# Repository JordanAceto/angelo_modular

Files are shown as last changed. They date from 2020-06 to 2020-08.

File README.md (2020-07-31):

## Custom 5u format modular synth with 12 modules

pics

### Contains:
- VCO with 5-pulser waveshaper
- VCO with two sub-oscillators
- VCO with LFO range switch
- Voltage controlled wavefolder plus ring-modulator
- Voltage controlled filter with swapable filter-core plug-in boards
- Dual late MS20 style voltage controlled filter
- MIDI to CV plus audio input processor
- Dual 3-input DC coupled mixer
- Modulation source with voltage controlled LFO, sample-and-hold, and white noise source
- Dual Serge style slope generator
- Dual ADSR
- Dual VCA
- +/- 12 volt power supply

### User manuals can be found in the `/user_manuals/` directory. This directory also contains a document outlining any pcb kludges or changes to the current system.

### Documentation for the pcbs is in the `/pcb_docs/` directory

#### Documentation for each pcb consists of the following:
- A very brief README outlining the basics of the pcb

- `/construction_docs/` subdirectory which contains:
  - Gerbers for the circuit board
  - An interactive BOM which can be opened in a web browser
  - A pdf schematic

- `/kicad_docs/` subdirectory which contains the files needed to edit the schematic and pcb layout with kicad

- `/pics/` subdirectory which contains a few rendered pictures of the pcb for reference

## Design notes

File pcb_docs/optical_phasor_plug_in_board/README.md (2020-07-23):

# Optical Phasor Plug-In Board

Small 6 stage optical phase shifter PCB, designed to plug into a larger motherboard.

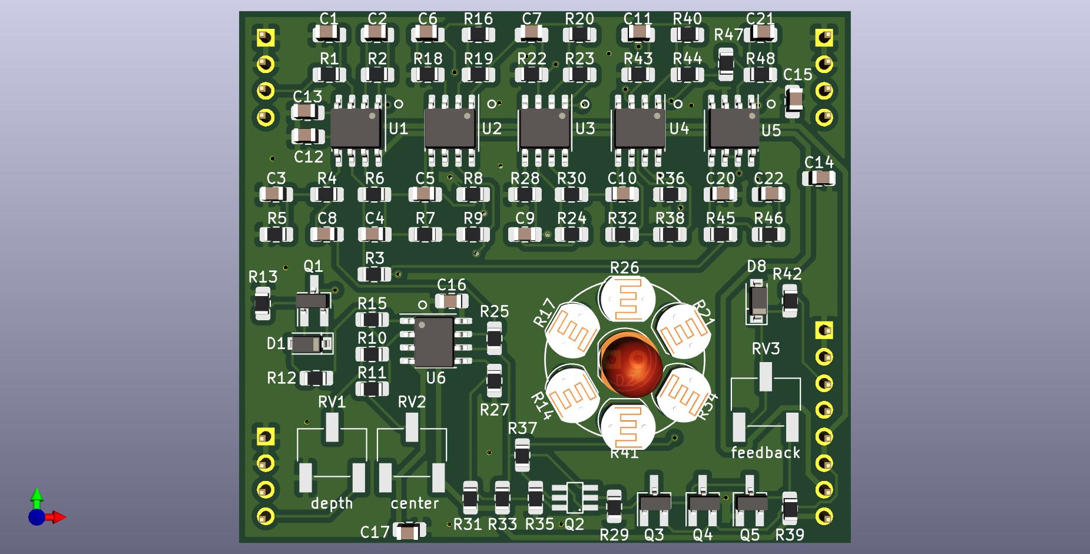
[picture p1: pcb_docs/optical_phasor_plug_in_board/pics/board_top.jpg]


## Details

The main circuit is based on the famous Mutron phasor circuit with the addition of voltage controlled feedback. This PCB includes the audio path and CV inputs for frequency and feedback, but does not include any modulation sources.

The intended use for this board is to plug in to a larger motherboard which contains slots for two of these phasor boards, as well as modulation sources, panel controls, and input/output routing. This motherboard could accept different filter boards sharing this footprint and header layout, for realizing stereo effects of various flavors.

## Inputs

-Audio in: dry audio input to be phase shifted.

-Frequency CV in: 0 volts to +2.048 volts, higher voltage = higher sweep.

-Feedback CV in: 0 volts to +2.048 volts, higher voltage = more feedback.

## Outputs

-Audio out: phase shifted audio output.

## Power Supply Requirements

A bipolar 12 volt power supply capable of supplying 50mA is needed. This will typically come from the motherboard.

## Note About The Light Dependent Resistors

Low on resistance and high off resistance are desirable if a wide sweep range is wanted. Slow/fast response is up to personal taste.

The choice of LED has a large impact on sweep depth. Diffused green LEDs were found to produce good results, but feel free to experiment.

The LED and surrounding LDRs should be protected from ambient light under an opaque cover.

## Calibration

-RV1 (depth trim): trims the depth of incoming frequency CV signals. Turn CW for greater depth and CCW for less depth. Adjust to taste.

-RV2 (center trim): trims the center frequency of the phase shifter. Turn CW for higher center frequency and CCW for lower center frequency. Adjust to taste.

-RV3 (feedback trim): trims the maximum amount of feedback. Turn CW for more maximum feedback and CCW for less maximum feedback. Exercise caution when adjusting this, as extreme settings can result in loud oscillations which could damage your ears or speakers if you are monitoring the sound with a loud amplifier. If you set this trimmer to be right on the edge of oscillation when about +2 volts is applied to the feedback CV input then make sure to sweep the frequency through its entire range, as a setting that doesn't squeal at certain frequency settings may squeal at other settings.

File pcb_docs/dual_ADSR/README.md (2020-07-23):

# Dual ADSR module.

## ADSRs are generated digitally using an stm32 microcontroller. This module is split into three main components:

- The stm32 breakout board contains the pcb with the stm32 microcontroller.

- The ADSR carrier board holds the potentiometers and has a port for the stm32 breakout board.

- The firmware directory has an STM32CubeIDE project structure with the current code. Good starting points to check out the code are in `/firmware/Core/ADSR_lib` and `firmware/Core/Src/main.c`

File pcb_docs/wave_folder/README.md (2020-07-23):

# Wavefolder

The wavefolder is a unique waveshaping circuit that creates "folded" versions of sloping input waveforms.

CV inputs for folds, shape, and offset are included.

A bonus ring-modulator circuit is included, to maintain compatability with the old module.

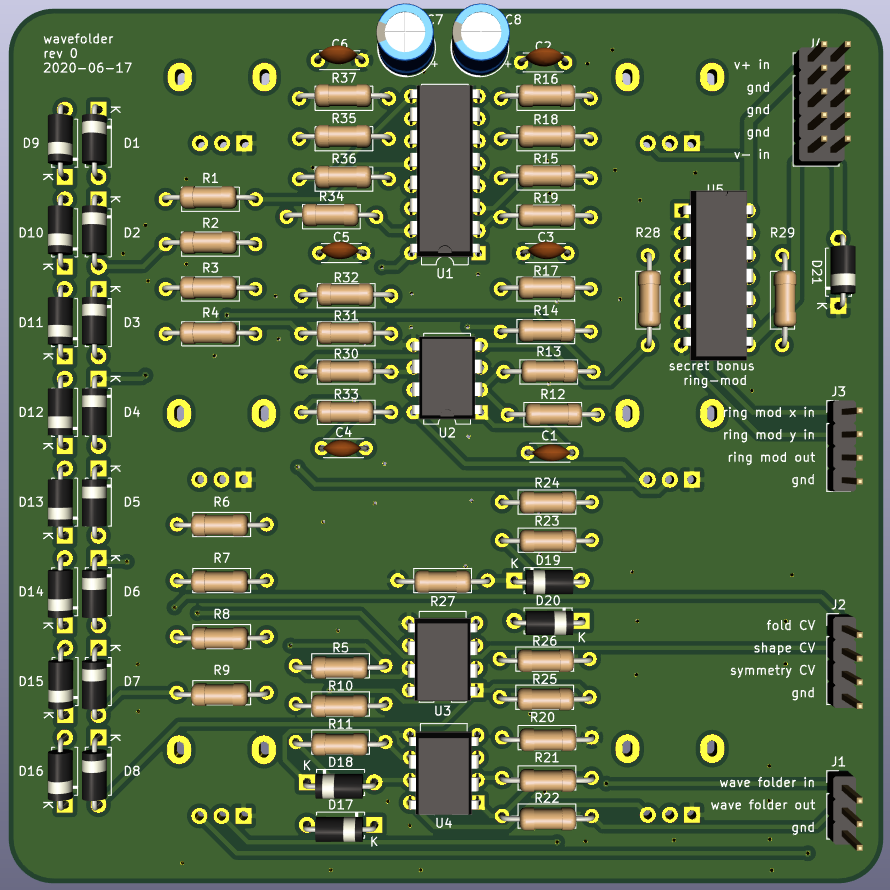
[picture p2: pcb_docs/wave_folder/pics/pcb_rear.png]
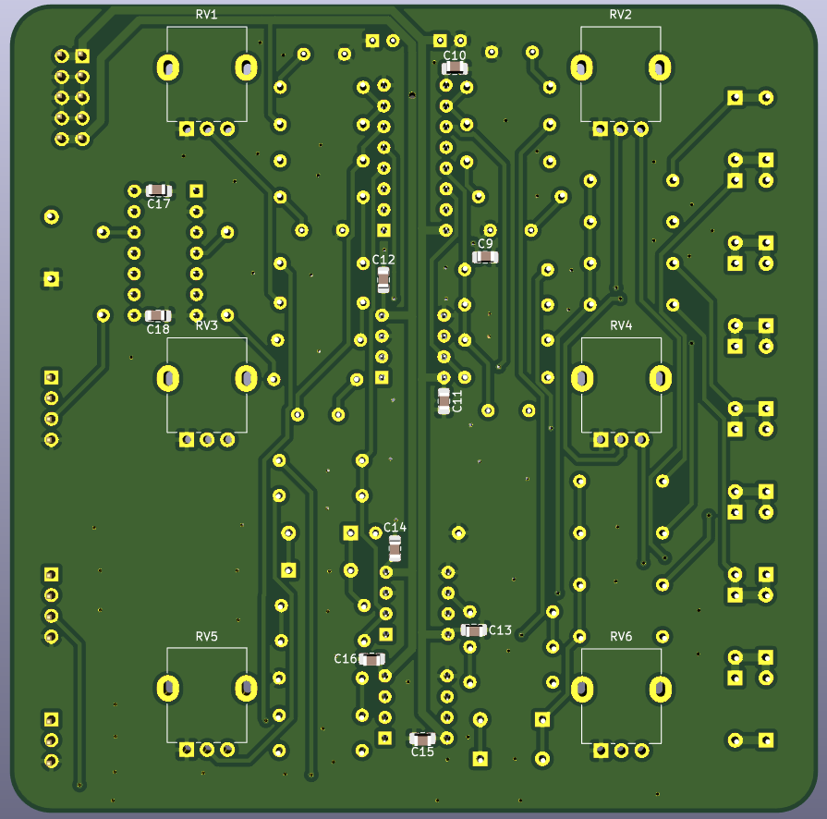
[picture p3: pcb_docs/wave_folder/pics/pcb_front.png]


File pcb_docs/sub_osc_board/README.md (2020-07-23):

# Sub-Oscillator auxilliary waveshaper

Small aux waveshaper pcb intended to be used with the oscillator carrier boards.

Contains two sub-oscillator circuits cascaded in series, for -1 octave and -2 octaves. Triangle, sawtooth, and variable width pulse waves are available for all octaves.

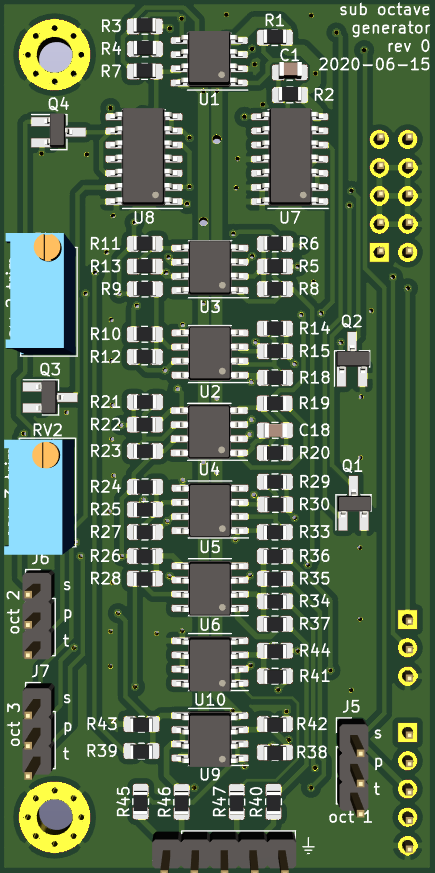
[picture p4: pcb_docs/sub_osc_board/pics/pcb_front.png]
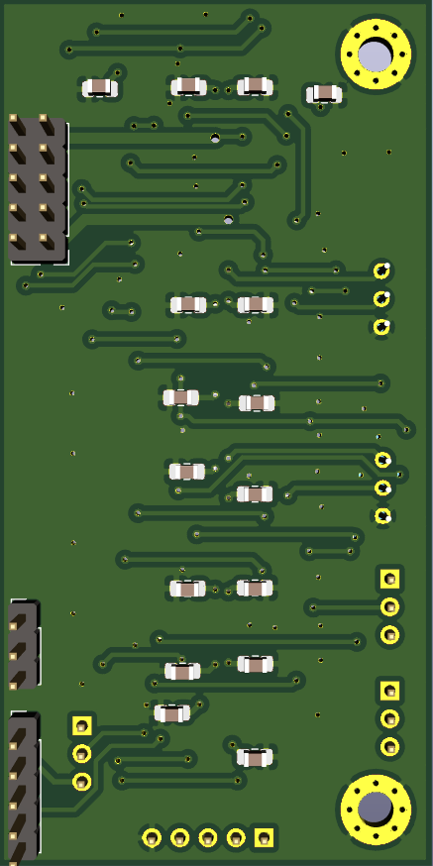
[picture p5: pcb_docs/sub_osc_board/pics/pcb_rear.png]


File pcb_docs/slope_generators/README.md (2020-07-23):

# Slope Generators

PCB with two Serge-stlye slope generators

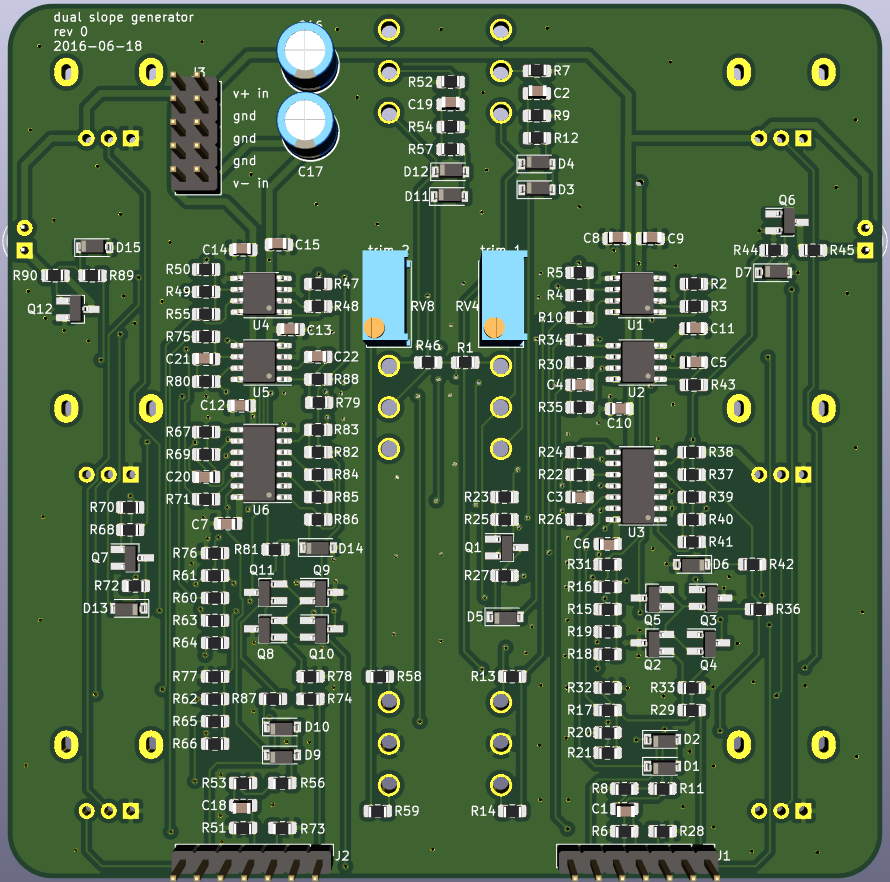
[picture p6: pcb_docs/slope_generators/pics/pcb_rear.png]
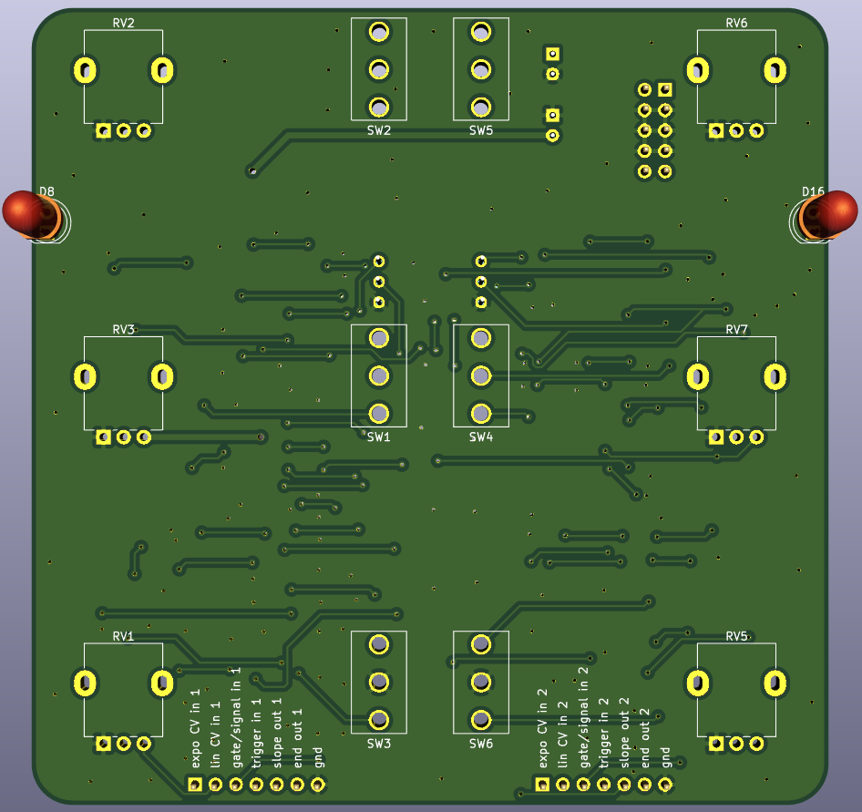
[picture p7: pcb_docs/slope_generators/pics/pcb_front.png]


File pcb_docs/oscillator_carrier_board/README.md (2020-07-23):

# VCO carrier board

Motherboard pcb for oscillators. Contains a port for a VCO core and a port for auxilliary waveshapers, and an octave switch.

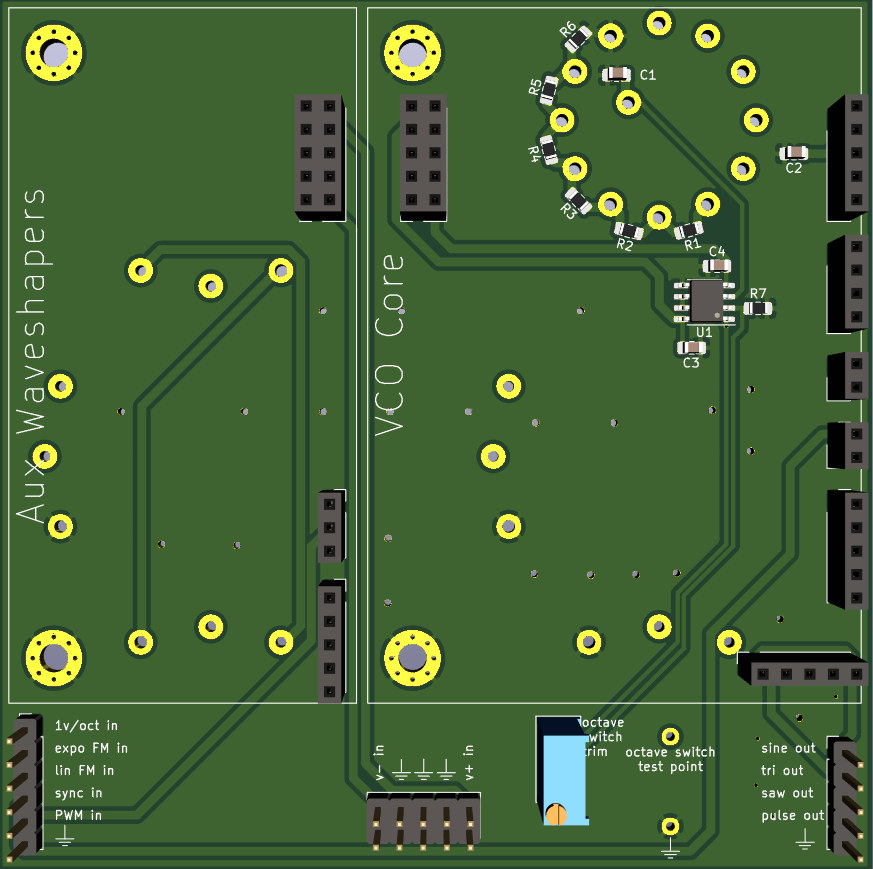
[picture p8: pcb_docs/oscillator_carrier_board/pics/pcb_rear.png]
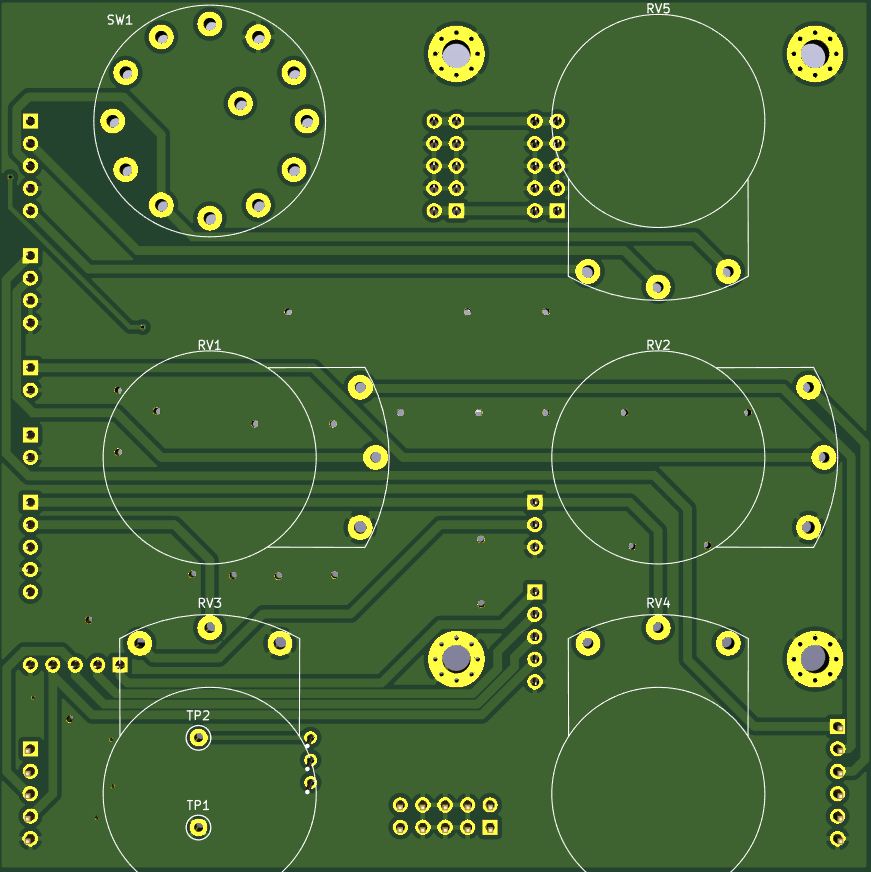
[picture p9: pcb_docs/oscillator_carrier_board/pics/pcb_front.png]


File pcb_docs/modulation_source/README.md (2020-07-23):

# Modulation Source

PCB with a voltage controlled LFO, sample-and-hold, and white noise source.

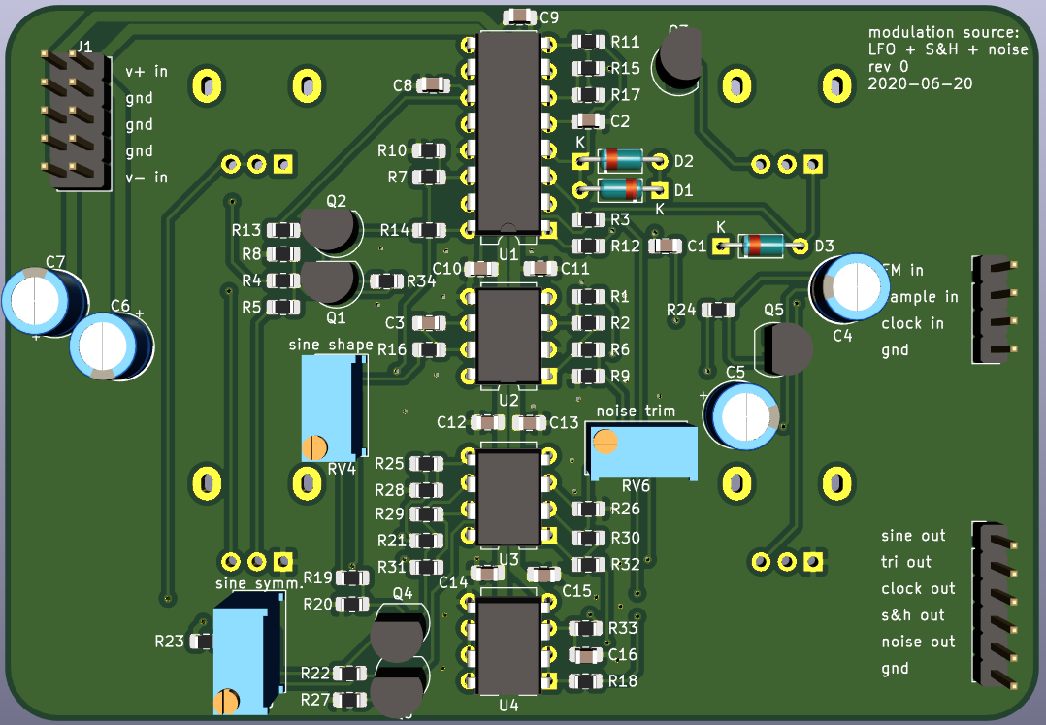
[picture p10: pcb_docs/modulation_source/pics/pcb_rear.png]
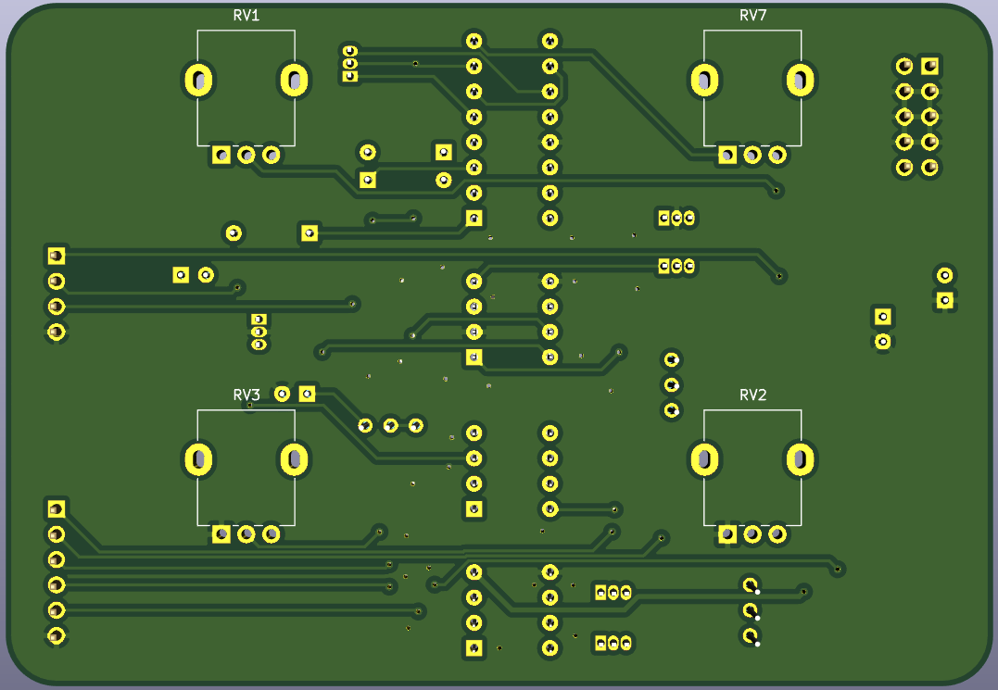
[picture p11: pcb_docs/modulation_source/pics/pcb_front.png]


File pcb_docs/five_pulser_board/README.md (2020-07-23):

# 5-Pulser auxilliary waveshaper board

Small aux waveshaper pcb intended to be used with the oscillator carrier boards.

The 5-pulser is a unique pulse shaper that takes in sloping wave inputs and outputs a stream of between 1 and 5 pulses. The typical input is sawtooth waves.

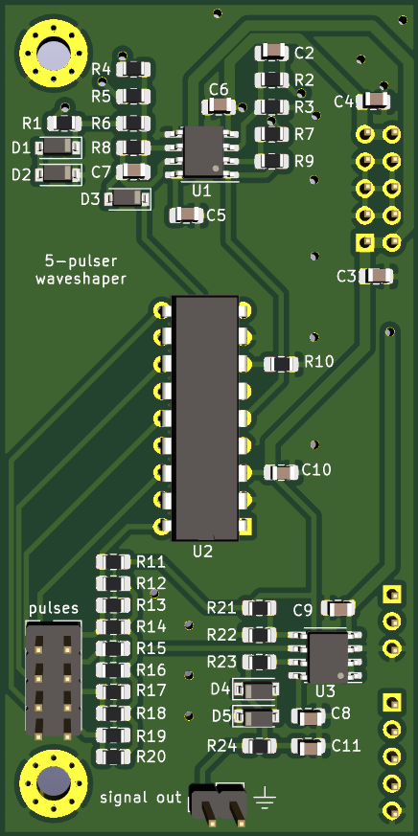
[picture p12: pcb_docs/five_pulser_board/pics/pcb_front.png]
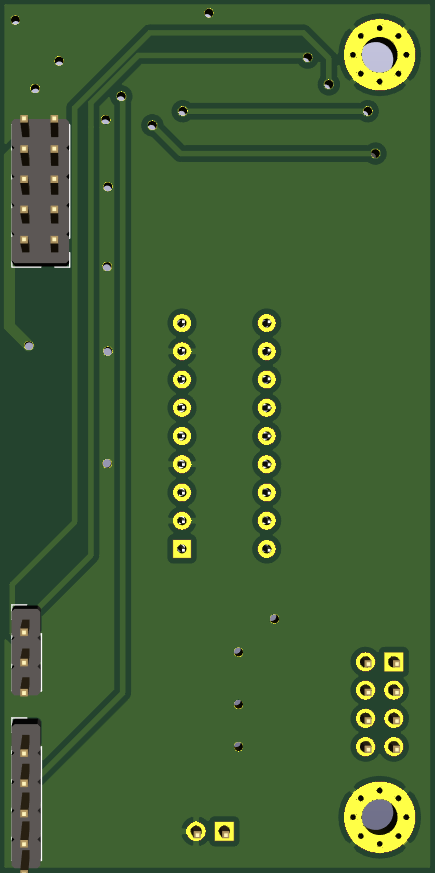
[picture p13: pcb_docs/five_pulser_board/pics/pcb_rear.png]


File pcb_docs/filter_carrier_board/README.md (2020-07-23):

# Voltage Controlled Filter carrier board

PCB which houses various VCF "plug-in" boards. This pcb contains a 3-input signal mixer and 3-input CV mixer, as well as inputs and outputs for the plug-in board port. 

The plug-in boards must conform to the electrical and mechanical interface defined by this pcb. 

Plug-in boards must accept a CV range of 0v to +2.048v, and a feedback CV range of 0v to +2.048v.

See the CEM3320 VCF and optical phasor documents for examples of plug-in boards.

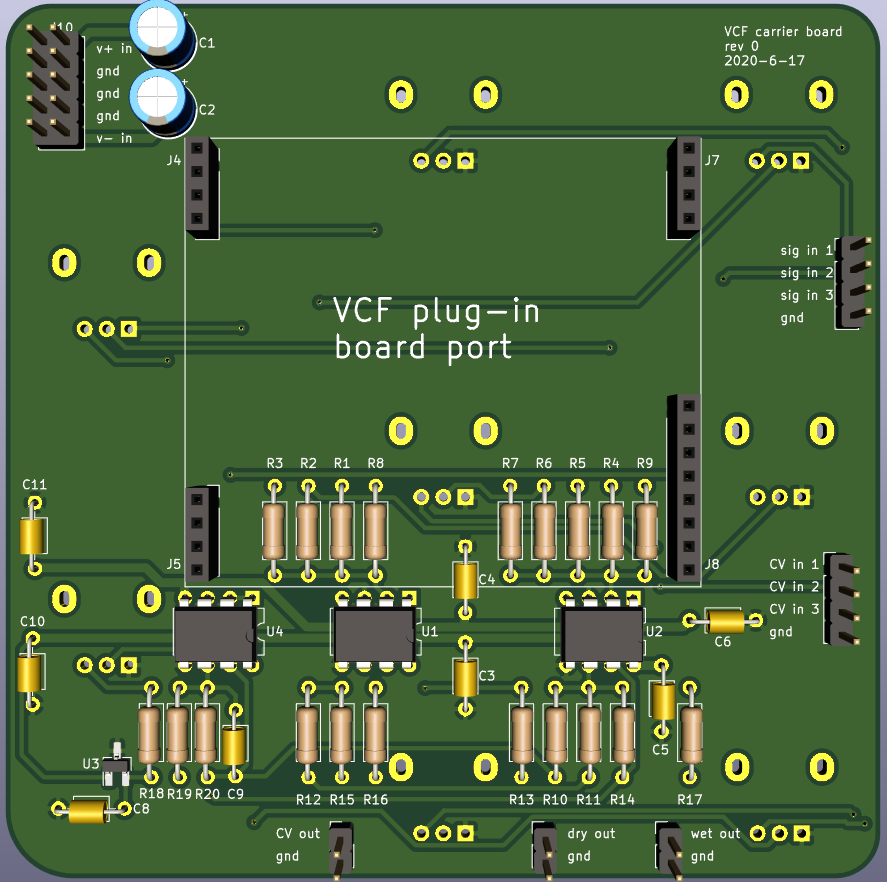
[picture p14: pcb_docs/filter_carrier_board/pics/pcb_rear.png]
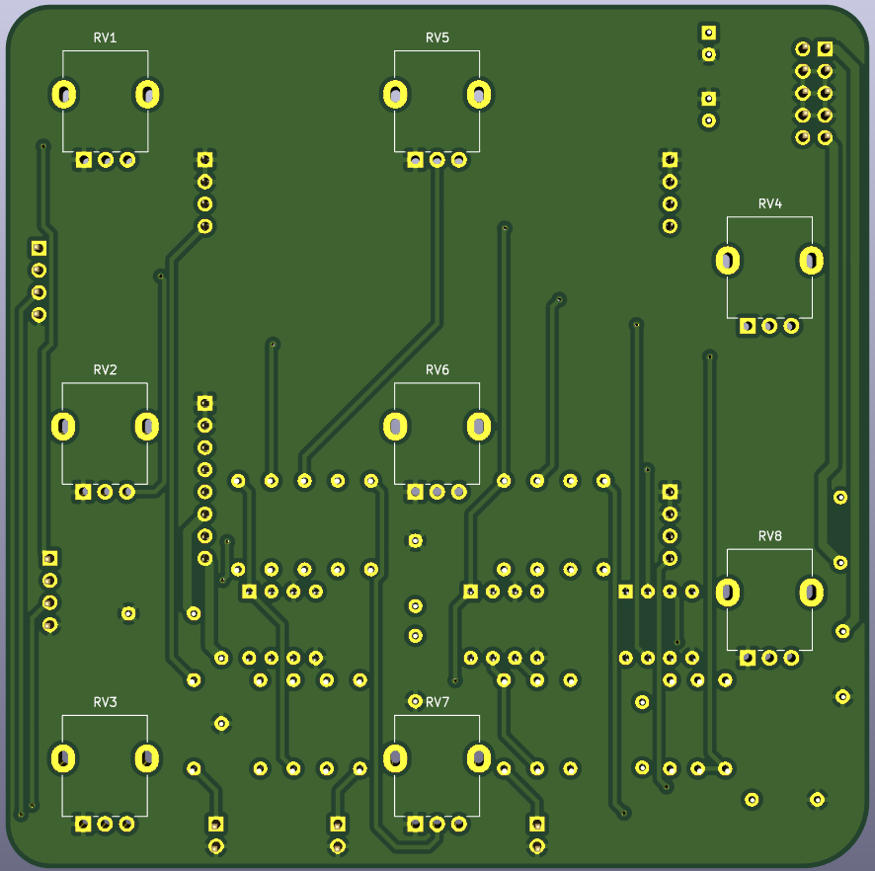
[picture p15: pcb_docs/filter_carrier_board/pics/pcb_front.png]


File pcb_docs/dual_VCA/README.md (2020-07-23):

# Dual linear VCA

PCB with two independendent SSM2164 linear Voltage Controlled Amplifiers.

CV range: 0 volts to +5 volts. Maximum attenuation at 0 volts and unity gain at +5 volts.

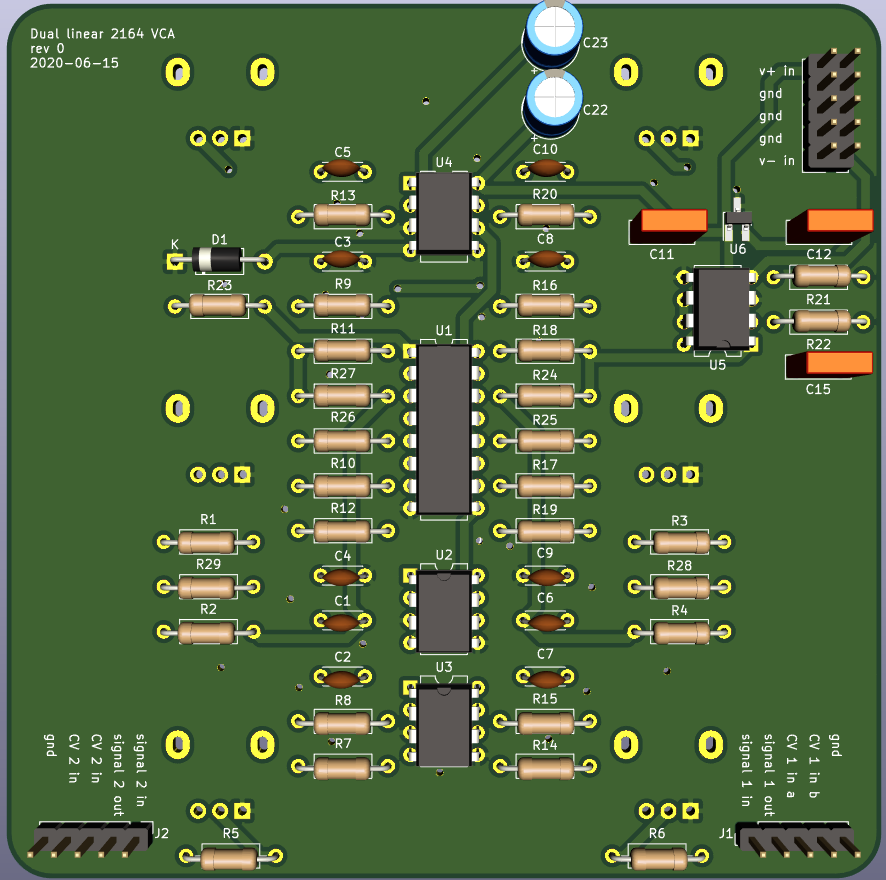
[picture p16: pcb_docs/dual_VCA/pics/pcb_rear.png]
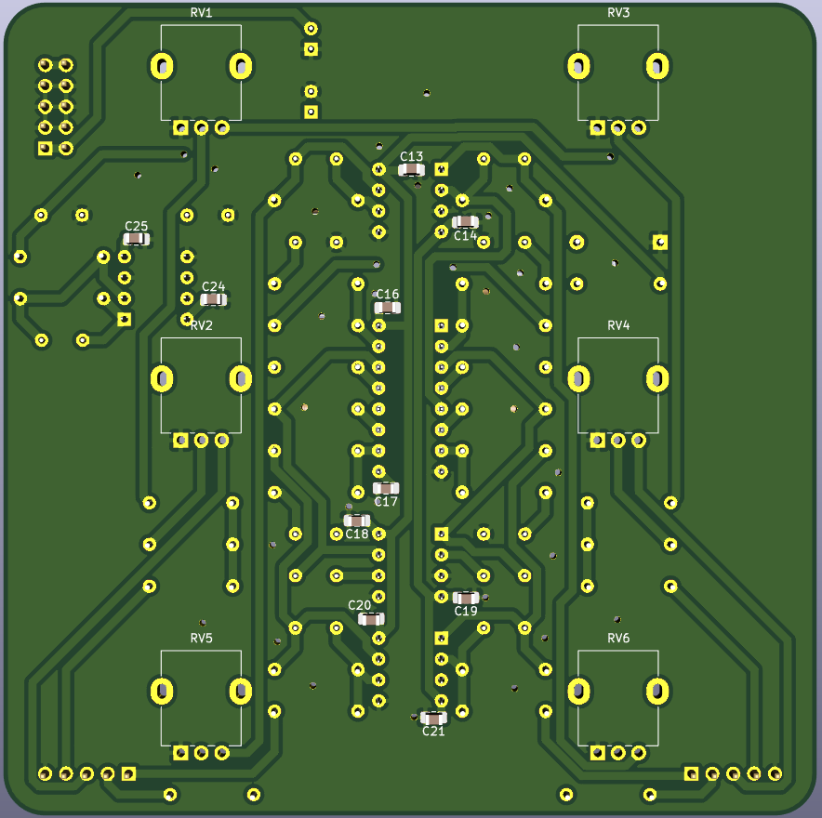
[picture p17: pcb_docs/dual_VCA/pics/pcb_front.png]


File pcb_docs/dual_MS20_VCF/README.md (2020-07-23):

# Dual MS20 style Voltage Controlled Filter

PCB with two independendent late MS20 style VCFs, one configured as a high-pass filter and one configured as a low-pass filter.

An extra summing amplifier is provided to create a parallel HPF/LPF response. Series HPF into LPF response is easily achived with switching jack normalization.

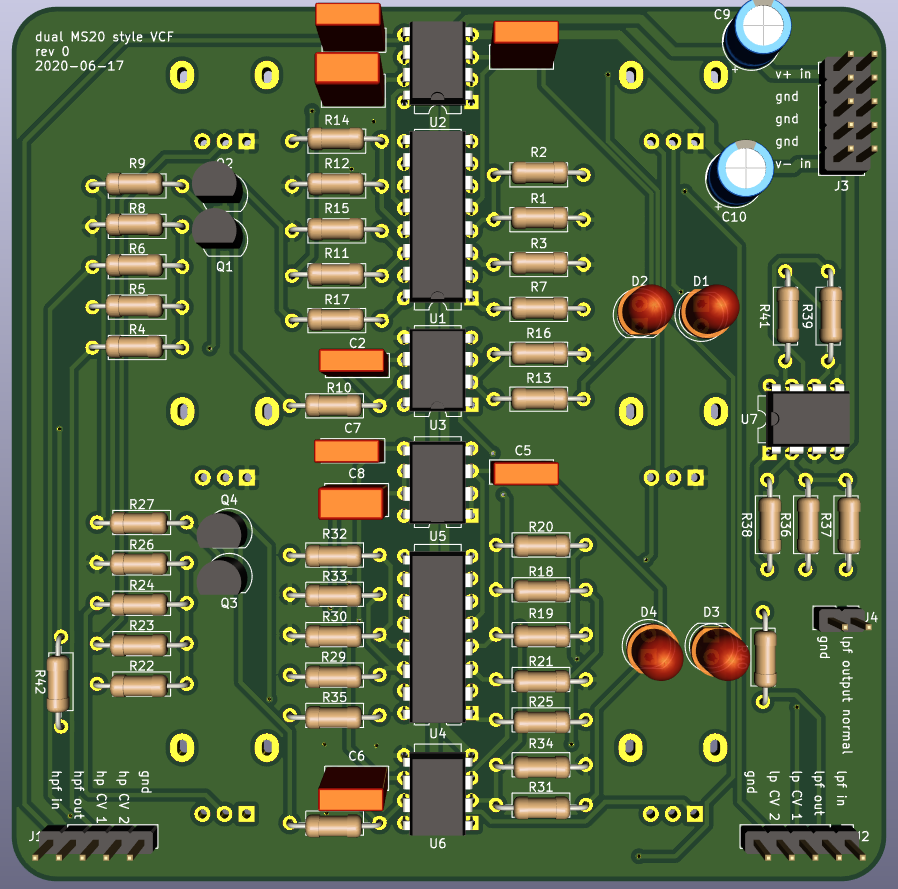
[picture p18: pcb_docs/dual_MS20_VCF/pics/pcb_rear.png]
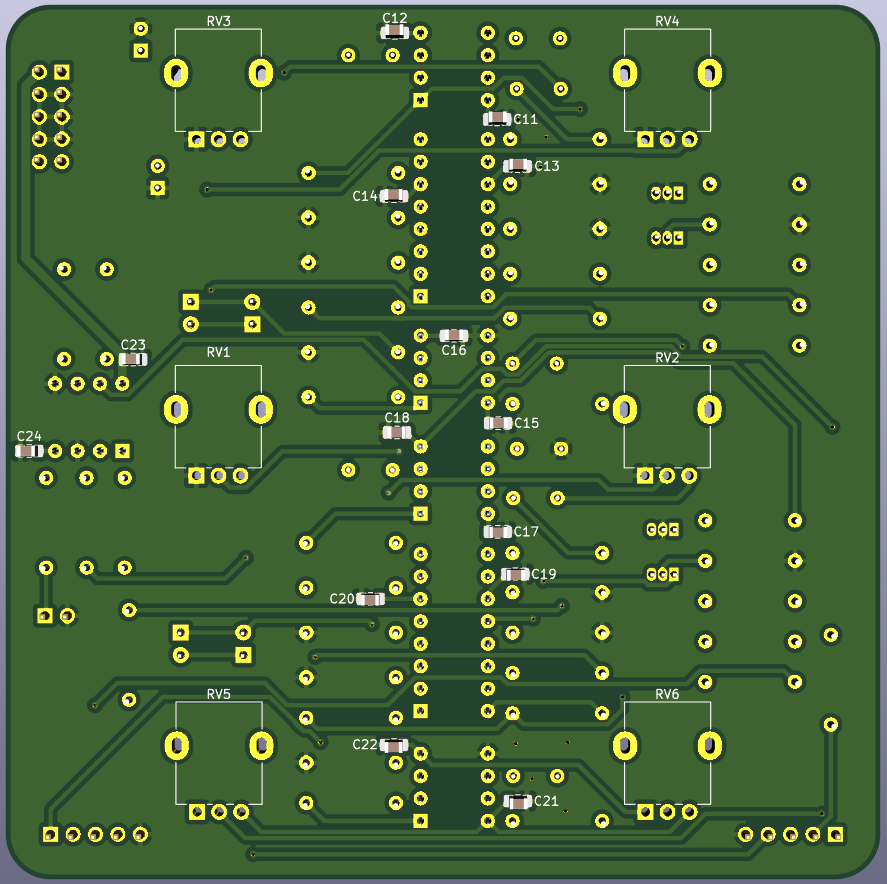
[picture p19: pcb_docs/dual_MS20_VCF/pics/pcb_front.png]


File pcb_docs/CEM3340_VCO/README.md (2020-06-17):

# CEM3340 based VCO PCB

## Features:
- Sine, Triangle, Sawtooth, and variable Pulse waves simultaneously available.
- All waveforms +/- 5vpp.
- Three 1 volt/octave inputs, linear FM, sync (choose hard or soft), and PWM modulation inputs.
- Onboard voltage regulators and reference voltage generators for stable tuning.
- Input voltage can be either +/- 12 volts DC, or +/- 15 volts DC.
- Designed to either plug into a separate carrier pcb with pots and jacks, or mount to a bracket and wire by hand. 

## A note about the pulse waveform:
 This design does not use the built in CEM3340 pulse generator. Instead, an typical opamp circuit is used for the Pulse wave output. This is to avoid the influence of PWM on the frequency of the oscillator, which has been reported to be a problem, especially with the AS3340 versions of the chip. The built in pulse generator is disabled by tying the output to ground through a resistor, and hardwiring a negative voltage into pin 5 which permanently sets the pulse width to zero percent.

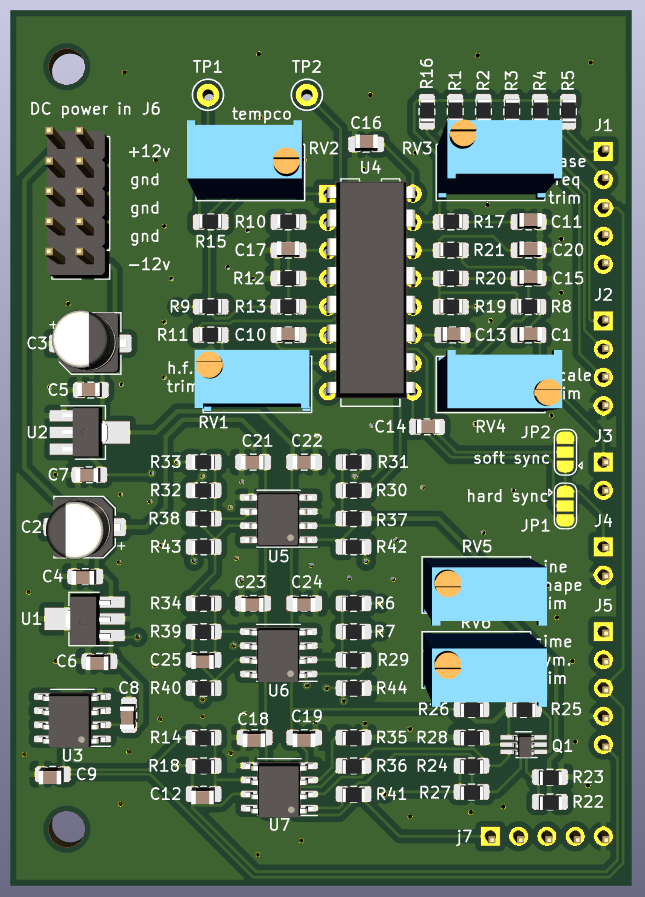
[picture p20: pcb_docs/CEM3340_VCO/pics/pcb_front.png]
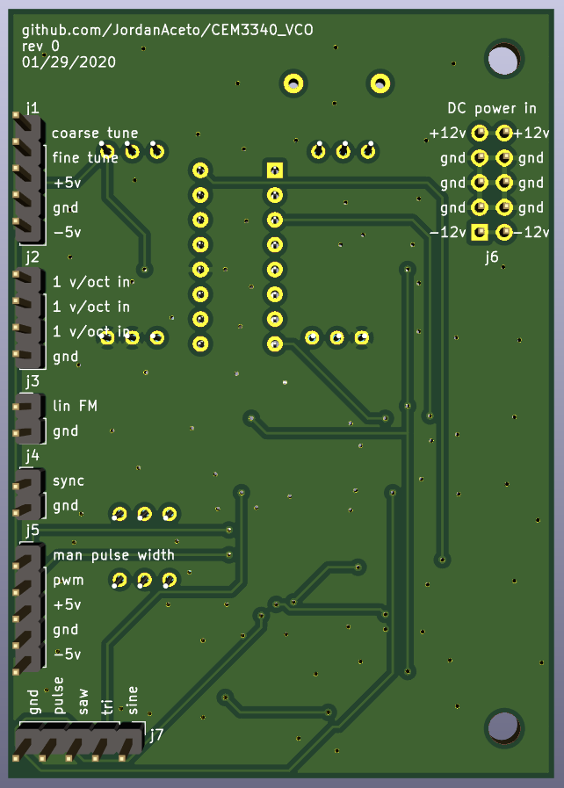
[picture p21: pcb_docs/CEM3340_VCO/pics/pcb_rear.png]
   

## License

### CC by 4.0

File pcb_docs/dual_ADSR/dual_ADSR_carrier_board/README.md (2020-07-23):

# Dual ADSR carrier board

ADSR motherboard with port for stm32 breakout board and two opamp low-pass filters.

The ADSRs are generated digitally on the stm32 breakout board, and filtered and amplified on this board.
 
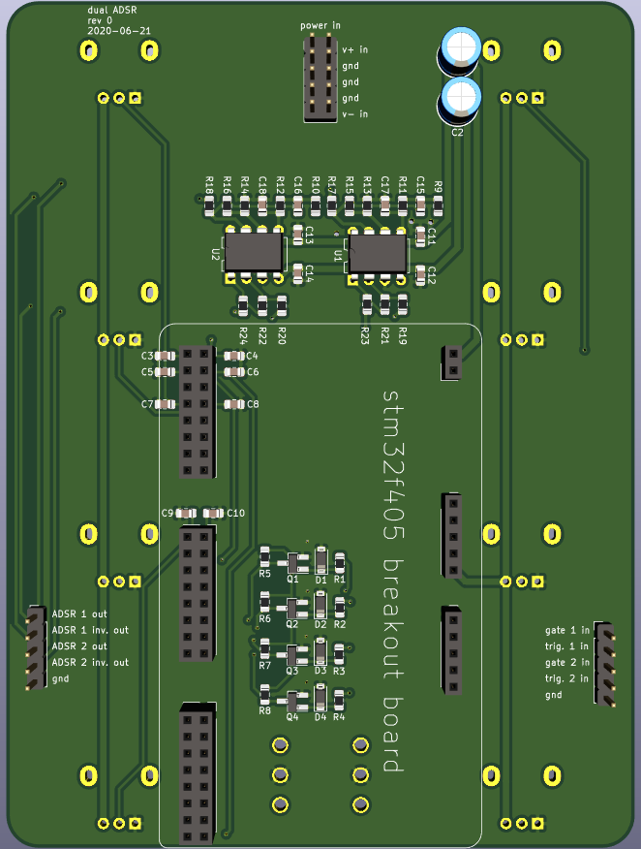
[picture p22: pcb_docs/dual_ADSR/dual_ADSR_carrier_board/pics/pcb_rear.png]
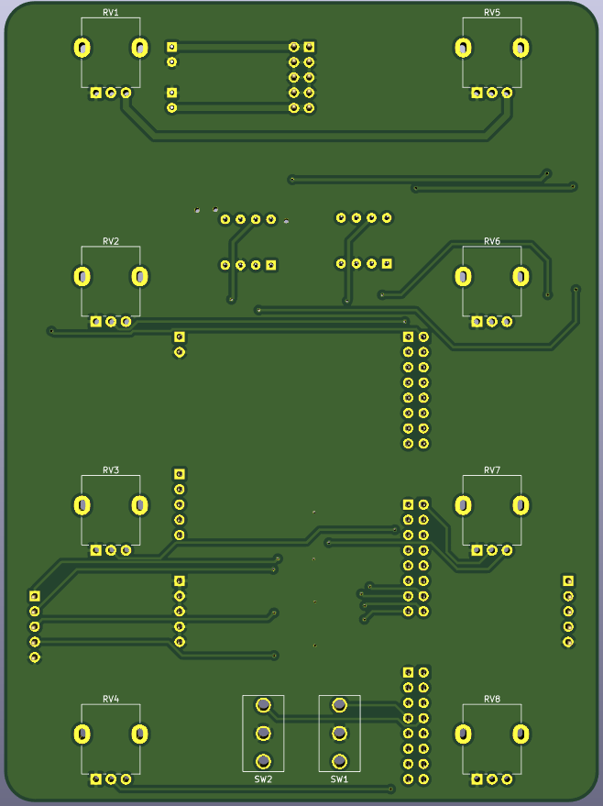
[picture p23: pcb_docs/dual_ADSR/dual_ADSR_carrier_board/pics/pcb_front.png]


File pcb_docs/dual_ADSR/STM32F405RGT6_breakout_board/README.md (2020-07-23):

# Breakout board for STM32F405

## Plugs into the ADSR motherboard, contains the stm32 microcontroller and 3.3 volt regulator.

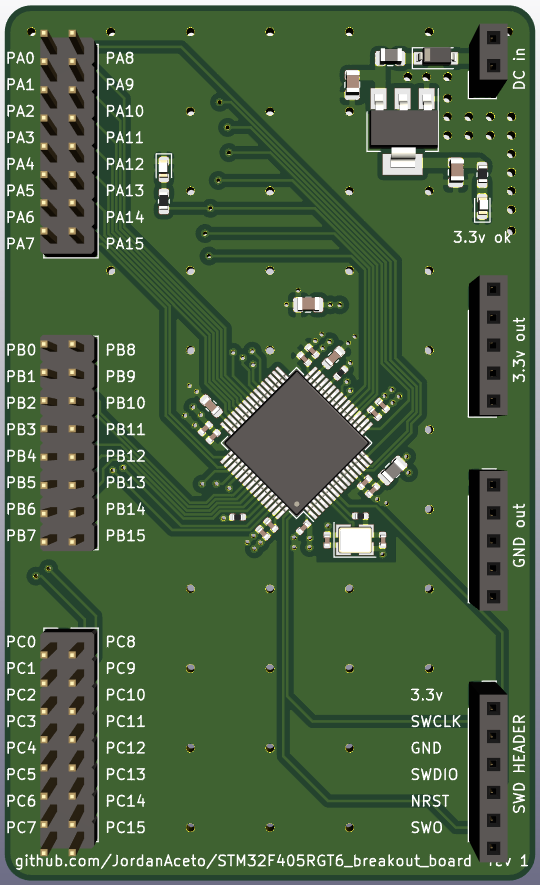
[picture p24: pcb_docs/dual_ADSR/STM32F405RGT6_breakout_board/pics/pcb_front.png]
pcb front
  pcb rear

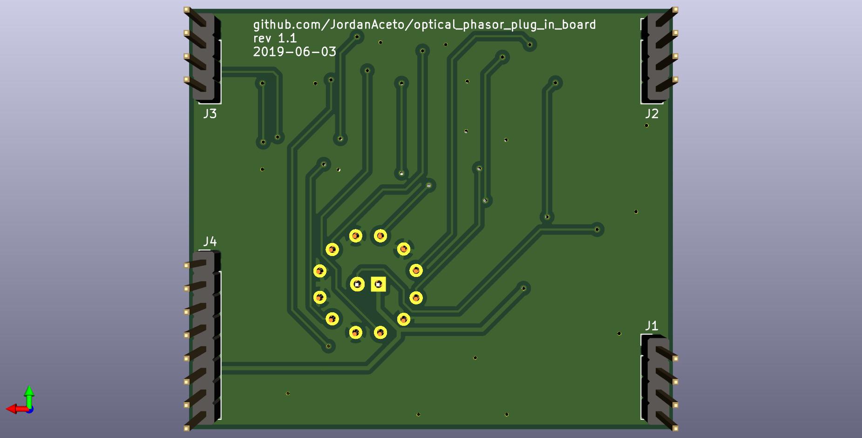
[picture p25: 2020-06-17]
pcb_docs/optical_phasor_plug_in_board/pics/board_bottom.jpg

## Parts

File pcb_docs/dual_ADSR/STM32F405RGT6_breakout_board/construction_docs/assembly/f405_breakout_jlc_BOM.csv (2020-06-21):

Designator | Quantity | Value | Footprint | LCSC Part #
C1, C4, C8, | 3 | 10uF | 0805 | C15850
C2, C3, C6, C7, C9, C10, C11, C12, C13, C14, | 10 | 100nF | 0402 | C1525
C5, | 1 | 10nF | 0402 | C15195
C15, C16, | 2 | 2.2uF | 0603 | C23630
C17, C18, | 2 | 12pF | 0402 | C1547
D1, | 1 | B5819W | SOD-123 | C8598
D2, | 1 | power_LED | 0603 | C2286
D3, | 1 | user_LED | 0603 | C72043
FB1, FB2, | 2 | 100R @ 100MHz | 0805 | C1015
HSE1, | 1 | 16MHz | SMD-3225_4P | C13738
R1, R3, | 2 | 2k2 | 0603 | C4190
R2, R4, | 2 | 10k | 0402 | C25744
R5, | 1 | 100 | 0402 | C25076
U1, | 1 | AMS1117-3.3 | SOT-223 | C6186
U2, | 1 | STM32F405RGT6 | LQFP-64_10.0x10.0x0.5P | C15742

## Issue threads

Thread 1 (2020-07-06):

MS20 VCF frequency and CV attenuator pots positions are swapped

JordanAceto, 2020-07-06:
The positions of the CV attentuators and manual frequency controls are swapped on the pcb layout, relative to the existing panel layout.

Temporary solution to avoid respinning the boards right away: bend the potentiometer legs up instead of soldering them to the board, and run jumper wires.

Better solution: adjust the pcb layout with the correct placement of the pots.

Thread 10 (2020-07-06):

sub-oscillator 2-octave-down signal doesn't always cleanly divide

JordanAceto, 2020-07-06:
Occasionally the second sub-oscillator does not cleanly divide. I am not sure exactly what is happening yet, the triangle wave goes to 1/2 amplitude and the sawtooth wave gets a large discontinuity in the middle of the ramp.

Touching the pcb with a finger usually causes the bad behavior to occur, although not 100% consistently.

Please investigate this and come up with a cause and solution.

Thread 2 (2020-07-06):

VCO carrier board potentiometer holes are too small

JordanAceto, 2020-07-06:
I think I took the radius as the diameter or something, all the holes for the alpha RV24AF-40-15R1-B100K-3LA pots are too small for the pins.

Temporary solution before a board respin: file/cut/trim the pot pins so they fit in the holes.

Better solution: edit the RV24AF-40-15R1-B100K-3LA footprints so that the holes are the correct size.

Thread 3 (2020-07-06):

5-pulser manual PWM signal is shorted to ground through a via

JordanAceto, 2020-07-06:
D'oh.

Temporary solution: cut/jumper the pcb.

Better solution: move the stupid via and respin the boards.

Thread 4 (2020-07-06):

5-pulser and sub-octave power pins are reversed

JordanAceto, 2020-07-06:
Both the 5-pulser and sub-octave-generator power headers are reversed. These are supposed to plug into the VCO carrier board and get their power from it.

Temporary solution: cut/jumper the pcbs.

Better solution: edit the boards to have the correct power supply header orientation.

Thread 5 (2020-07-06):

modulation-source timing cap has an inappropriate footprint

JordanAceto, 2020-07-06:
The 220nF timing cap for the modulation-source LFO is 0805. There is not a great selection of 220nF 0805 caps in C0G/NP0/nice film.

Temporary solution: tack a big film cap across the opamp legs and do not fit the 0805 spot.

Better solution: edit the pcb to have a box/film cap footprint so that easy to find and cheap timing caps can be used.

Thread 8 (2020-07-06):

sub-oscillator outputs are a bit glitchy

JordanAceto, 2020-07-06:
There are large spikes in the sub-oscillator waveforms. These originate from the CEM3340 VCO sawtooth wave, which exhibits a narrow spike going above +5 volts on the rising edge.

Experiment with filtering or clipping to see if this can be improved.

JordanAceto, 2020-08-12:
Small capacitors were added in parallel to the feedback resistors for the offending waveforms on the physical pcb. This helped a bit and has been noted in the pcb_kludges document with the manuals. The waveforms are not perfect, but they sound good.

Closed 2020-08-12.

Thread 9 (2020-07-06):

sub-oscillator trim pots depend on the raw power supply voltage

JordanAceto, 2020-07-06:
These would be more stable if they relied in a derived sub-regulated supply.

This is not mandatory to fix, but if a pcb respin is done you might as well add a stable +5 volt sub regulator to the board for the trimpots to reference.

JordanAceto, 2020-08-07:
The circuit is fine the way it is, I was getting a little reference-happy for a while there. The power supply is solid and this isn't something that needs to be re-calibrated. Issue closed.

Closed 2020-08-07.

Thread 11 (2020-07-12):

dual ADSR DAC outputs never make it to opamp filters

JordanAceto, 2020-07-12:
Somehow in my stupidity the DAC outputs from the stm32 breakout board were never routed to the resistor inputs of the opamp low pass filters.

For now I'll just jumper a wire from the resistors to the pins, but in the future this should be corrected.

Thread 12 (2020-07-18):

oscillator carrier board should have another 1v/oct input

JordanAceto, 2020-07-18:
There should be at least two 1v/octave inputs, in case the user wants to add another input jack or provide normalization behind the panel.

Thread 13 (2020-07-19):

MS20 VCF ports could be swapped

JordanAceto, 2020-07-19:
The ports for wiring the HPF and LPF sides from the pcb to the jacks would be more ideal if their positions were swapped: with the current panel layout, all the HPF wires need to cross over from the left of the pcb to the right of the panel, and vice versa for the LPF wires.

This is not a huge issue, but if a new pcb rev happens, it would be nice to swap the positions of the ports to make the panel wiring tidier.

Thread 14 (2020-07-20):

VCA CV in silkscreen is unclear

JordanAceto, 2020-07-20:
The silkscreen for the CV inputs to the VCA are unclear: one of the CV inputs goes to an attenuator, and the other does not. The silkscreen does not differentiate the two, and the builder must figure it out with a multimeter or by visual inspection while doing the wiring.

To fix: change the silkscreen to show which of the CV inputs are attenuated and which are not.

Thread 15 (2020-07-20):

ADSR has some ADC inputs routed to wrong pins

JordanAceto, 2020-07-20:
I messed up the orientation of the stm32 breakout board ports, and routed some of the ADC inputs from the pots are wrong.

DECAY 1 is routed to a pin that is not connected to an ADC, same for RELEASE 1, DECAY 2, and RELEASE 2.

The other pins are ok.

A solution could be to re-route the pcb so that the pins go to the right places, but this module was designed to use up some stm32 breakout boards I had from before. I am out of those breakout boards now, so the real solution is to redesign the pcb so that it has the microcontroller on the main pcb, avoiding the breakout board altogether.

For now, I'll just cut some traces and re-route with jumper wires.

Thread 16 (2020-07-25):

VCO octave switch calibration is a bit fiddly

JordanAceto, 2020-07-25:
The trimmer for the VCO octave switch calibration covers too wide of a range. It would be easier to calibrate the octave switch if the trimpot range was restricted.

Choose new values around the U1A/RV6/R7 circuit so that it is easier to hone in on the octave switch calibration.

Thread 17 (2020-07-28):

ADSR ADCs are a little noisy

JordanAceto, 2020-07-28:
The ADCs on the stm32 breakout board for the ADSR are kind of noisy. When the times are very short they are noticeably modulated by noise.

This doesn't really cause a major problem in practice: When the attack time is set for around a millisecond, it doesn't sound bad if once in a while it jumps to two or three milliseconds. Maybe this even adds "character", who knows. when the times are set to long intervals, a few milliseconds here and there is completely irrelevant.

Still, it would be good to improve this. Experiment with averaging/filtering the ADC readings to improve the noise performance.

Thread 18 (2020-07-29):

Ring modulator circuit is not complete

JordanAceto, 2020-07-29:
In my infinite genius I never finished the circuit for the bonus ring-mod on the wavefolder pcb.

This ring-mod is made using an AD534 multiplier. The z1 pin must be connected to the output pin, and the z2 pin must be connected to ground for the circuit to behave as intended.

This has been fixed with a pcb kludge on the physical board.

If there is ever a new board revision for the wavefolder/ring-mod, for the love of god don't use an AD534 again. I had a few of these floating around in a random parts bin, and I used it here not knowing how expensive they are. Use a cheaper multiplier chip, or transformers, or anything besides this way-too-fancy part.

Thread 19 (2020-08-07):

Modulation source wastefully uses a hard-to-find FET

JordanAceto, 2020-08-07:
In the sample and hold section of the modulation source, the sample capacitor is buffered by a FET. However, there is 1/2 of a dual opamp that is sitting unused on the board. This opamp could be used to buffer the cap, and the FET could be eliminated. The through hole FET used is becoming scarce and expensive, so there is an incentive to eliminate it.

Consider incorporating this change in to a new board revision if one is ever done.

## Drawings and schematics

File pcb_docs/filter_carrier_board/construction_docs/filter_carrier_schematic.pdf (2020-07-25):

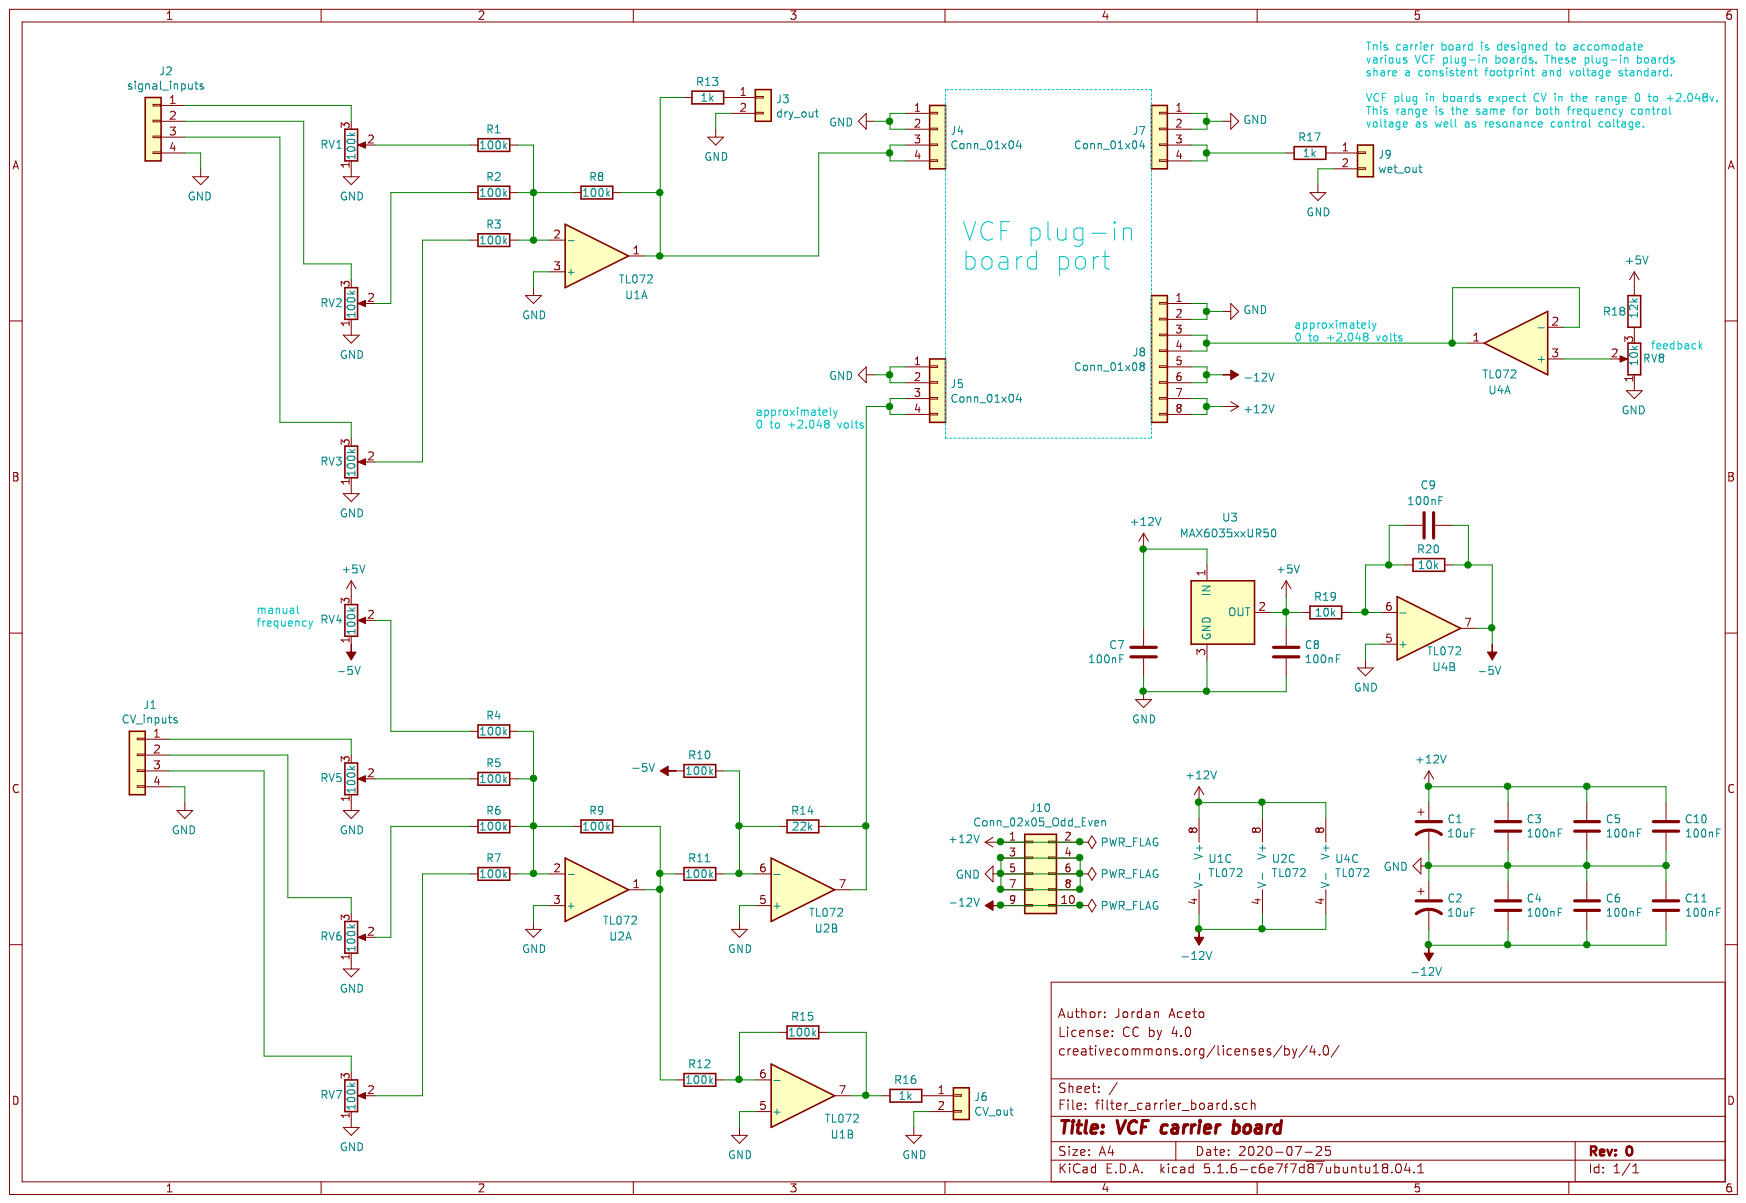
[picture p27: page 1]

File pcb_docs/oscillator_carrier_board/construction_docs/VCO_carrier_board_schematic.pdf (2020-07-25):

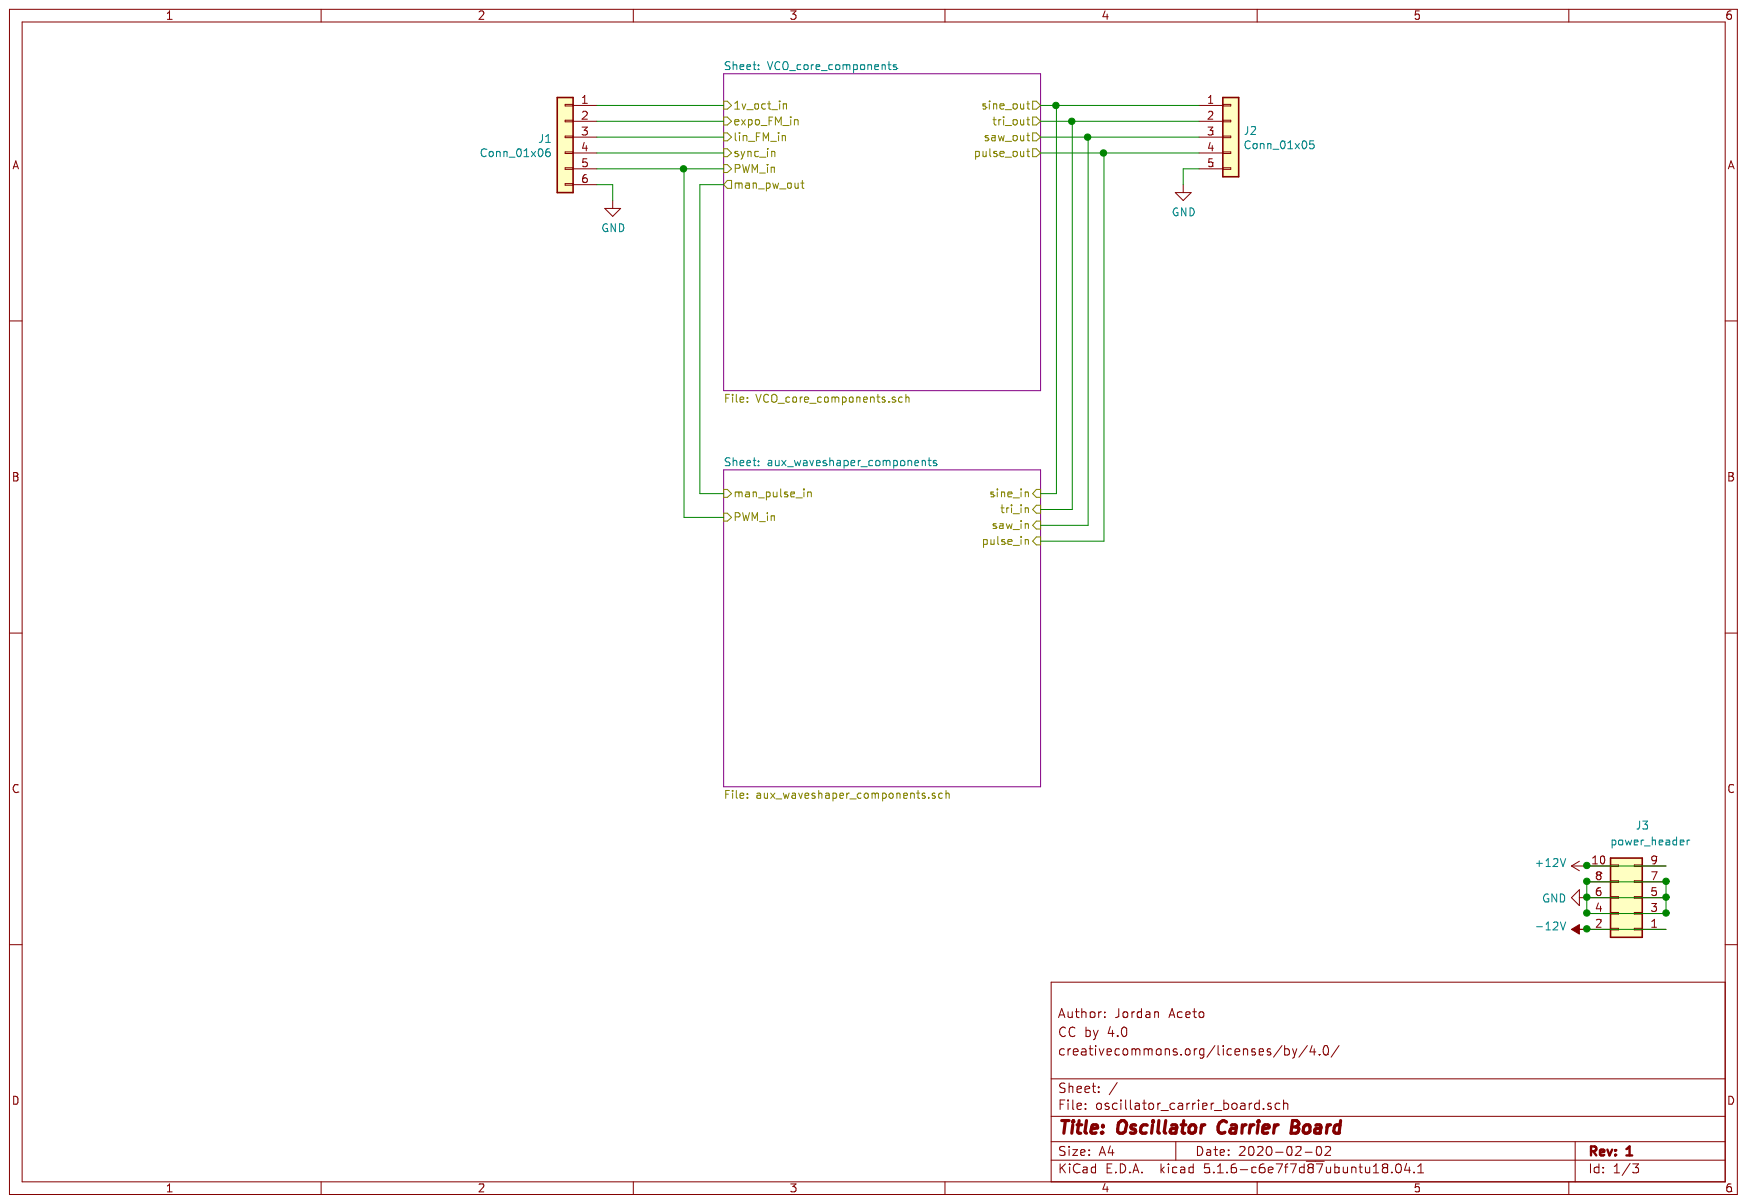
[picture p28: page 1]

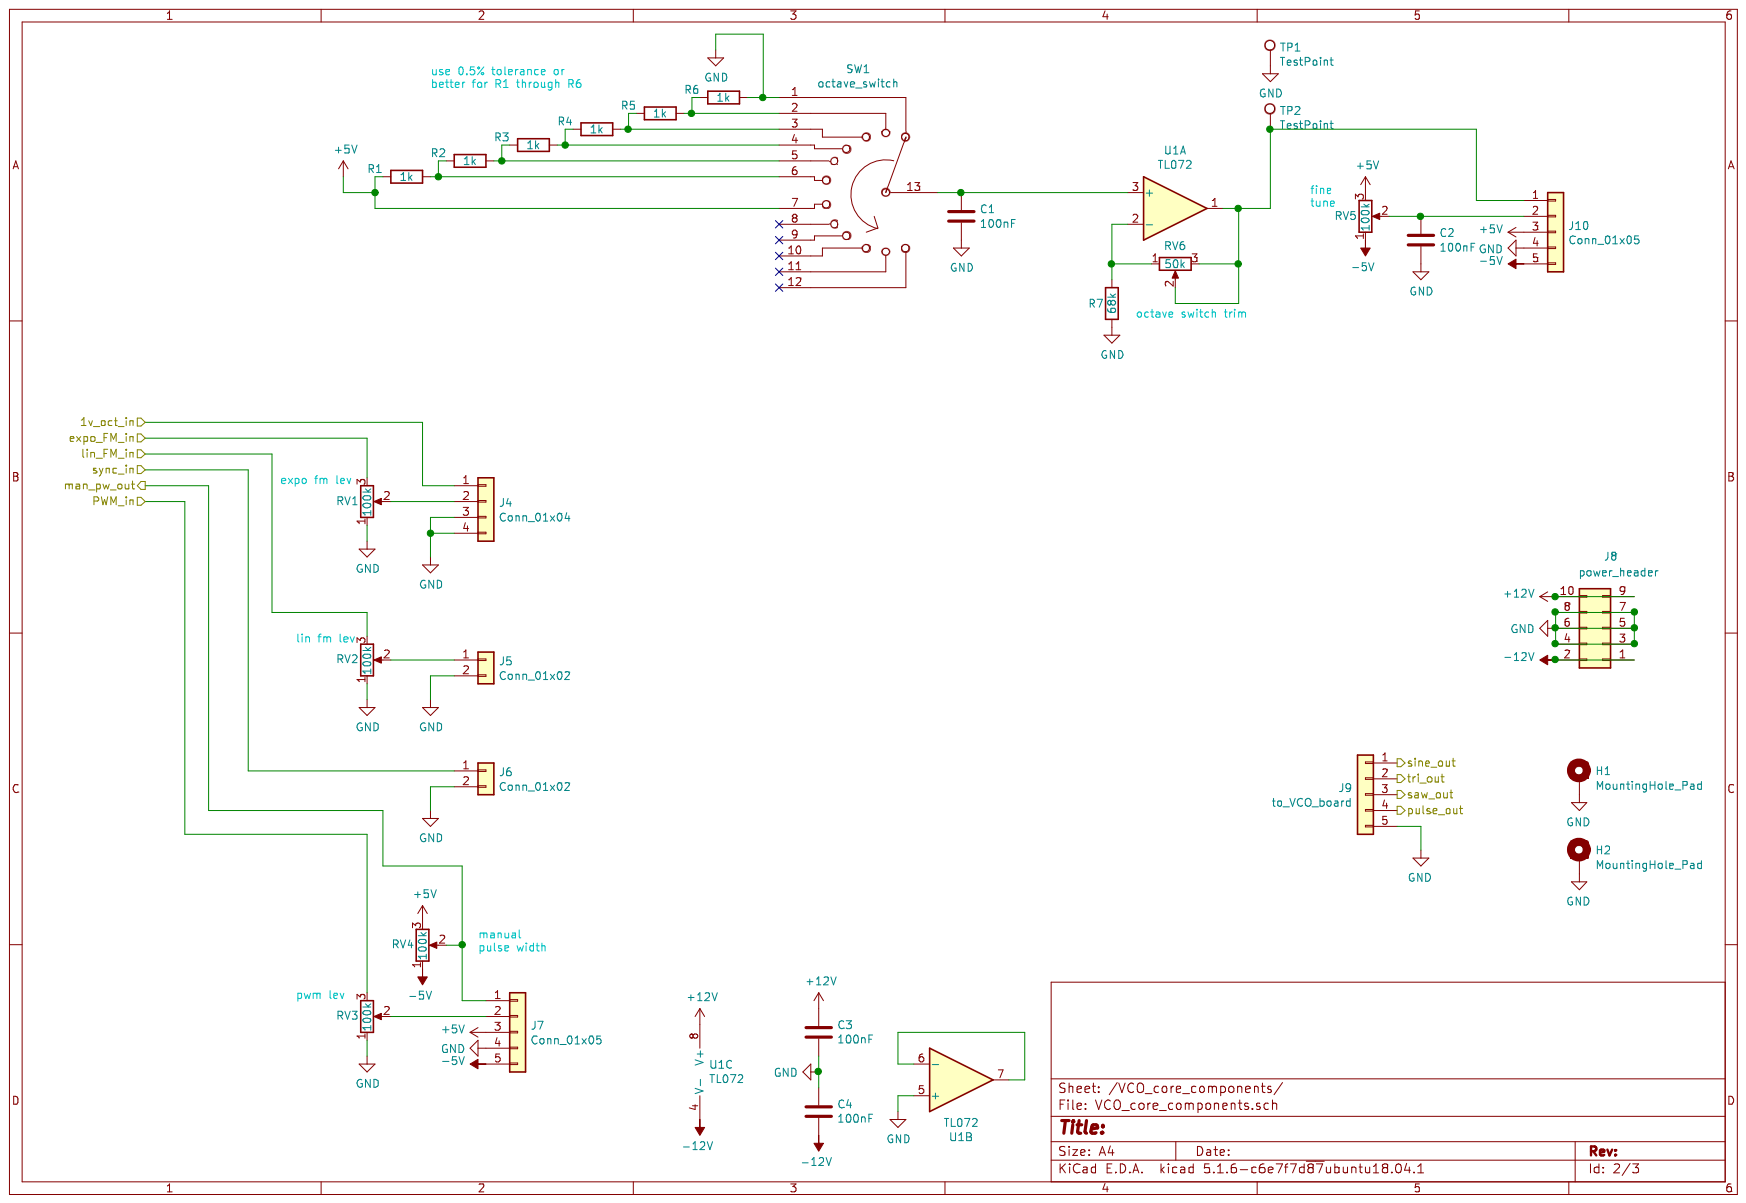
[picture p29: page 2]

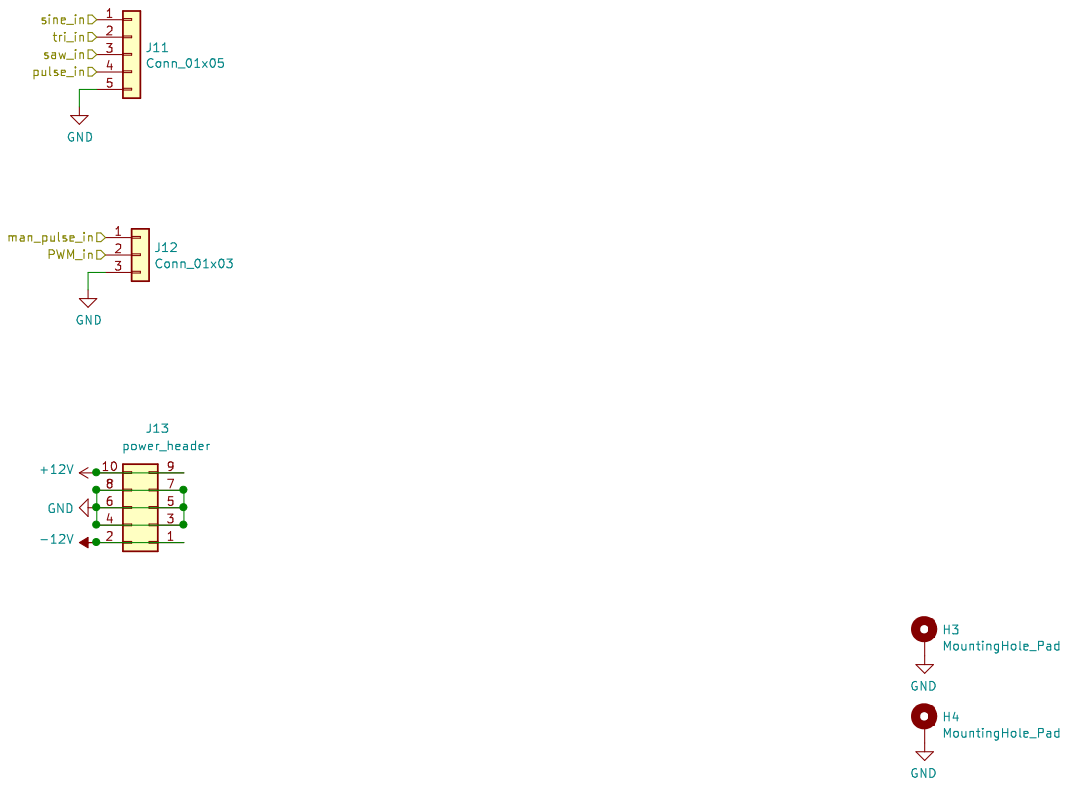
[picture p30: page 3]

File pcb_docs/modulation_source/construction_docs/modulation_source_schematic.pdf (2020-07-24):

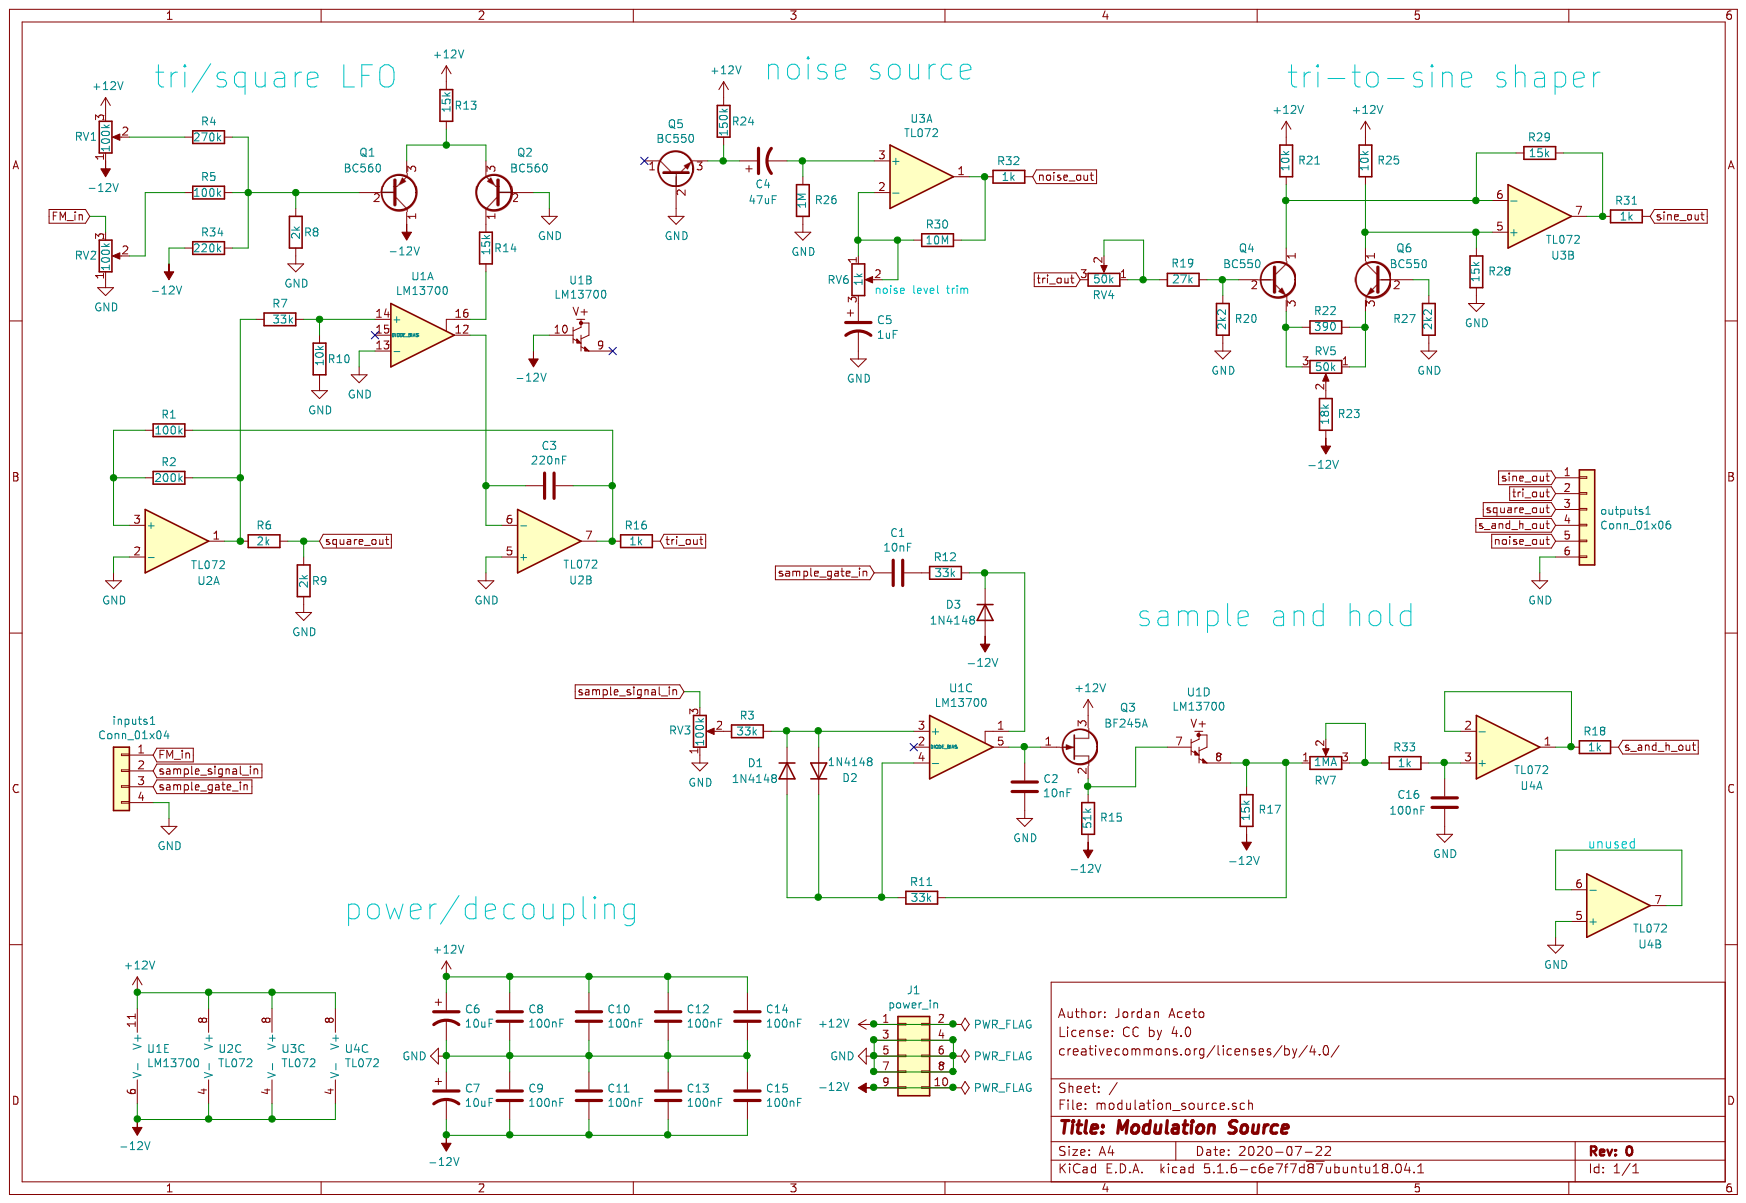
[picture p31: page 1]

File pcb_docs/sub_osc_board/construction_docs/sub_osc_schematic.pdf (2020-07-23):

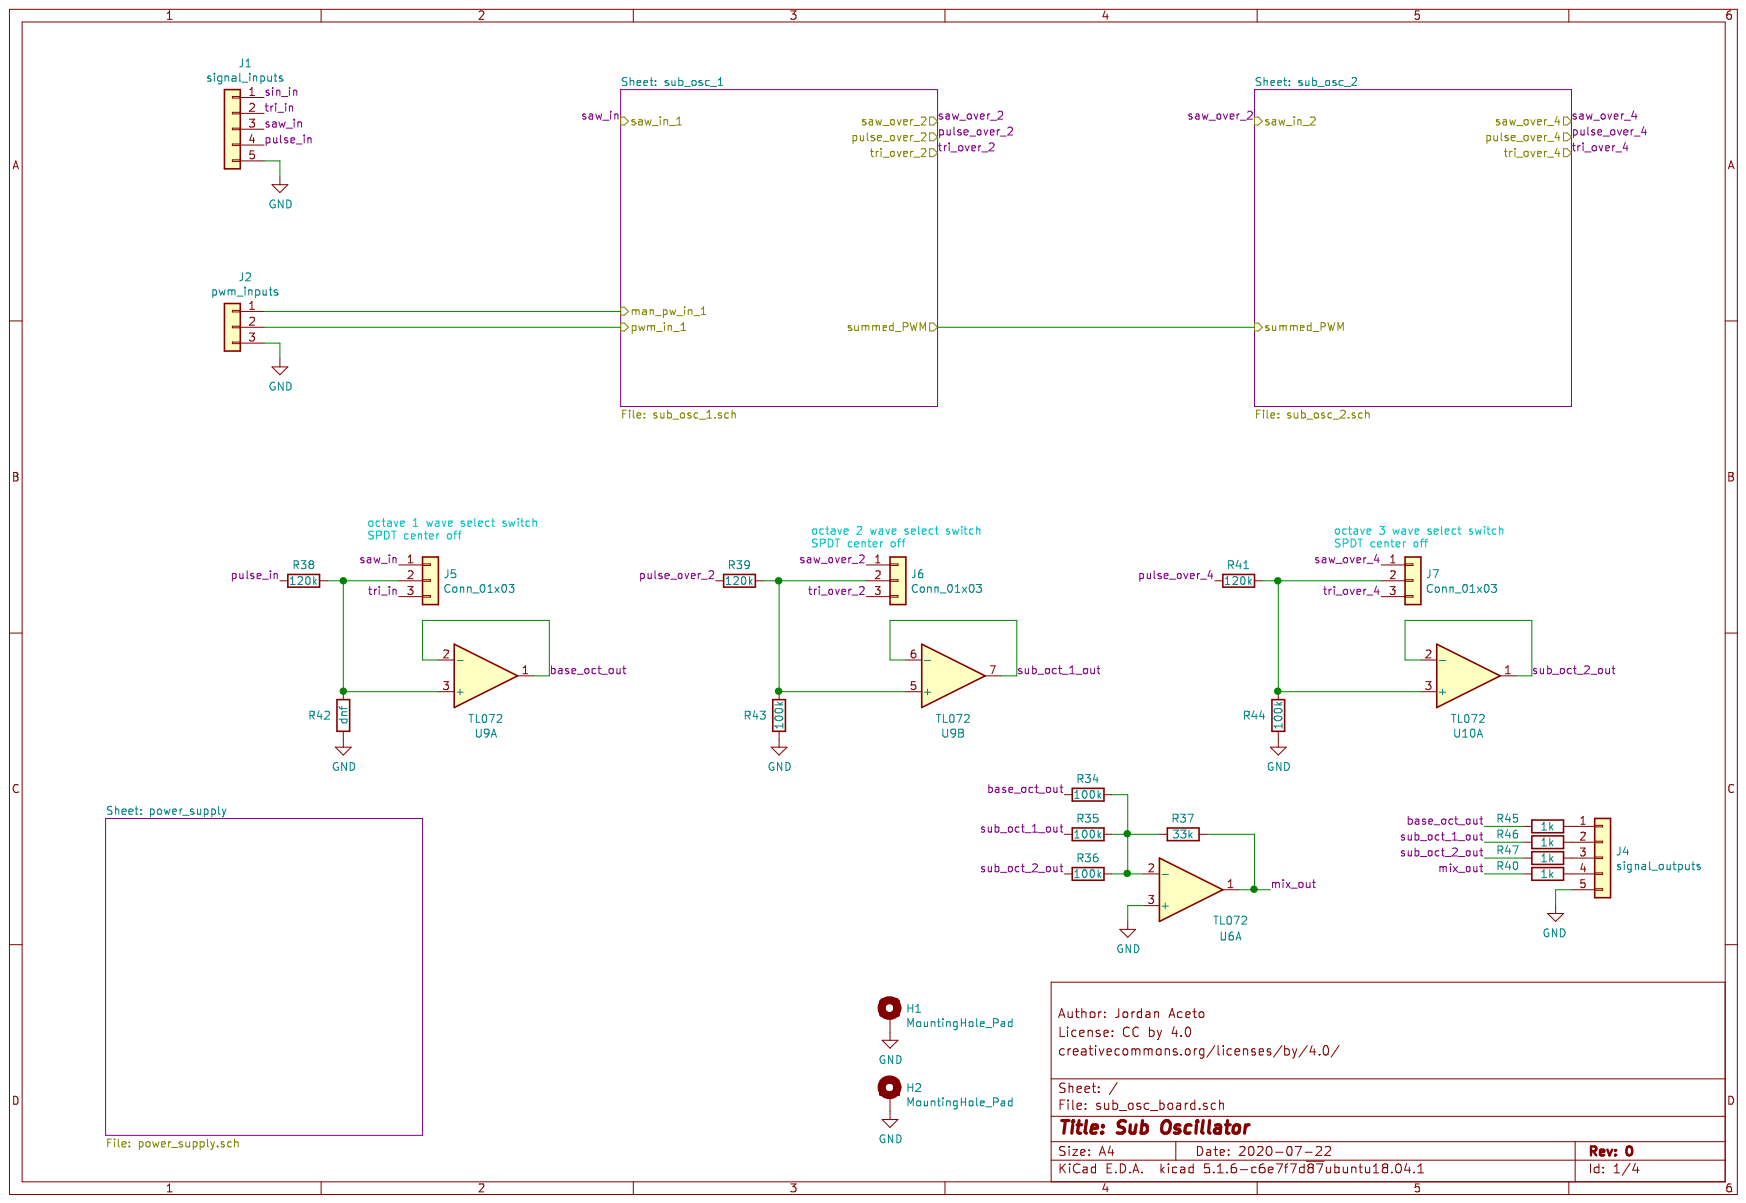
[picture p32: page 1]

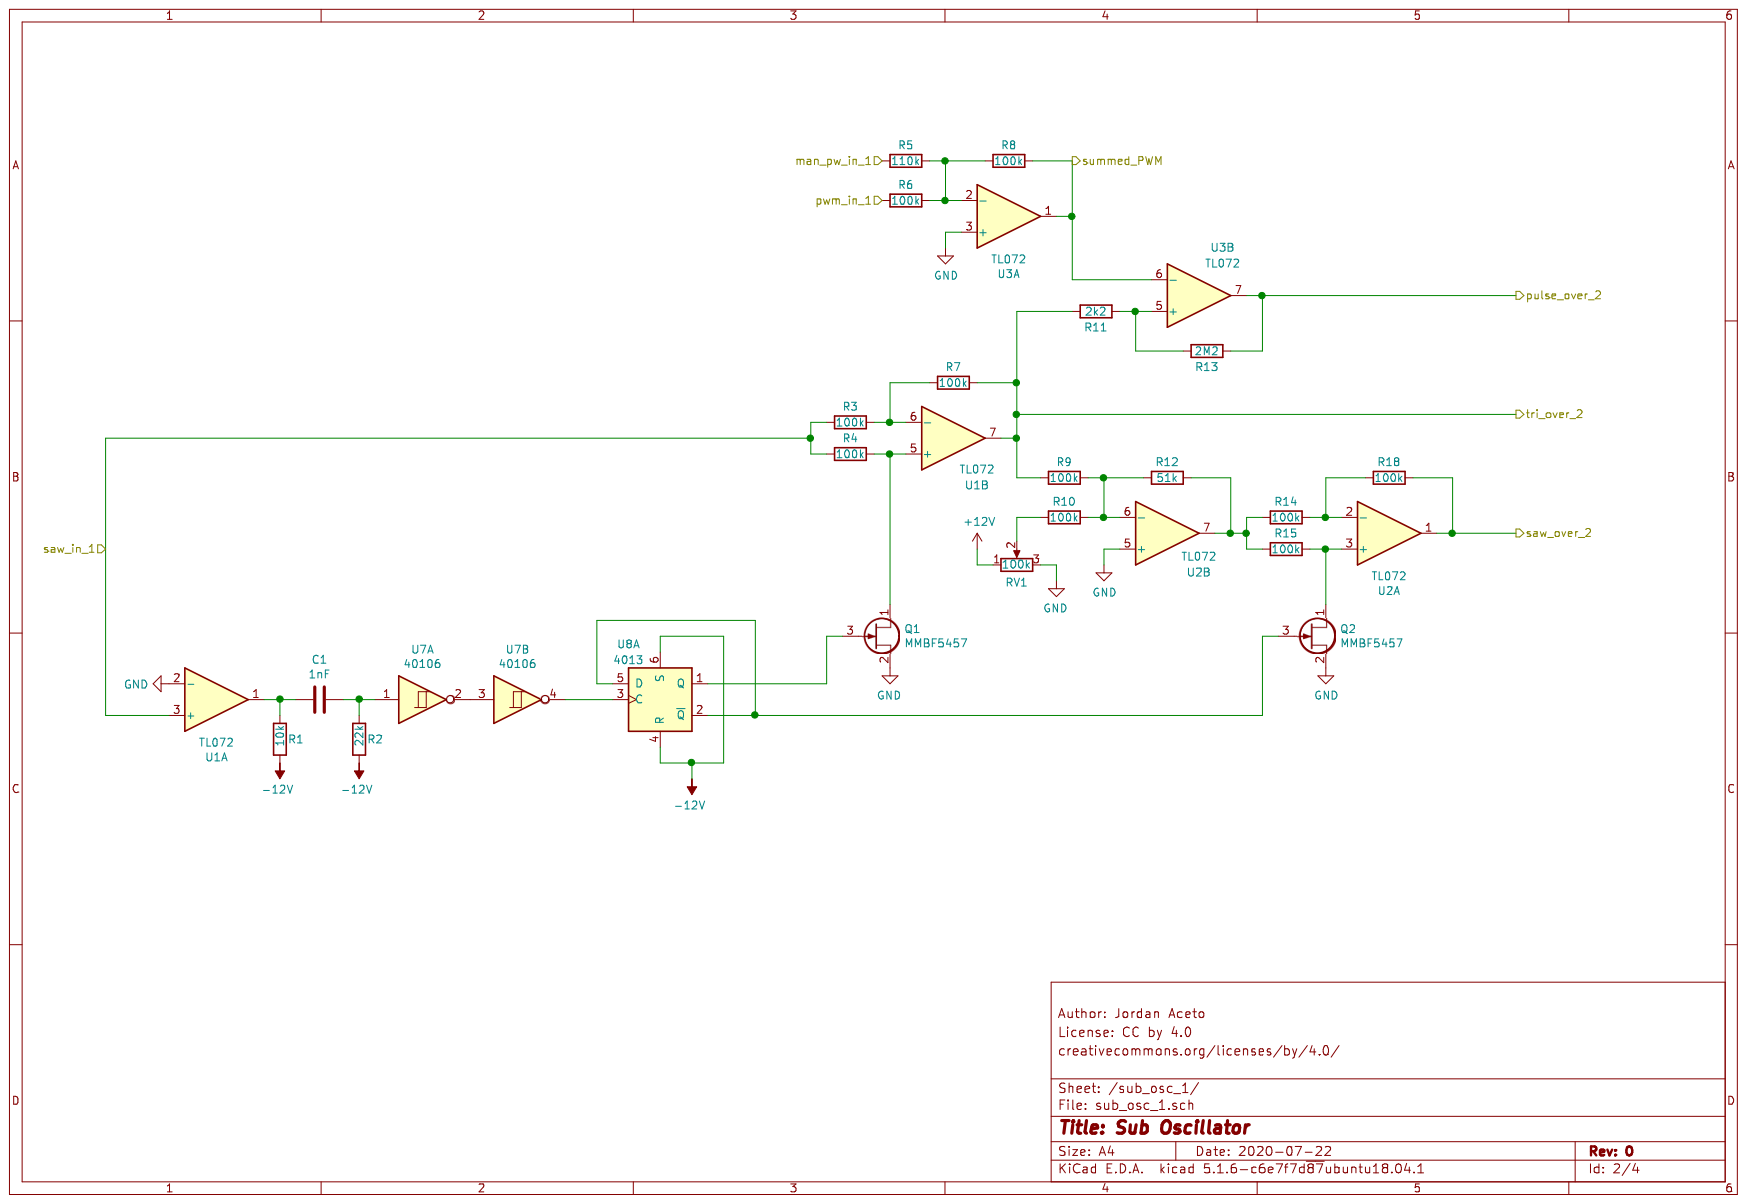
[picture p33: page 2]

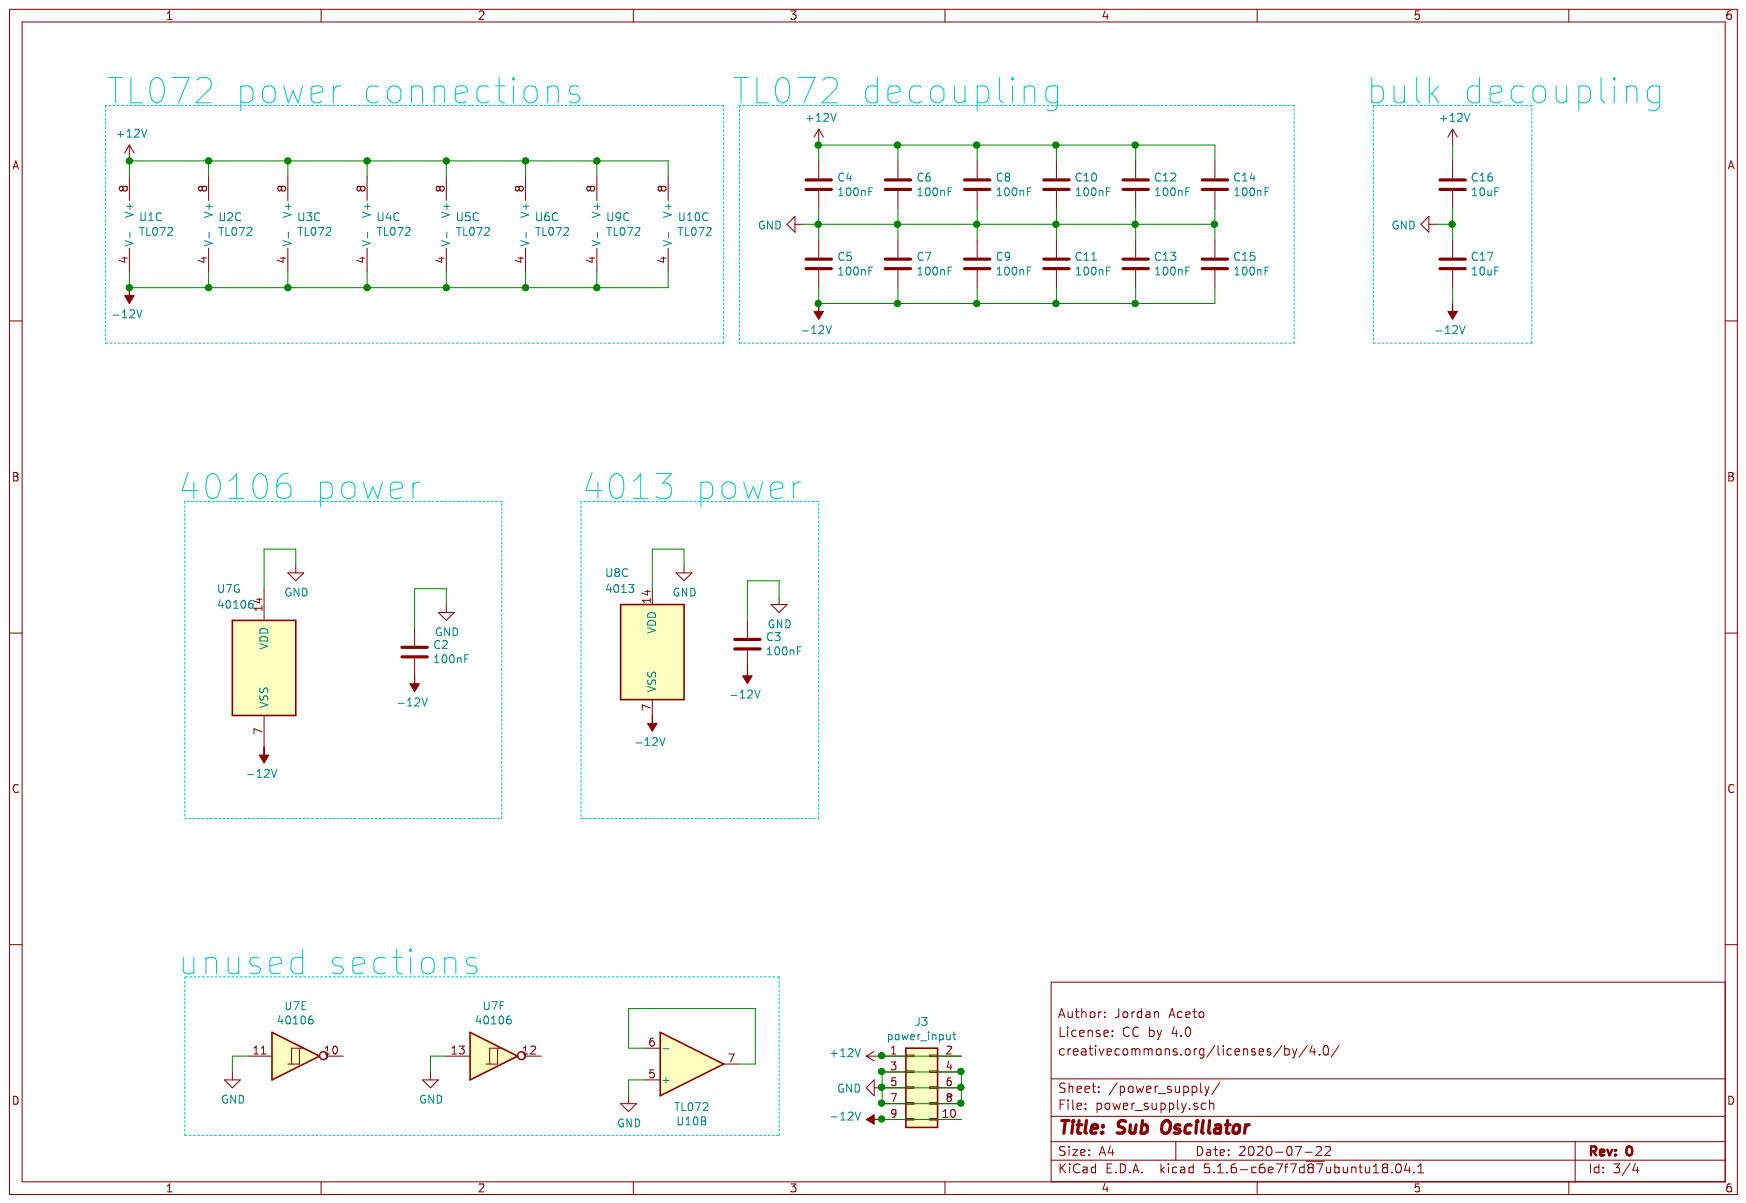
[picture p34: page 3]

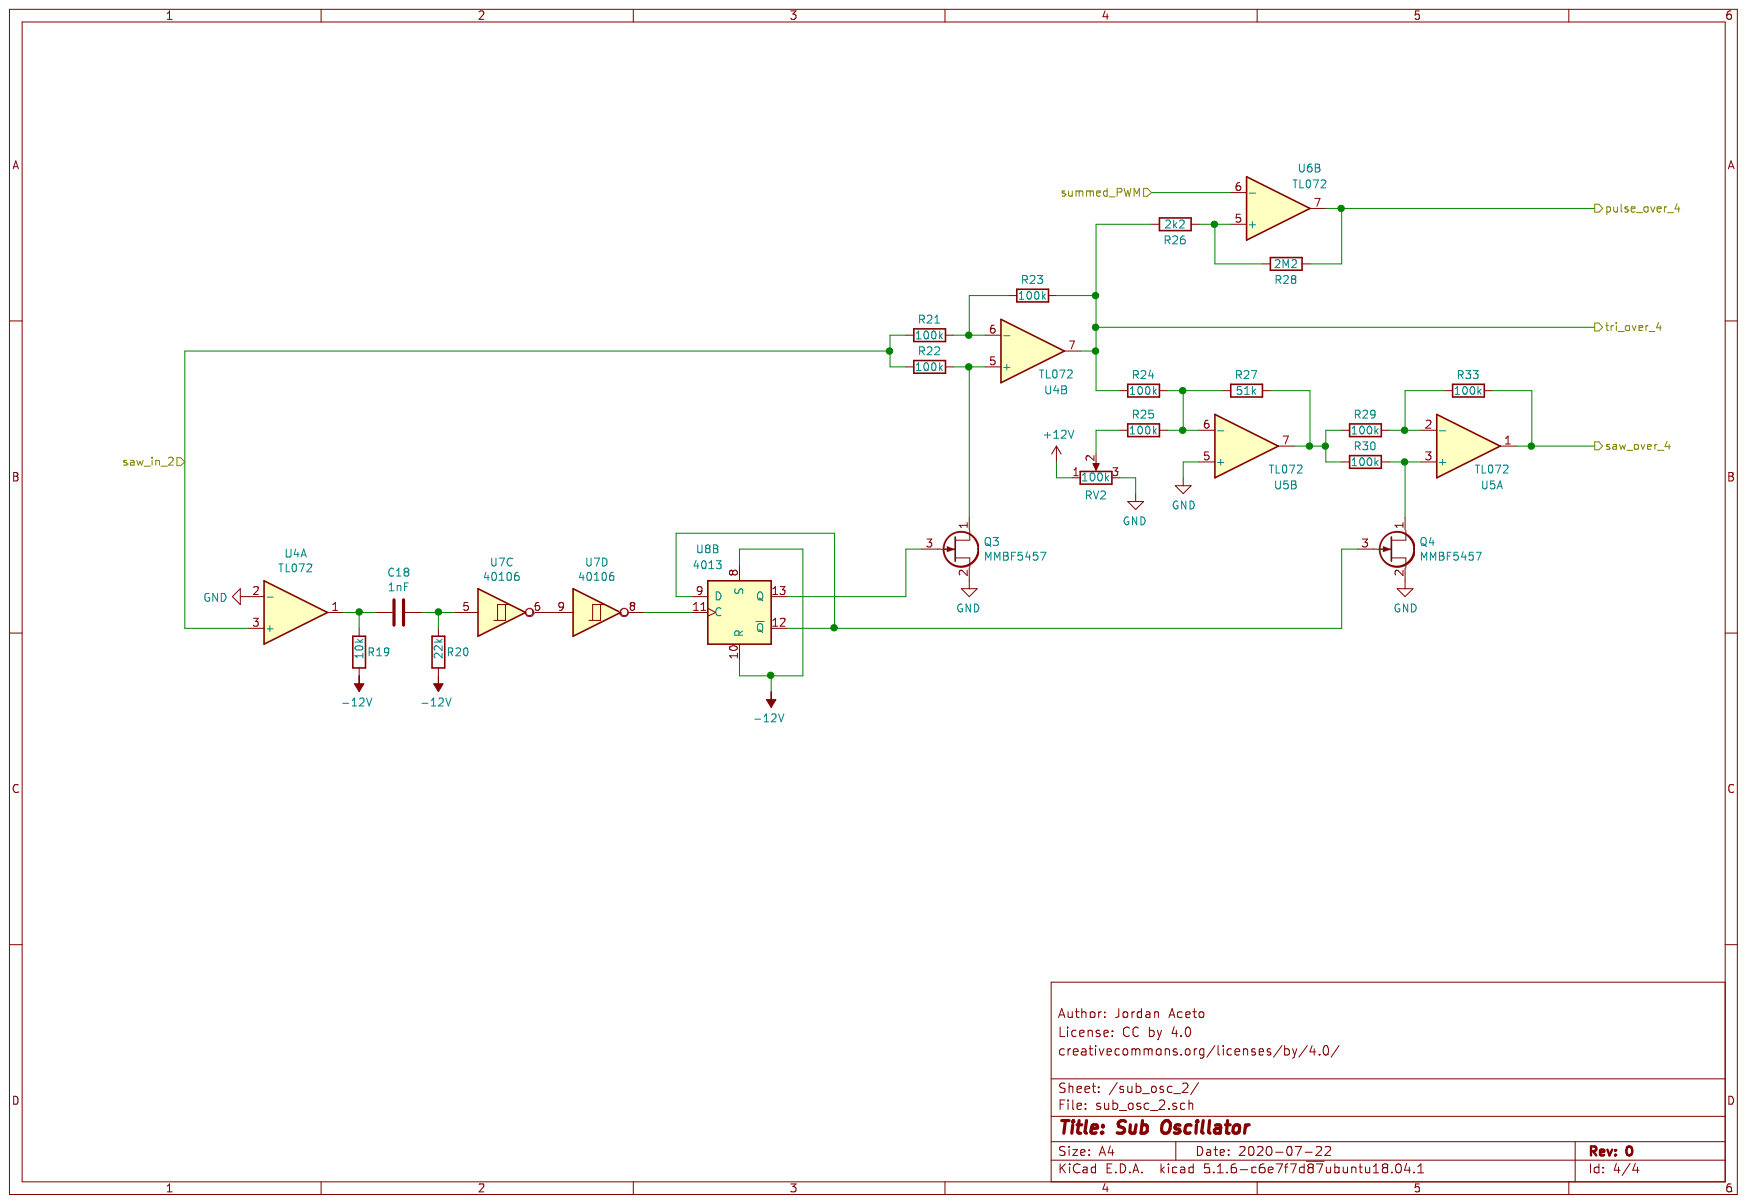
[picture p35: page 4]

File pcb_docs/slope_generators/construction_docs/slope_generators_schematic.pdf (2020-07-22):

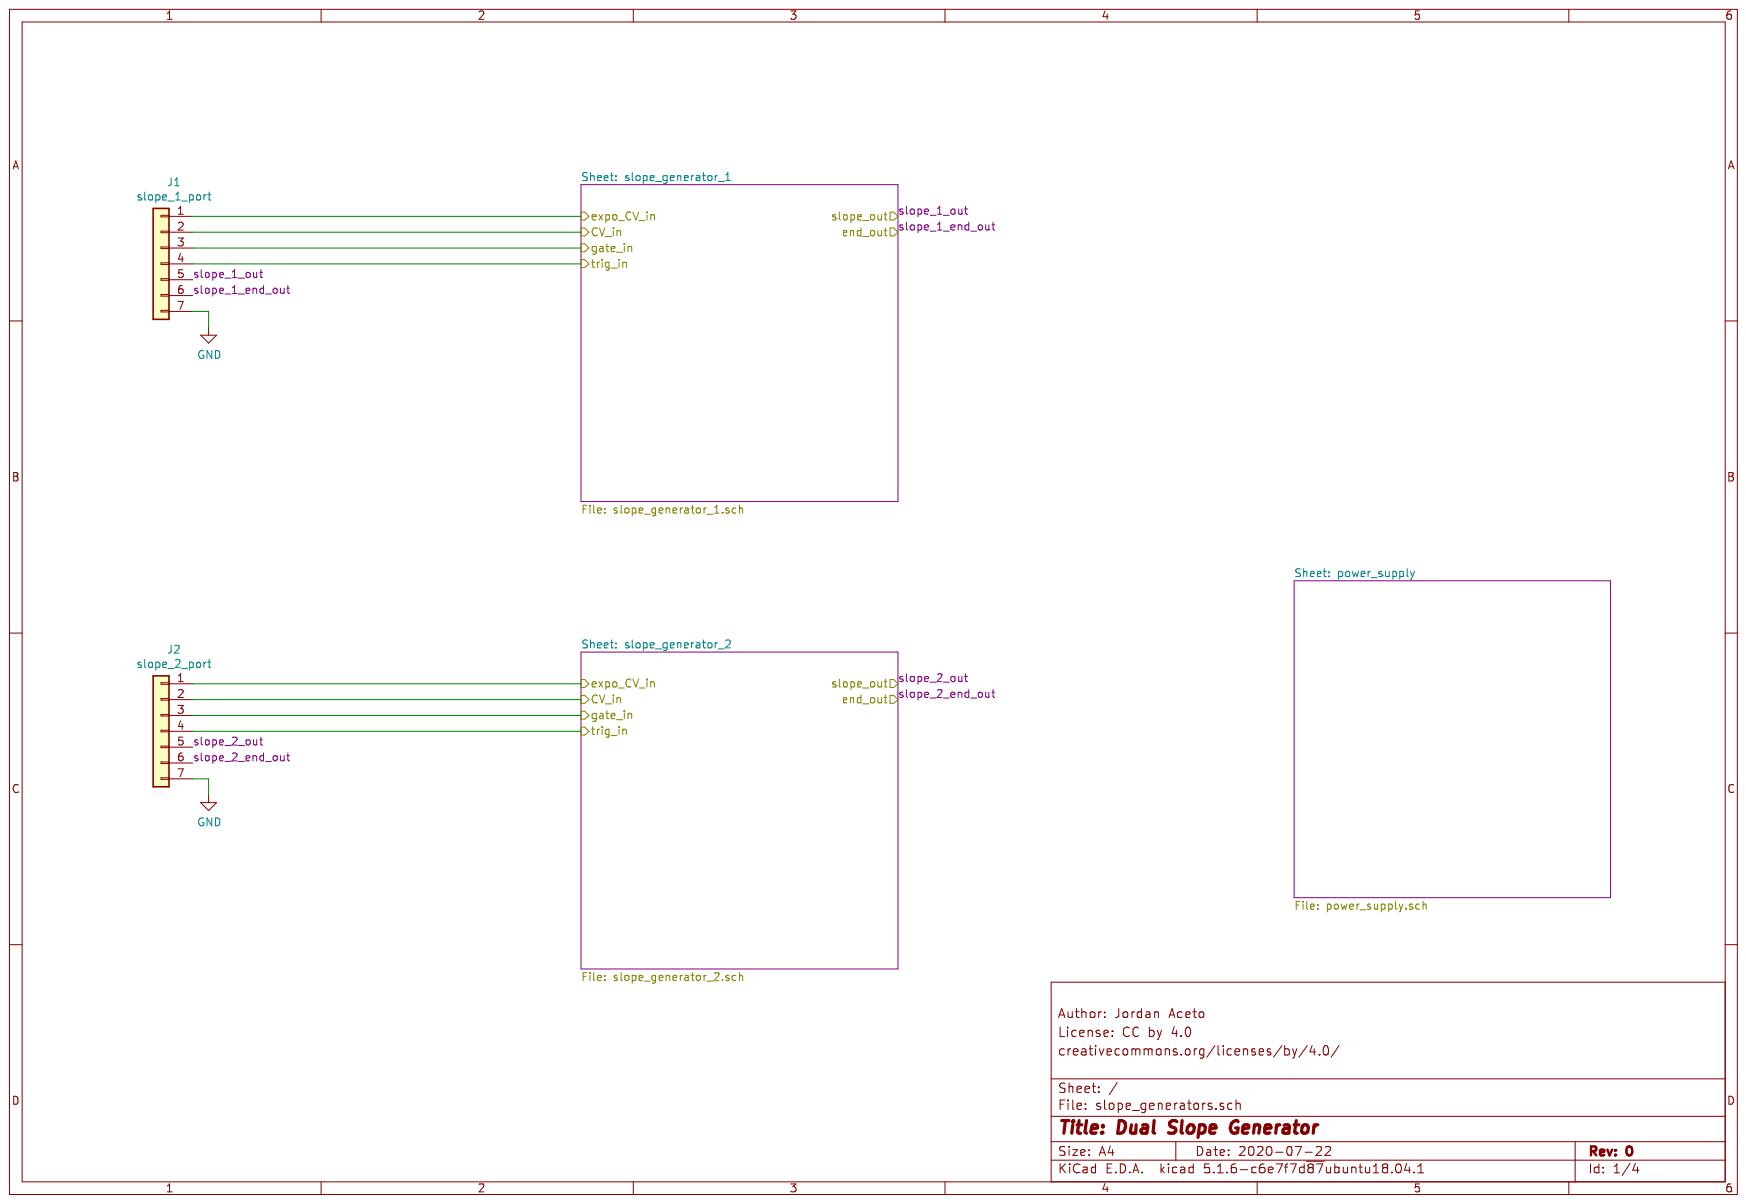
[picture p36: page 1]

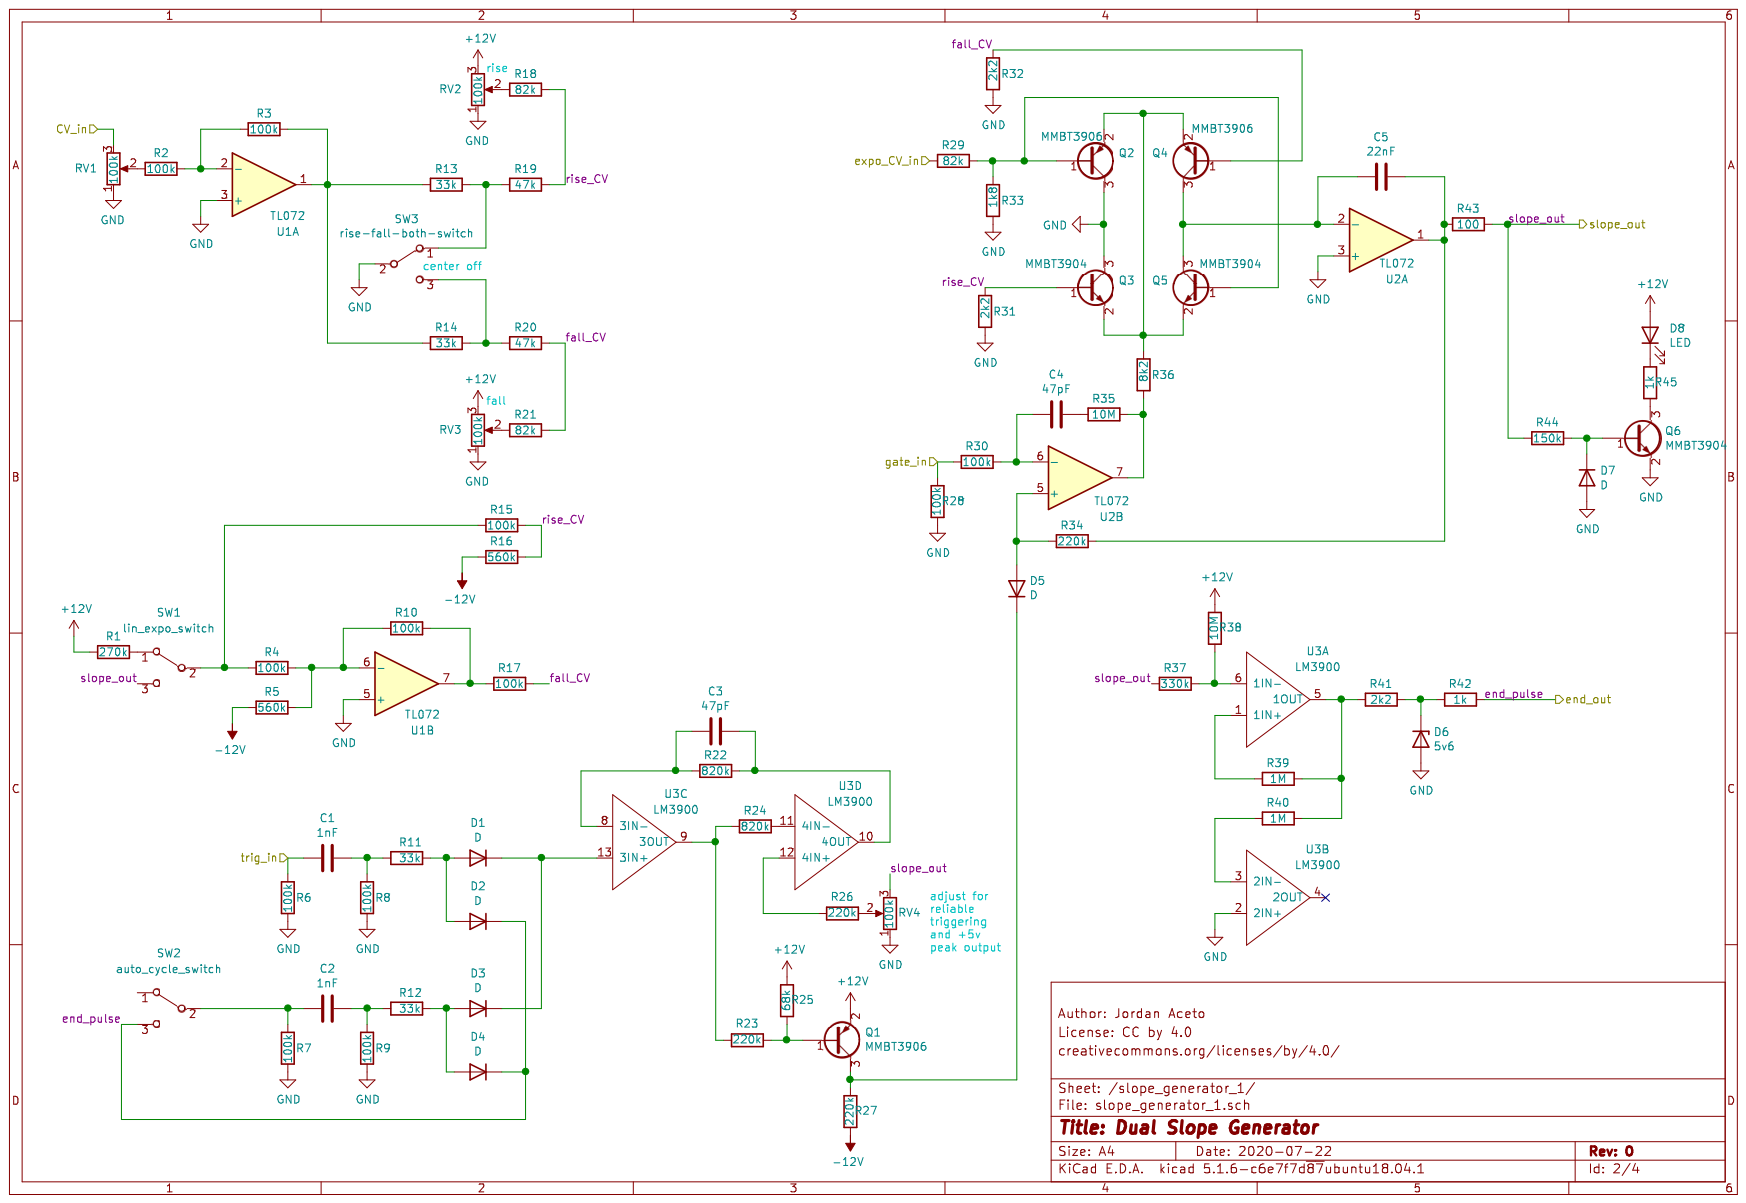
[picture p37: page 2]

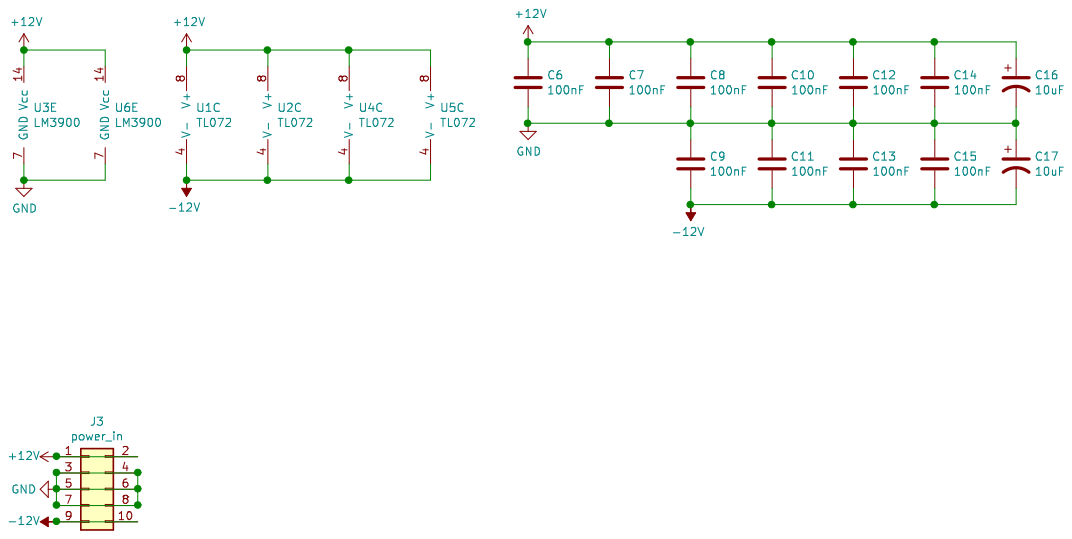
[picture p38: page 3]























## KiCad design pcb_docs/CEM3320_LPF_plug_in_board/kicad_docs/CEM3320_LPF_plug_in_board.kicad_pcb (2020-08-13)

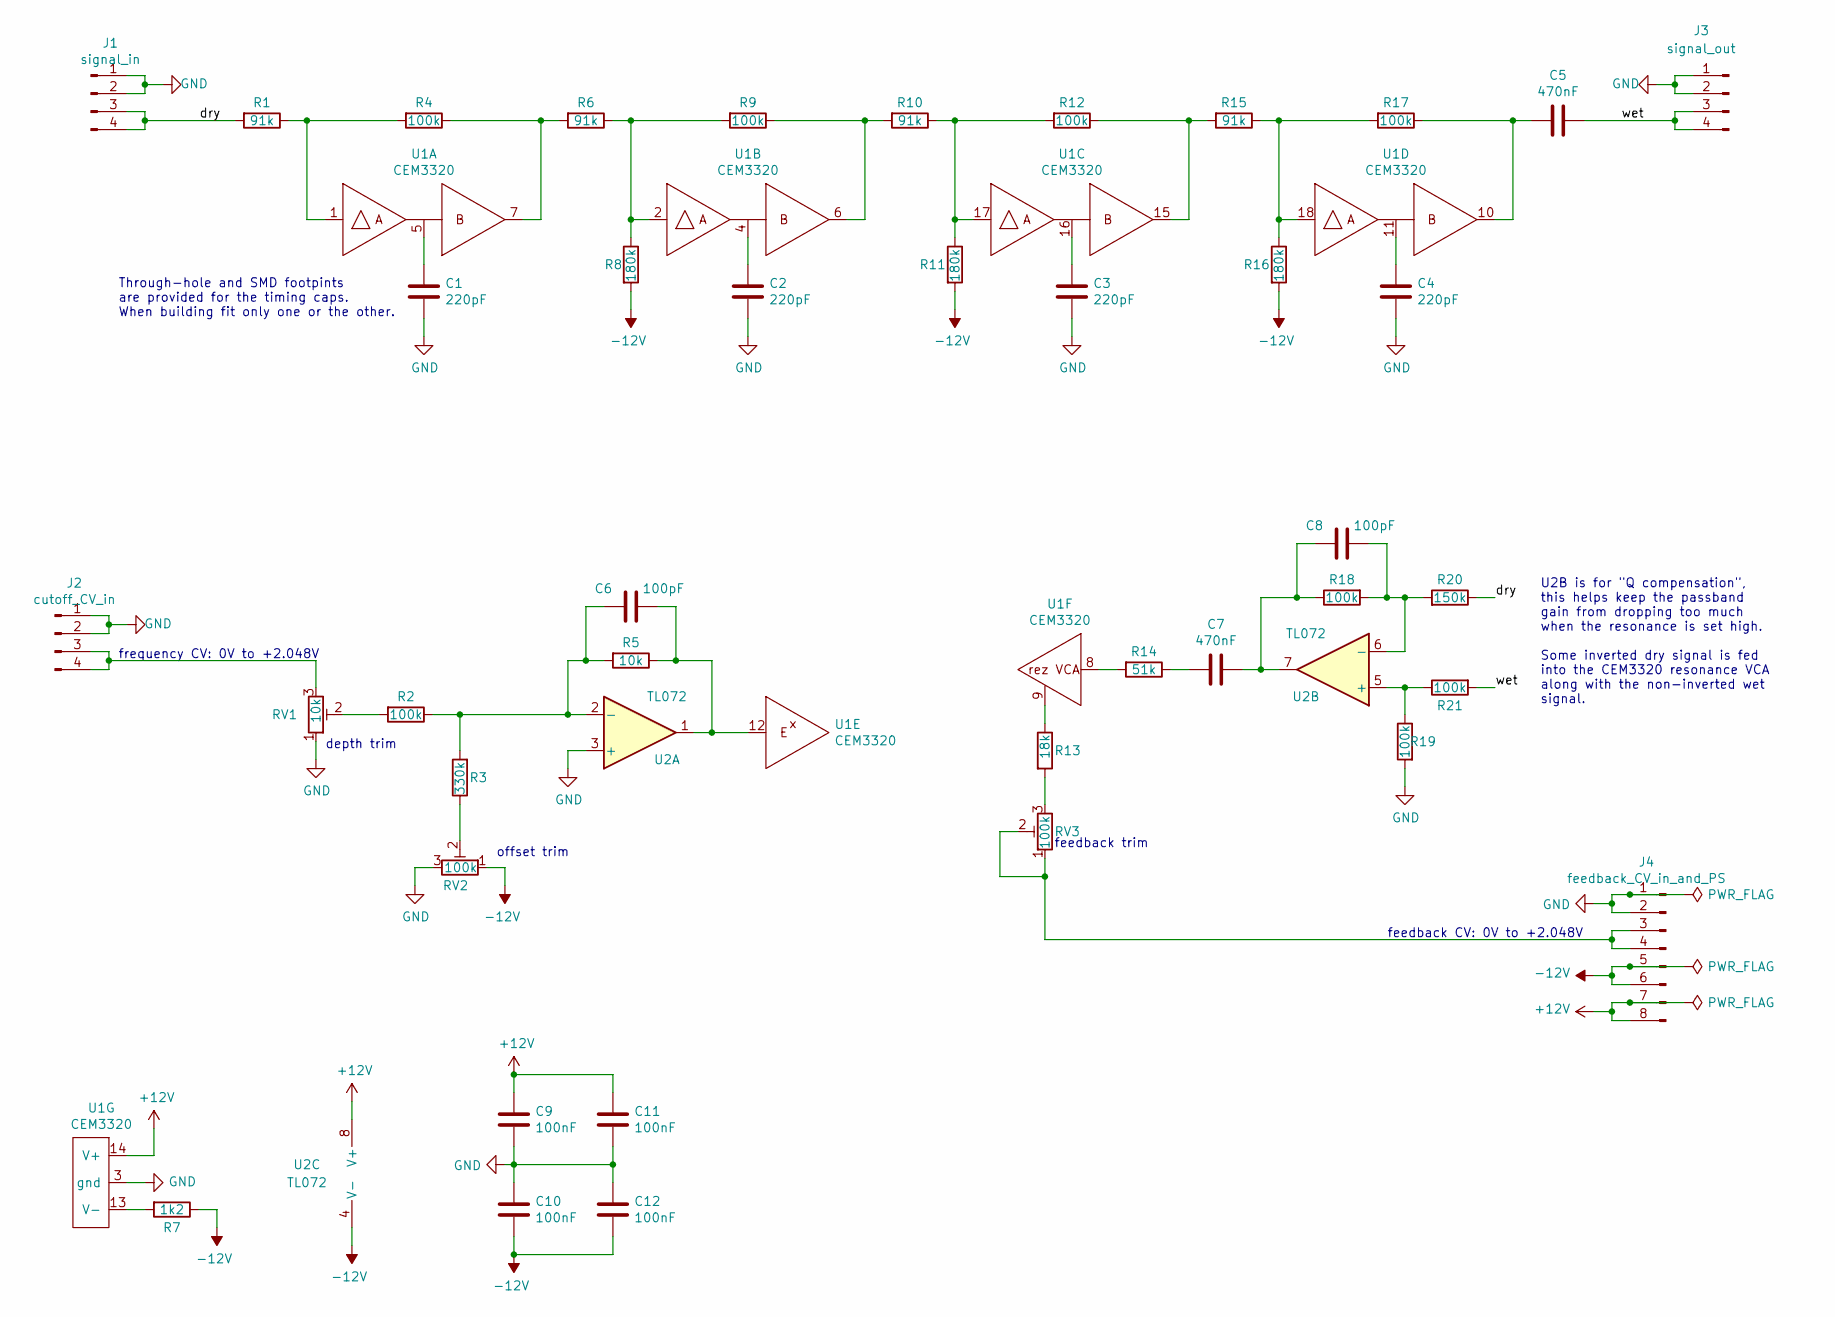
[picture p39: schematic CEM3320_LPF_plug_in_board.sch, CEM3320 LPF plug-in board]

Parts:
C1, C2, C3, C4: 220pF; timing_cap_dual_fp
C5, C7: 470nF; C_Rect_L7.0mm_W3.5mm_P5.00mm
C6, C8: 100pF; C_0805_2012Metric_Pad1.15x1.40mm_HandSolder
C9, C10, C11, C12: 100nF; C_0805_2012Metric_Pad1.15x1.40mm_HandSolder
J1: signal_in; PinHeader_1x04_P2.54mm_Vertical
J2: cutoff_CV_in; PinHeader_1x04_P2.54mm_Vertical
J3: signal_out; PinHeader_1x04_P2.54mm_Vertical
J4: feedback_CV_in_and_PS; PinHeader_1x08_P2.54mm_Vertical
R1, R6, R10, R15: 91k; R_0805_2012Metric_Pad1.15x1.40mm_HandSolder
R2, R4, R9, R12, R17, R18, R19, R21: 100k; R_0805_2012Metric_Pad1.15x1.40mm_HandSolder
R3: 330k; R_0805_2012Metric_Pad1.15x1.40mm_HandSolder
R5: 10k; R_0805_2012Metric_Pad1.15x1.40mm_HandSolder
R7: 1k2; R_0805_2012Metric_Pad1.15x1.40mm_HandSolder
R8, R11, R16: 180k; R_0805_2012Metric_Pad1.15x1.40mm_HandSolder
R13: 18k; R_0805_2012Metric_Pad1.15x1.40mm_HandSolder
R14: 51k; R_0805_2012Metric_Pad1.15x1.40mm_HandSolder
R20: 150k; R_0805_2012Metric_Pad1.15x1.40mm_HandSolder
RV1: 10k; Potentiometer_Bourns_3296W_Vertical
RV2, RV3: 100k; Potentiometer_Bourns_3296W_Vertical
U1: CEM3320; DIP-18_W7.62mm
U2: TL072; SOIC-8_3.9x4.9mm_P1.27mm

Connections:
+12V: C9.1, C11.1, J4.7, J4.8, U1.14 (V+), U2.8 (V+)
-12V: C10.2, C12.2, J4.5, J4.6, R7.1, R8.2, R11.2, R16.2, RV2.1, U2.4 (V-)
/dry: J1.3, J1.4, R1.2, R20.1
/wet: C5.1, J3.3, J3.4, R21.2
GND: C1.2, C2.2, C3.2, C4.2, C9.2, C10.1, C11.2, C12.1, J1.1, J1.2, J2.1, J2.2, J3.1, J3.2, J4.1, J4.2, R19.2, RV1.1, RV2.3, U1.3 (gnd), U2.3 (+)
unnamed: C1.1, U1.5
unnamed: C2.1, U1.4
unnamed: C3.1, U1.16
unnamed: C4.1, U1.11
unnamed: C5.2, R17.1, U1.10
unnamed: C6.1, R2.1, R3.2, R5.2, U2.2 (-)
unnamed: C6.2, R5.1, U1.12, U2.1
unnamed: C7.1, C8.1, R18.1, U2.7
unnamed: C7.2, R14.1
unnamed: C8.2, R18.2, R20.2, U2.6 (-)
unnamed: J2.3, J2.4, RV1.3
unnamed: J4.3, J4.4, RV3.1, RV3.2
unnamed: R1.1, R4.2, U1.1
unnamed: R2.2, RV1.2
unnamed: R3.1, RV2.2
unnamed: R4.1, R6.2, U1.7
unnamed: R6.1, R8.1, R9.2, U1.2
unnamed: R7.2, U1.13 (V-)
unnamed: R10.1, R11.1, R12.2, U1.17
unnamed: R9.1, R10.2, U1.6
unnamed: R12.1, R15.2, U1.15
unnamed: R13.1, U1.9
unnamed: R13.2, RV3.3
unnamed: R14.2, U1.8
unnamed: R15.1, R16.1, R17.2, U1.18
unnamed: R19.1, R21.1, U2.5 (+)

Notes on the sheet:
feedback CV: 0V to +2.048V
frequency CV: 0V to +2.048V
U2B is for "Q compensation", this helps keep the passband gain from dropping too much when the resonance is set high. Some inverted dry signal is fed into the CEM3320 resonance VCA along with the non-inverted wet signal.
feedback trim
depth trim
offset trim
Through-hole and SMD footpints are provided for the timing caps. When building fit only one or the other.

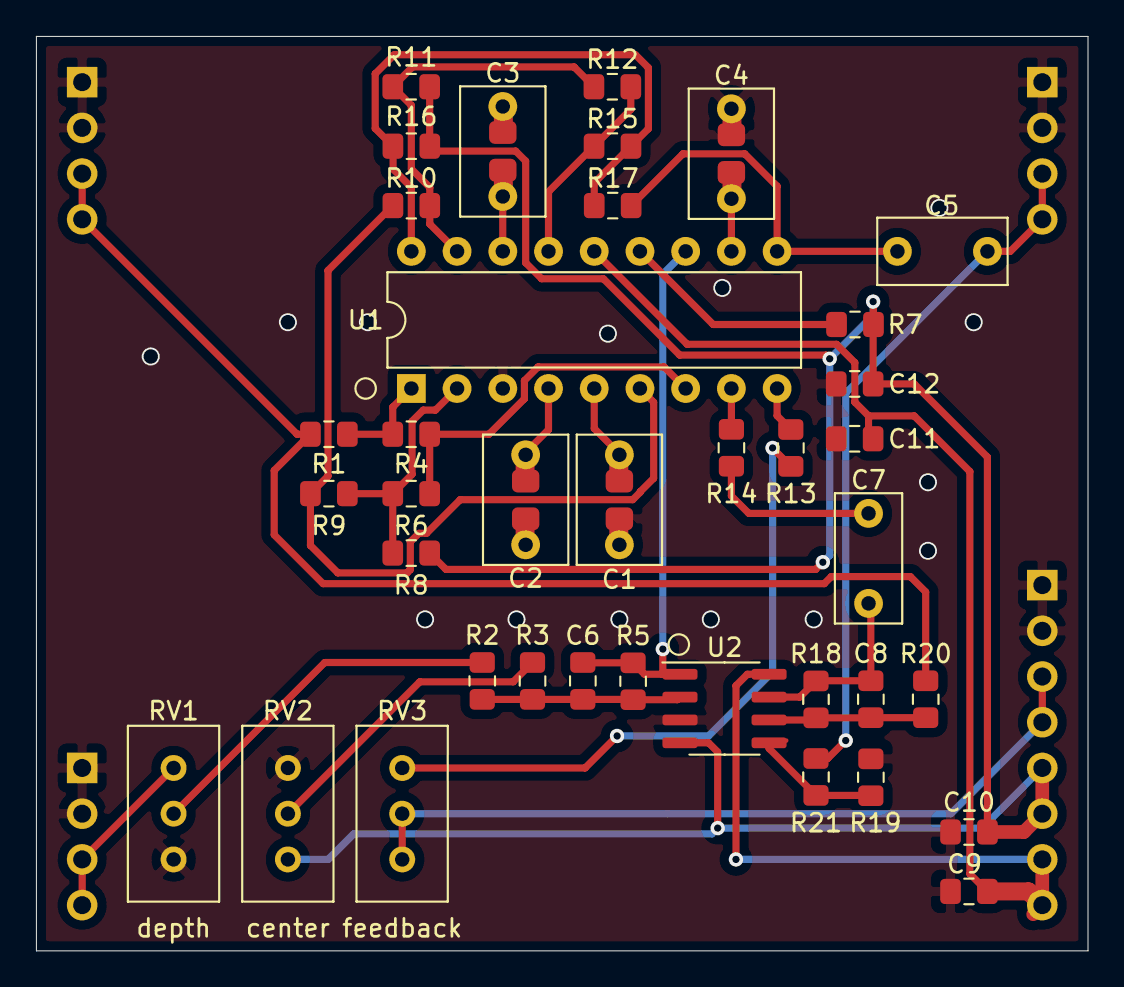
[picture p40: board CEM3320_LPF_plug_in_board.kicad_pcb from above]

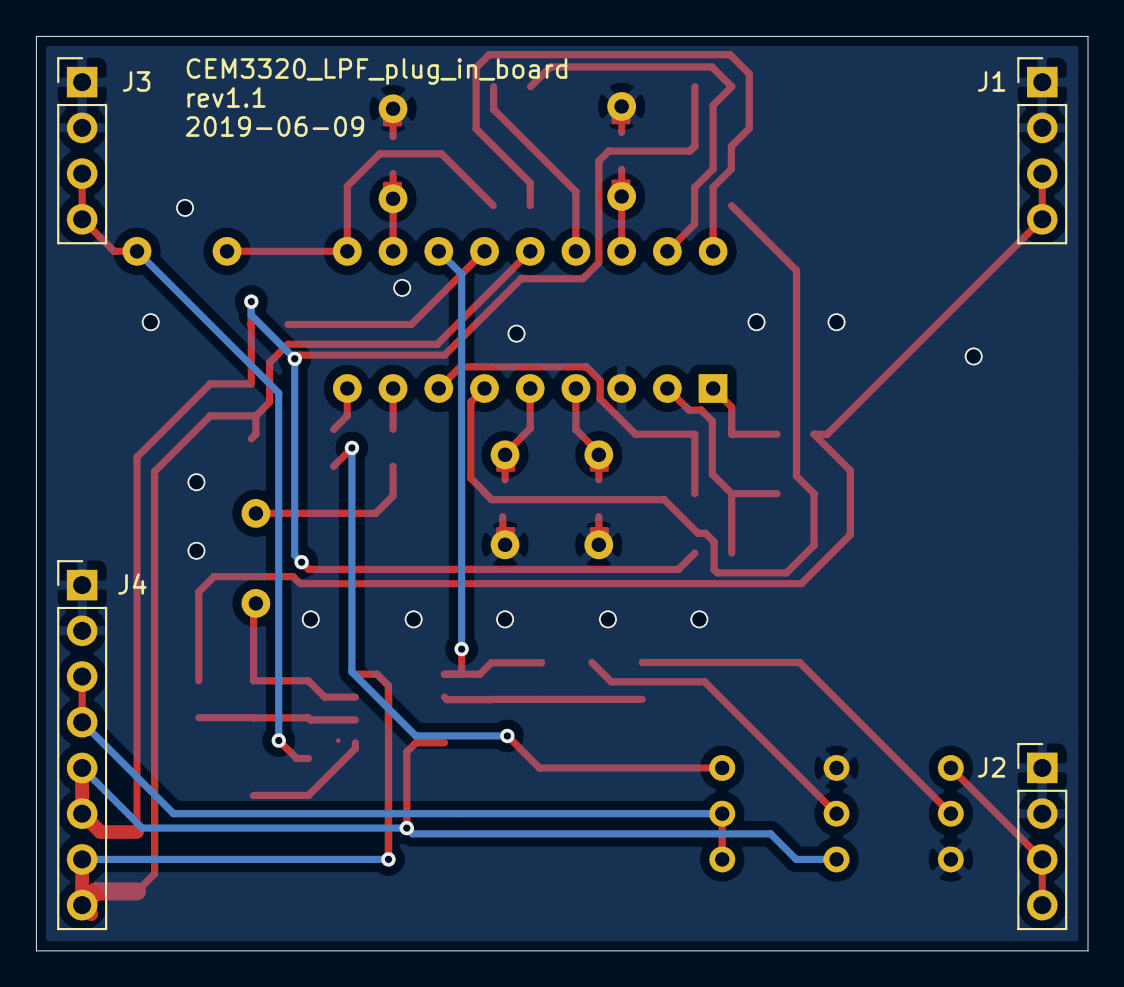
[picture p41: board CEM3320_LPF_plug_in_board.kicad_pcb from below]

Board: 2 copper layers, 58.4 x 50.8 mm, 42 parts (4 on the bottom side), 31 nets.

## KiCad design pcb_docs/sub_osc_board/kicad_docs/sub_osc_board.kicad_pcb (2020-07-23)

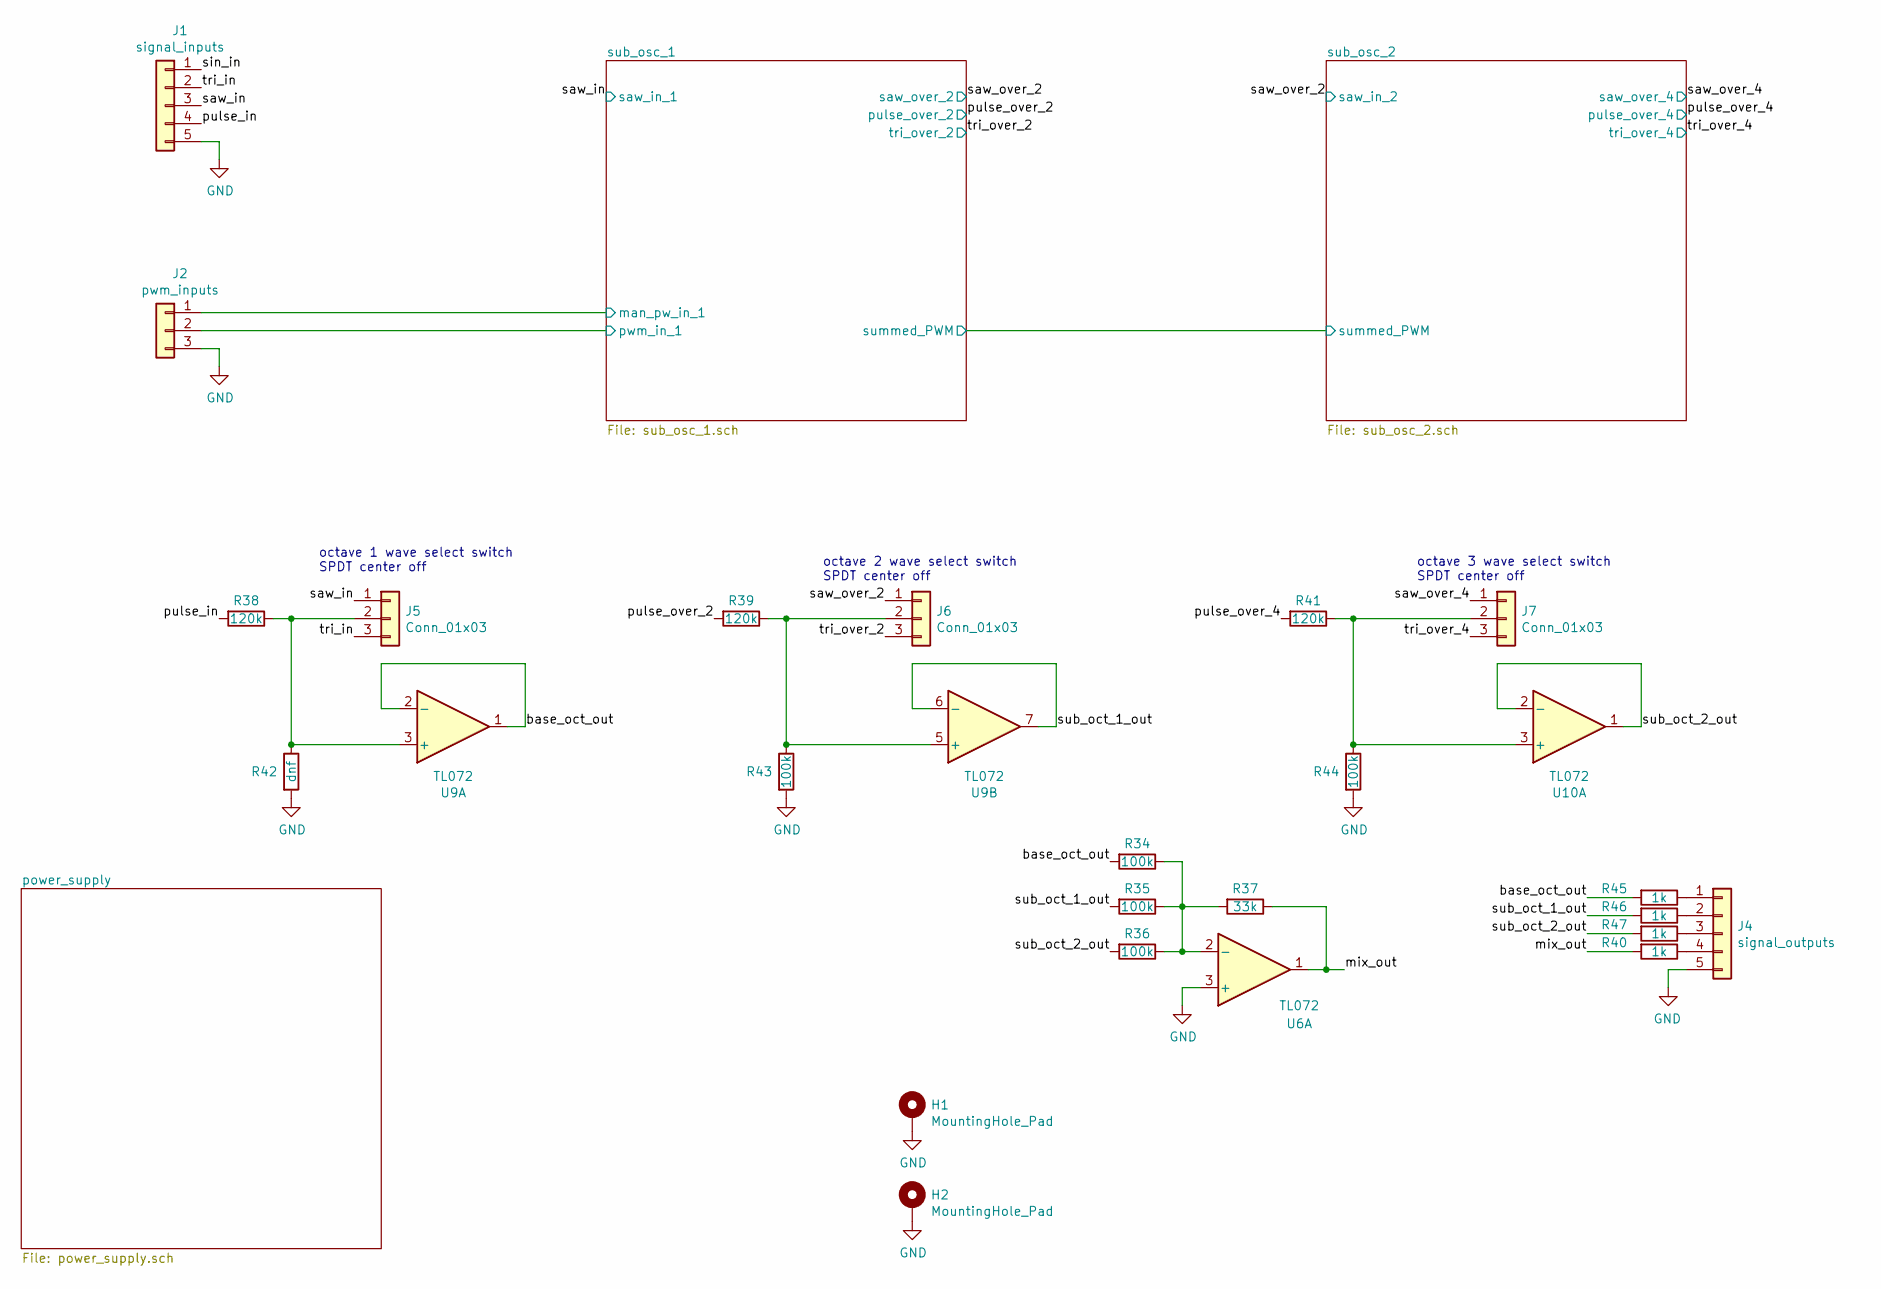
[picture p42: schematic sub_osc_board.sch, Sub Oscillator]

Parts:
H1, H2: MountingHole_Pad; MountingHole_3.2mm_M3_Pad_Via
J1: signal_inputs; PinHeader_1x05_P2.54mm_Vertical
J2: pwm_inputs; PinHeader_1x03_P2.54mm_Vertical
J4: signal_outputs; PinHeader_1x05_P2.54mm_Vertical
J5, J6, J7: Conn_01x03; PinHeader_1x03_P2.54mm_Vertical
R34, R35, R36, R43, R44: 100k; R_0805_2012Metric_Pad1.15x1.40mm_HandSolder
R37: 33k; R_0805_2012Metric_Pad1.15x1.40mm_HandSolder
R38, R39, R41: 120k; R_0805_2012Metric_Pad1.15x1.40mm_HandSolder
R40, R45, R46, R47: 1k; R_0805_2012Metric_Pad1.15x1.40mm_HandSolder
R42: dnf; R_0805_2012Metric_Pad1.15x1.40mm_HandSolder
U6, U9, U10: TL072; SOIC-8_3.9x4.9mm_P1.27mm

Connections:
/base_oct_out: R34.2, R45.2, U9.1, U9.2 (-)
/mix_out: R37.1, R40.2, U6.1
/pulse_in: J1.4, R38.2
/pulse_over_2: R39.2; also elsewhere on the board
/pulse_over_4: R41.2; also elsewhere on the board
/saw_in: J1.3, J5.1; also elsewhere on the board
/saw_over_2: J6.1; also elsewhere on the board
/saw_over_4: J7.1; also elsewhere on the board
/sin_in: J1.1
/sub_oct_1_out: R35.2, R46.2, U9.6 (-), U9.7
/sub_oct_2_out: R36.2, R47.2, U10.1, U10.2 (-)
/sub_osc_1/man_pw_in_1: J2.1; also elsewhere on the board
/sub_osc_1/pwm_in_1: J2.2; also elsewhere on the board
/tri_in: J1.2, J5.3
/tri_over_2: J6.3; also elsewhere on the board
/tri_over_4: J7.3; also elsewhere on the board
GND: H1.1, H2.1, J1.5, J2.3, J4.5, R42.2, R43.2, R44.2, U6.3 (+); also elsewhere on the board
unnamed: J4.1, R45.1
unnamed: J4.2, R46.1
unnamed: J4.3, R47.1
unnamed: J4.4, R40.1
unnamed: J5.2, R38.1, R42.1, U9.3 (+)
unnamed: J6.2, R39.1, R43.1, U9.5 (+)
unnamed: J7.2, R41.1, R44.1, U10.3 (+)
unnamed: R34.1, R35.1, R36.1, R37.2, U6.2 (-)

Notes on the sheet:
octave 1 wave select switch SPDT center off
octave 2 wave select switch SPDT center off
octave 3 wave select switch SPDT center off

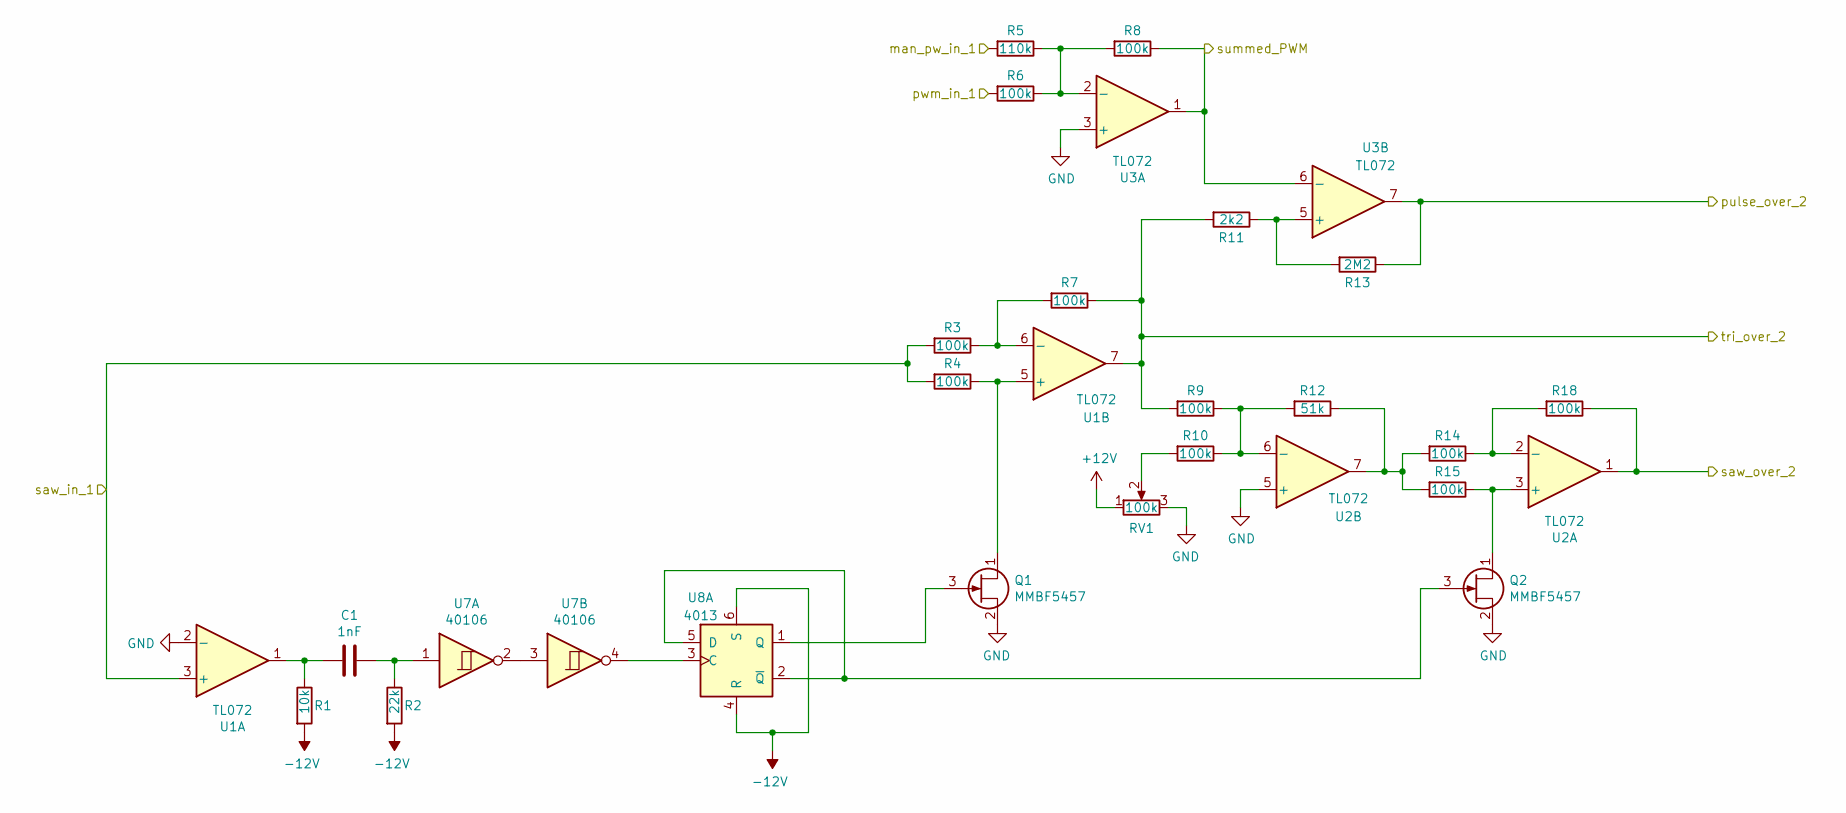
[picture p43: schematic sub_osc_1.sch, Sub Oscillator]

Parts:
C1: 1nF; C_0805_2012Metric_Pad1.15x1.40mm_HandSolder
Q1, Q2: MMBF5457; SOT-23_Handsoldering
R1: 10k; R_0805_2012Metric_Pad1.15x1.40mm_HandSolder
R2: 22k; R_0805_2012Metric_Pad1.15x1.40mm_HandSolder
R3, R4, R6, R7, R8, R9, R10, R14, R15, R18: 100k; R_0805_2012Metric_Pad1.15x1.40mm_HandSolder
R5: 110k; R_0805_2012Metric_Pad1.15x1.40mm_HandSolder
R11: 2k2; R_0805_2012Metric_Pad1.15x1.40mm_HandSolder
R12: 51k; R_0805_2012Metric_Pad1.15x1.40mm_HandSolder
R13: 2M2; R_0805_2012Metric_Pad1.15x1.40mm_HandSolder
RV1: 100k; Potentiometer_Bourns_3296W_Vertical
U1, U2, U3: TL072; SOIC-8_3.9x4.9mm_P1.27mm
U7: 40106; SOIC-14_3.9x8.7mm_P1.27mm
U8: 4013; SOIC-14_3.9x8.7mm_P1.27mm

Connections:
+12V: RV1.1; also elsewhere on the board
-12V: R1.2, R2.2, U8.4 (R), U8.6 (S); also elsewhere on the board
/pulse_over_2: R13.1, U3.7; also elsewhere on the board
/saw_in: R3.2, R4.2, U1.3 (+); also elsewhere on the board
/saw_over_2: R18.1, U2.1; also elsewhere on the board
/sub_osc_1/man_pw_in_1: R5.2; also elsewhere on the board
/sub_osc_1/pwm_in_1: R6.2; also elsewhere on the board
/sub_osc_1/summed_PWM: R8.1, U3.1, U3.6 (-); also elsewhere on the board
/tri_over_2: R7.1, R9.2, R11.2, U1.7; also elsewhere on the board
GND: Q1.2 (S), Q2.2 (S), RV1.3, U1.2 (-), U2.5 (+), U3.3 (+); also elsewhere on the board
unnamed: C1.1, R2.1, U7.1
unnamed: C1.2, R1.1, U1.1
unnamed: Q1.1 (D), R4.1, U1.5 (+)
unnamed: Q1.3 (G), U8.1 (Q)
unnamed: Q2.1 (D), R15.1, U2.3 (+)
unnamed: Q2.3 (G), U8.2 (~Q), U8.5 (D)
unnamed: R3.1, R7.2, U1.6 (-)
unnamed: R5.1, R6.1, R8.2, U3.2 (-)
unnamed: R9.1, R10.1, R12.2, U2.6 (-)
unnamed: R10.2, RV1.2
unnamed: R11.1, R13.2, U3.5 (+)
unnamed: R12.1, R14.2, R15.2, U2.7
unnamed: R14.1, R18.2, U2.2 (-)
unnamed: U7.2, U7.3
unnamed: U7.4, U8.3 (C)

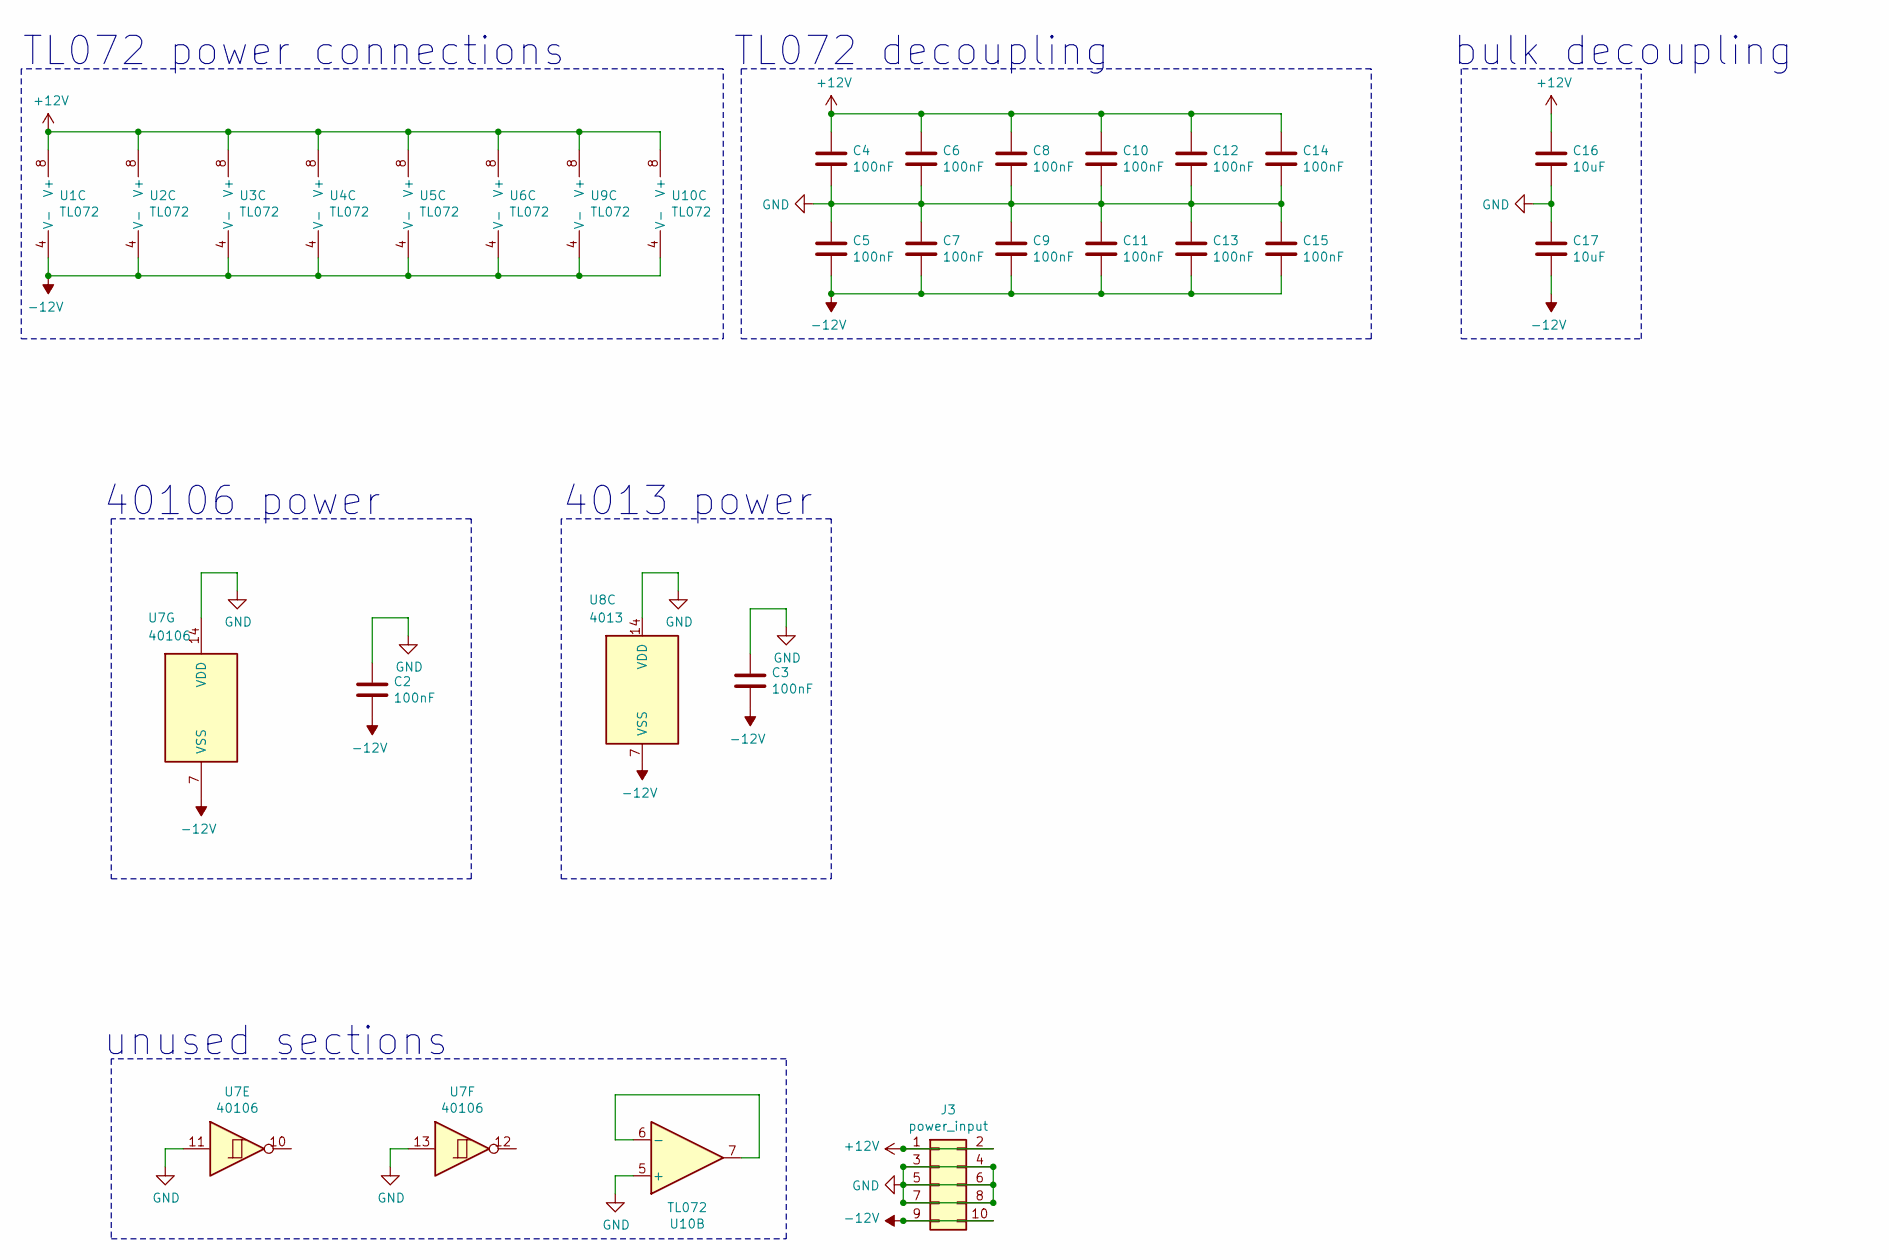
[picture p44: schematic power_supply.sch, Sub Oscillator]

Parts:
C2, C3, C4, C5, C6, C7, C8, C9, C10, C11, C12, C13, C14, C15: 100nF; C_0805_2012Metric_Pad1.15x1.40mm_HandSolder
C16, C17: 10uF; C_0805_2012Metric_Pad1.15x1.40mm_HandSolder
J3: power_input; PinHeader_2x05_P2.54mm_Vertical
U1, U2, U3, U4, U5, U6, U9, U10: TL072; SOIC-8_3.9x4.9mm_P1.27mm
U7: 40106; SOIC-14_3.9x8.7mm_P1.27mm
U8: 4013; SOIC-14_3.9x8.7mm_P1.27mm

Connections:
+12V: C4.1, C6.1, C8.1, C10.1, C12.1, C14.1, C16.1, J3.1, J3.2, U1.8 (V+), U2.8 (V+), U3.8 (V+), U4.8 (V+), U5.8 (V+), U6.8 (V+), U9.8 (V+), U10.8 (V+); also elsewhere on the board
-12V: C2.2, C3.2, C5.2, C7.2, C9.2, C11.2, C13.2, C15.2, C17.2, J3.9, J3.10, U1.4 (V-), U2.4 (V-), U3.4 (V-), U4.4 (V-), U5.4 (V-), U6.4 (V-), U7.7 (VSS), U8.7 (VSS), U9.4 (V-), U10.4 (V-); also elsewhere on the board
GND: C2.1, C3.1, C4.2, C5.1, C6.2, C7.1, C8.2, C9.1, C10.2, C11.1, C12.2, C13.1, C14.2, C15.1, C16.2, C17.1, J3.3, J3.4, J3.5, J3.6, J3.7, J3.8, U7.11, U7.13, U7.14 (VDD), U8.14 (VDD), U10.5 (+); also elsewhere on the board
unnamed: U10.6 (-), U10.7

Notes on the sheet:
unused sections
TL072 power connections
TL072 decoupling
40106 power
4013 power
bulk decoupling

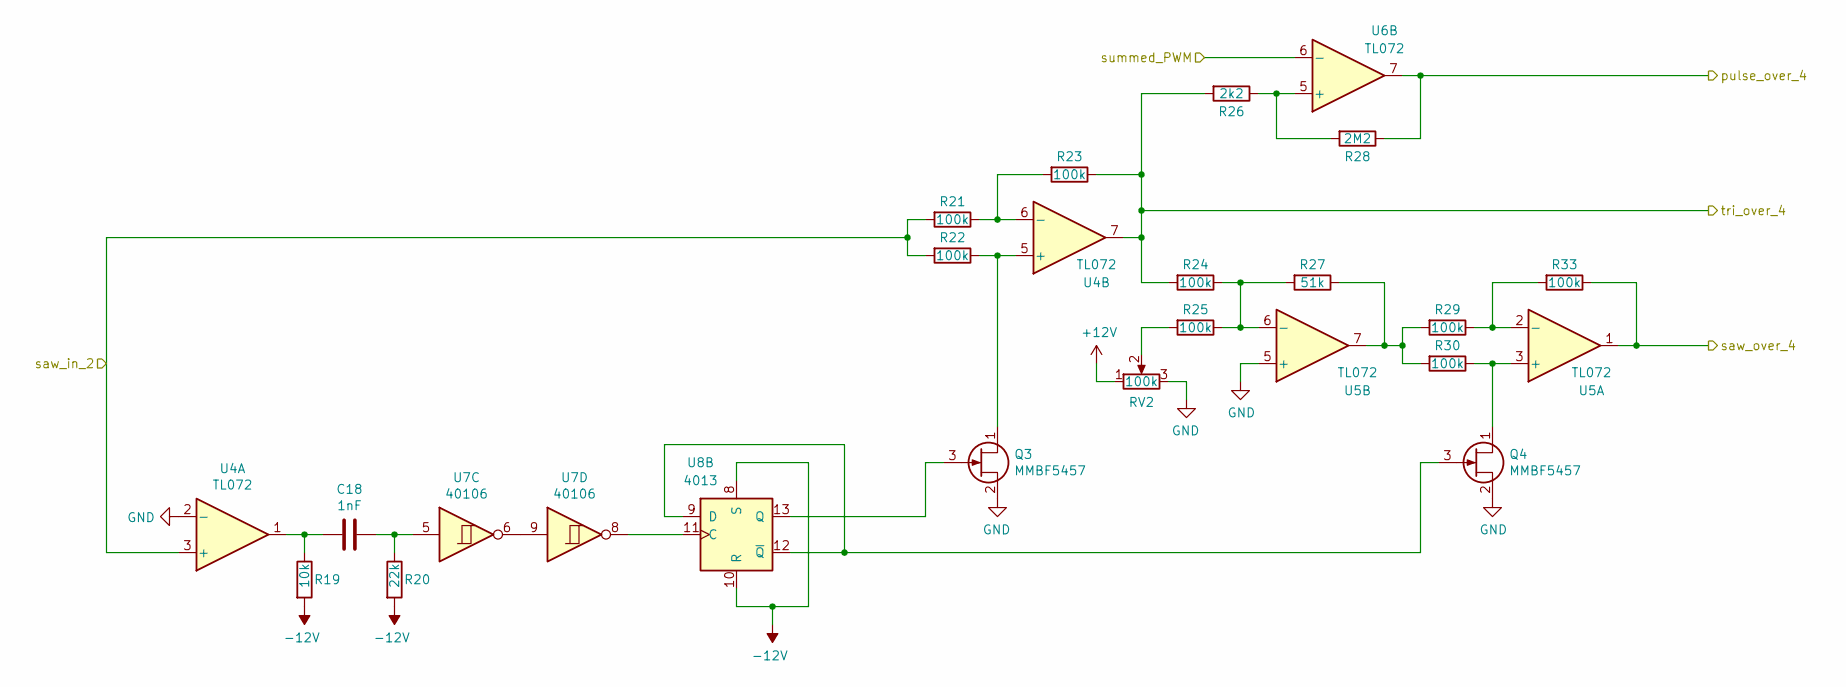
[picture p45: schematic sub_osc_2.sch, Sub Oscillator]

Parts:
C18: 1nF; C_0805_2012Metric_Pad1.15x1.40mm_HandSolder
Q3, Q4: MMBF5457; SOT-23_Handsoldering
R19: 10k; R_0805_2012Metric_Pad1.15x1.40mm_HandSolder
R20: 22k; R_0805_2012Metric_Pad1.15x1.40mm_HandSolder
R21, R22, R23, R24, R25, R29, R30, R33: 100k; R_0805_2012Metric_Pad1.15x1.40mm_HandSolder
R26: 2k2; R_0805_2012Metric_Pad1.15x1.40mm_HandSolder
R27: 51k; R_0805_2012Metric_Pad1.15x1.40mm_HandSolder
R28: 2M2; R_0805_2012Metric_Pad1.15x1.40mm_HandSolder
RV2: 100k; Potentiometer_Bourns_3296W_Vertical
U4, U5, U6: TL072; SOIC-8_3.9x4.9mm_P1.27mm
U7: 40106; SOIC-14_3.9x8.7mm_P1.27mm
U8: 4013; SOIC-14_3.9x8.7mm_P1.27mm

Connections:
+12V: RV2.1; also elsewhere on the board
-12V: R19.2, R20.2, U8.8 (S), U8.10 (R); also elsewhere on the board
/pulse_over_4: R28.1, U6.7; also elsewhere on the board
/saw_over_2: R21.2, R22.2, U4.3 (+); also elsewhere on the board
/saw_over_4: R33.1, U5.1; also elsewhere on the board
/sub_osc_1/summed_PWM: U6.6 (-); also elsewhere on the board
/tri_over_4: R23.1, R24.2, R26.2, U4.7; also elsewhere on the board
GND: Q3.2 (S), Q4.2 (S), RV2.3, U4.2 (-), U5.5 (+); also elsewhere on the board
unnamed: C18.1, R20.1, U7.5
unnamed: C18.2, R19.1, U4.1
unnamed: Q3.1 (D), R22.1, U4.5 (+)
unnamed: Q3.3 (G), U8.13 (Q)
unnamed: Q4.1 (D), R30.1, U5.3 (+)
unnamed: Q4.3 (G), U8.9 (D), U8.12 (~Q)
unnamed: R21.1, R23.2, U4.6 (-)
unnamed: R24.1, R25.1, R27.2, U5.6 (-)
unnamed: R25.2, RV2.2
unnamed: R26.1, R28.2, U6.5 (+)
unnamed: R27.1, R29.2, R30.2, U5.7
unnamed: R29.1, R33.2, U5.2 (-)
unnamed: U7.6, U7.9
unnamed: U7.8, U8.11 (C)

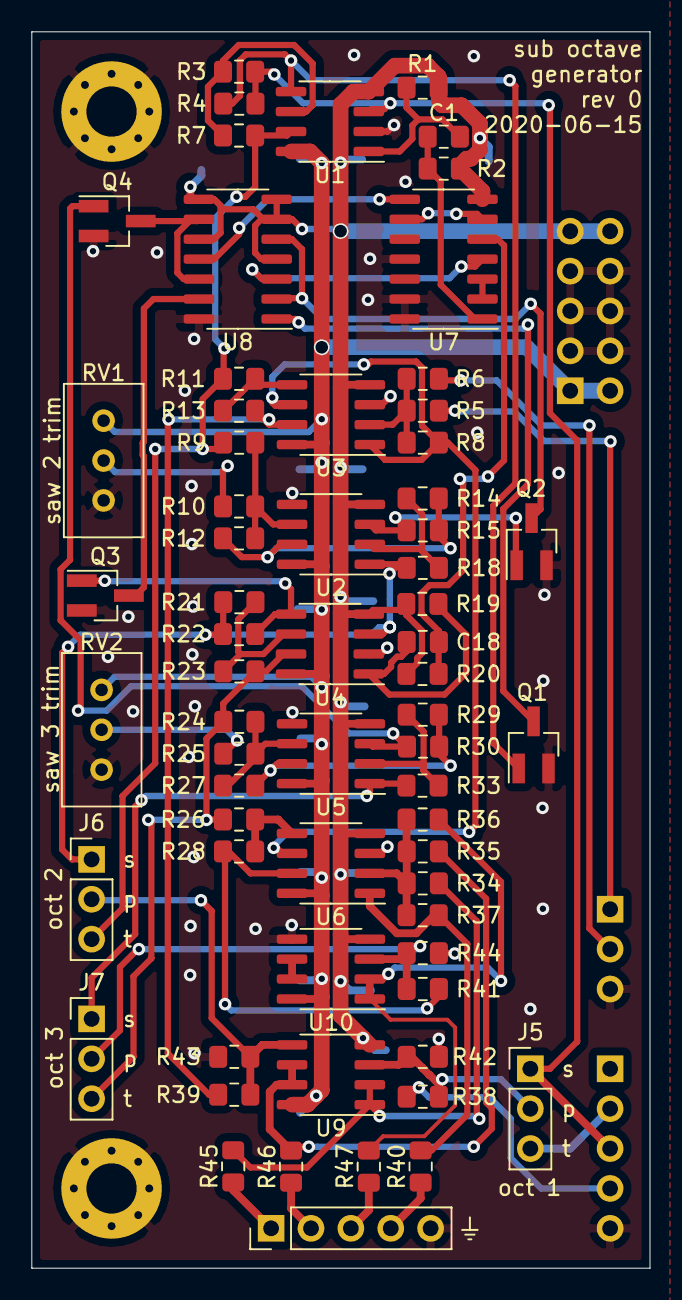
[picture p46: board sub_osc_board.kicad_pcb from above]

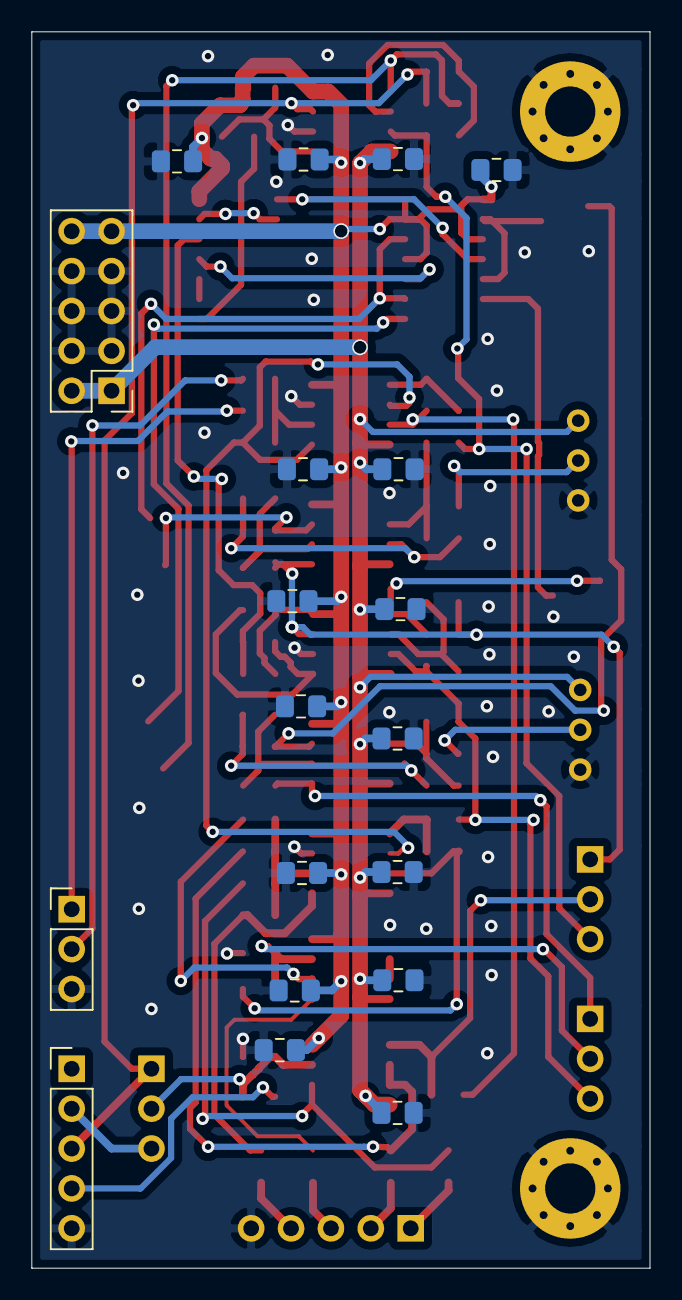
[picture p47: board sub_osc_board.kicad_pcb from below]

Board: 2 copper layers, 39.4 x 78.7 mm, 86 parts (19 on the bottom side), 57 nets.

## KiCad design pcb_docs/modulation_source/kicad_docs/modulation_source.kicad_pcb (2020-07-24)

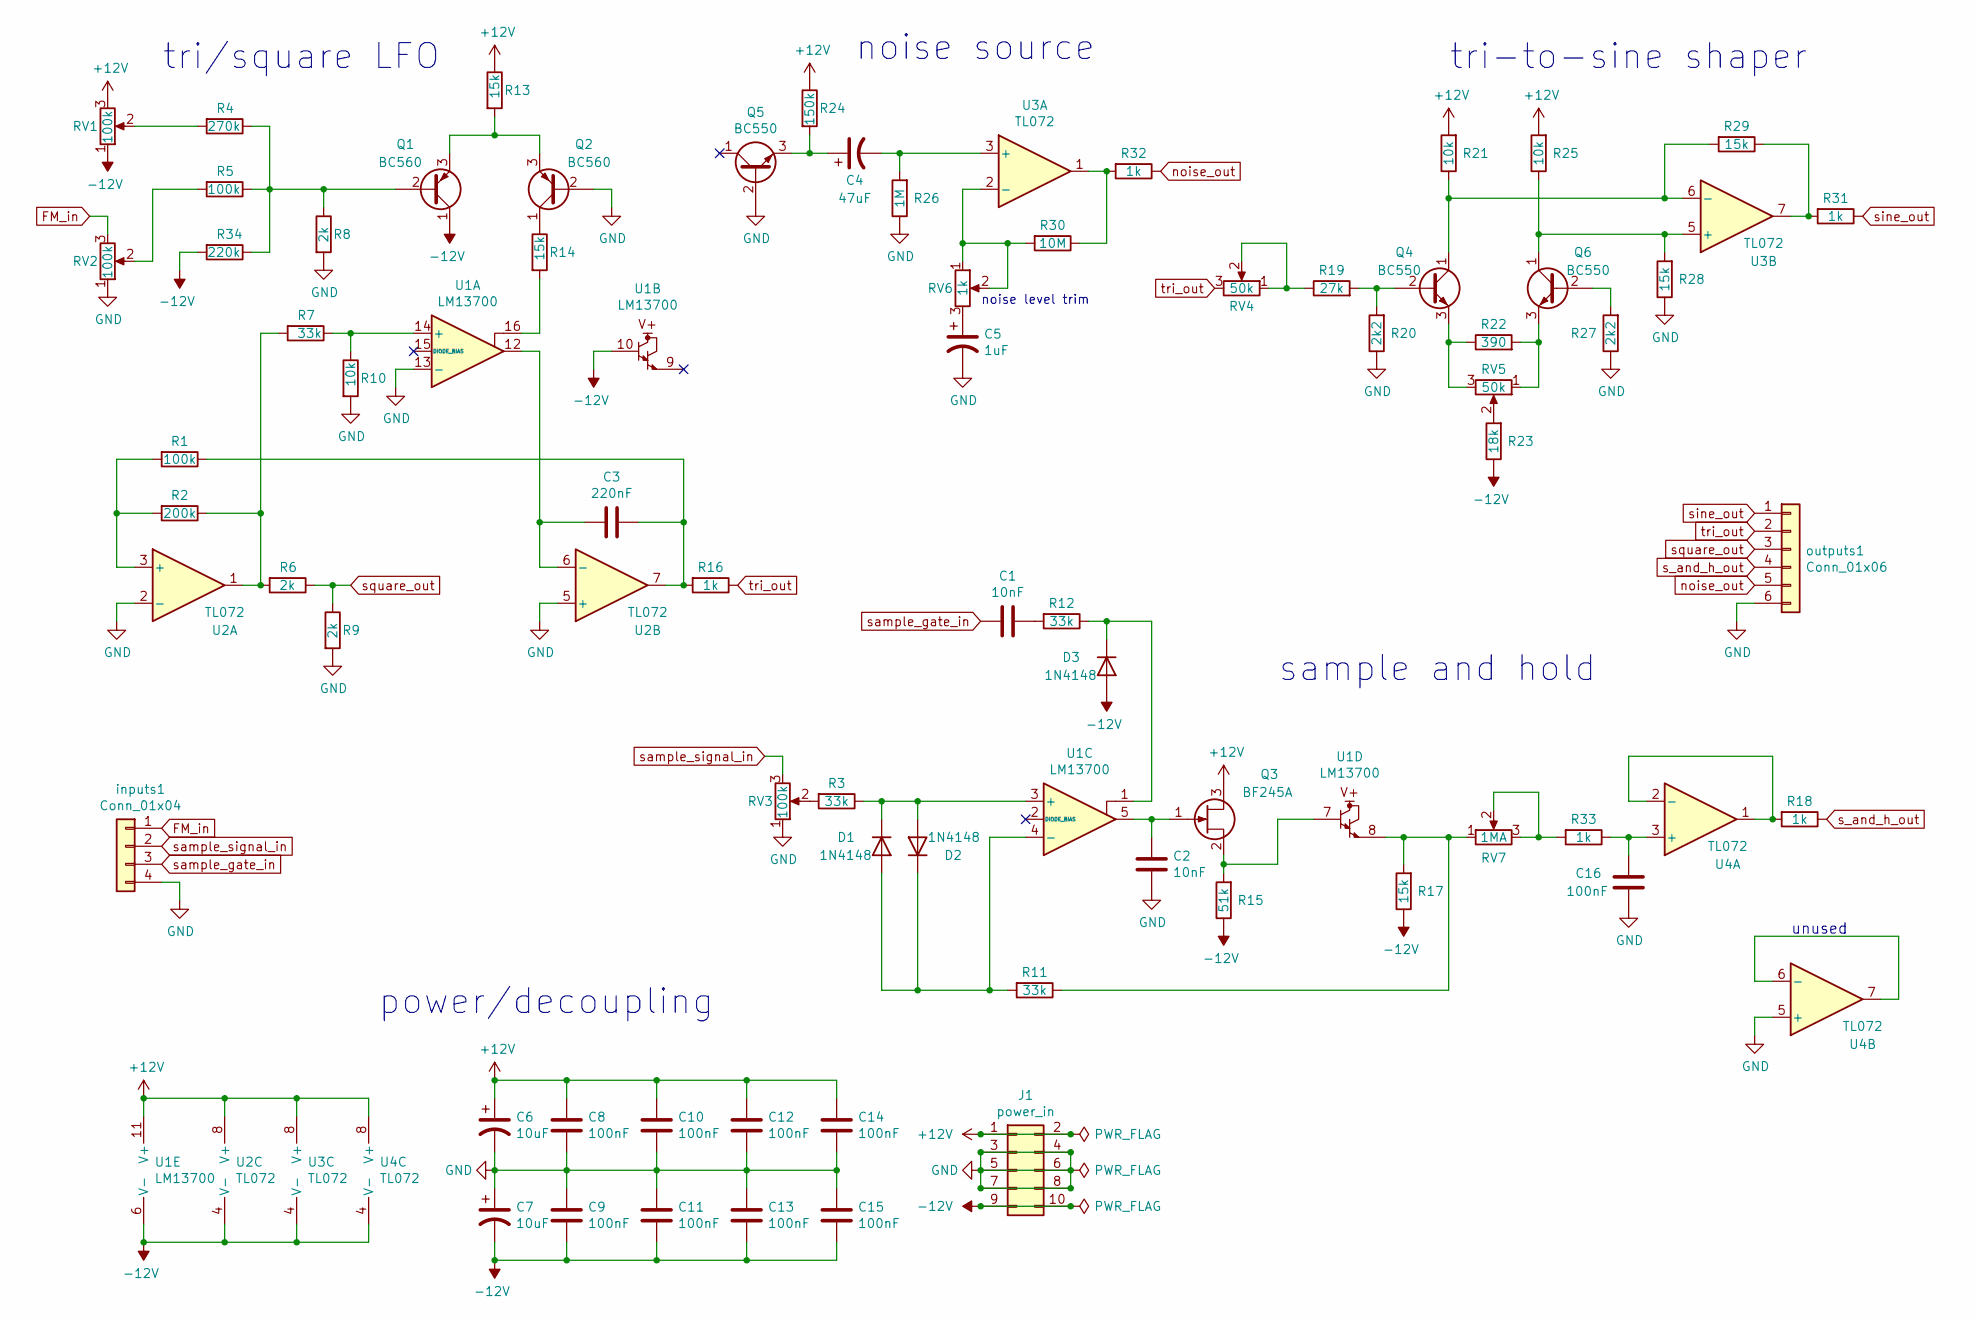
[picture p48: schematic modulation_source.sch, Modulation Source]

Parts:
C1, C2: 10nF; C_0805_2012Metric_Pad1.15x1.40mm_HandSolder
C3: 220nF; C_0805_2012Metric_Pad1.15x1.40mm_HandSolder
C4: 47uF; CP_Radial_D6.3mm_P2.50mm
C5: 1uF; CP_Radial_D6.3mm_P2.50mm
C6, C7: 10uF; CP_Radial_D6.3mm_P2.50mm
C8, C9, C10, C11, C12, C13, C14, C15, C16: 100nF; C_0805_2012Metric_Pad1.15x1.40mm_HandSolder
D1, D2, D3: 1N4148; D_DO-35_SOD27_P7.62mm_Horizontal
J1: power_in; PinHeader_2x05_P2.54mm_Vertical
Q1, Q2: BC560; TO-92_Inline
Q3: BF245A; TO-92_Inline
Q4, Q5, Q6: BC550; TO-92_Inline
R1, R5: 100k; R_0805_2012Metric_Pad1.15x1.40mm_HandSolder
R2: 200k; R_0805_2012Metric_Pad1.15x1.40mm_HandSolder
R3, R7, R11, R12: 33k; R_0805_2012Metric_Pad1.15x1.40mm_HandSolder
R4: 270k; R_0805_2012Metric_Pad1.15x1.40mm_HandSolder
R6, R8, R9: 2k; R_0805_2012Metric_Pad1.15x1.40mm_HandSolder
R10, R21, R25: 10k; R_0805_2012Metric_Pad1.15x1.40mm_HandSolder
R13, R14, R17, R28, R29: 15k; R_0805_2012Metric_Pad1.15x1.40mm_HandSolder
R15: 51k; R_0805_2012Metric_Pad1.15x1.40mm_HandSolder
R16, R18, R31, R32, R33: 1k; R_0805_2012Metric_Pad1.15x1.40mm_HandSolder
R19: 27k; R_0805_2012Metric_Pad1.15x1.40mm_HandSolder
R20, R27: 2k2; R_0805_2012Metric_Pad1.15x1.40mm_HandSolder
R22: 390; R_0805_2012Metric_Pad1.15x1.40mm_HandSolder
R23: 18k; R_0805_2012Metric_Pad1.15x1.40mm_HandSolder
R24: 150k; R_0805_2012Metric_Pad1.15x1.40mm_HandSolder
R26: 1M; R_0805_2012Metric_Pad1.15x1.40mm_HandSolder
R30: 10M; R_0805_2012Metric_Pad1.15x1.40mm_HandSolder
R34: 220k; R_0805_2012Metric_Pad1.15x1.40mm_HandSolder
RV1, RV2, RV3: 100k; Potentiometer_Alpha_RD901F-40-00D_Single_Vertical
RV4, RV5: 50k; Potentiometer_Bourns_3296W_Vertical
RV6: 1k; Potentiometer_Bourns_3296W_Vertical
RV7: 1MA; Potentiometer_Alpha_RD901F-40-00D_Single_Vertical
U1: LM13700; DIP-16_W7.62mm
U2, U3, U4: TL072; DIP-8_W7.62mm
inputs1: Conn_01x04; PinHeader_1x04_P2.54mm_Vertical
outputs1: Conn_01x06; PinHeader_1x06_P2.54mm_Vertical

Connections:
+12V: C6.1, C8.1, C10.1, C12.1, C14.1, J1.1, J1.2, Q3.3 (D), R13.1, R21.2, R24.1, R25.2, RV1.3, U1.11 (V+), U2.8 (V+), U3.8 (V+), U4.8 (V+)
-12V: C7.2, C9.2, C11.2, C13.2, C15.2, D3.2 (A), J1.9, J1.10, Q1.1 (C), R15.1, R17.1, R23.1, R34.2, RV1.1, U1.6 (V-), U1.10, U2.4 (V-), U3.4 (V-), U4.4 (V-)
FM_in: RV2.3, inputs1.1
GND: C2.1, C5.2, C6.2, C7.1, C8.2, C9.1, C10.2, C11.1, C12.2, C13.1, C14.2, C15.1, C16.2, J1.3, J1.4, J1.5, J1.6, J1.7, J1.8, Q2.2 (B), Q5.2 (B), R8.2, R9.2, R10.2, R20.1, R26.1, R27.1, R28.1, RV2.1, RV3.1, U1.13 (-), U2.2 (-), U2.5 (+), U4.5 (+), inputs1.4, outputs1.6
unnamed: C1.1, R12.2
unnamed: C2.2, Q3.1 (G), U1.5
unnamed: C3.1, R1.1, R16.2, U2.7
unnamed: C3.2, U1.12, U2.6 (-)
unnamed: C4.1, Q5.3 (E), R24.2
unnamed: C4.2, R26.2, U3.3 (+)
unnamed: C5.1, RV6.3
unnamed: C16.1, R33.1, U4.3 (+)
unnamed: D1.1 (K), D2.2 (A), R3.1, U1.3 (+)
unnamed: D1.2 (A), D2.1 (K), R11.2, U1.4 (-)
unnamed: D3.1 (K), R12.1, U1.1
unnamed: Q1.2 (B), R4.1, R5.1, R8.1, R34.1
unnamed: Q1.3 (E), Q2.3 (E), R13.2
unnamed: Q2.1 (C), R14.1
unnamed: Q3.2 (S), R15.2, U1.7
unnamed: Q4.1 (C), R21.1, R29.2, U3.6 (-)
unnamed: Q4.2 (B), R19.2, R20.2
unnamed: Q4.3 (E), R22.1, RV5.3
unnamed: Q6.1 (C), R25.1, R28.2, U3.5 (+)
unnamed: Q6.2 (B), R27.2
unnamed: Q6.3 (E), R22.2, RV5.1
unnamed: R1.2, R2.2, U2.3 (+)
unnamed: R2.1, R6.2, R7.2, U2.1
unnamed: R3.2, RV3.2
unnamed: R4.2, RV1.2
unnamed: R5.2, RV2.2
unnamed: R7.1, R10.1, U1.14 (+)
unnamed: R11.1, R17.2, RV7.1, U1.8
unnamed: R14.2, U1.16
unnamed: R18.2, U4.1, U4.2 (-)
unnamed: R19.1, RV4.1, RV4.2
unnamed: R23.2, RV5.2
unnamed: R29.1, R31.2, U3.7
unnamed: R30.1, R32.2, U3.1
unnamed: R30.2, RV6.1, RV6.2, U3.2 (-)
unnamed: R33.2, RV7.2, RV7.3
unnamed: U4.6 (-), U4.7
noise_out: R32.1, outputs1.5
s_and_h_out: R18.1, outputs1.4
sample_gate_in: C1.2, inputs1.3
sample_signal_in: RV3.3, inputs1.2
sine_out: R31.1, outputs1.1
square_out: R6.1, R9.1, outputs1.3
tri_out: R16.1, RV4.3, outputs1.2

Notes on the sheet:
noise level trim
tri/square LFO
noise source
tri-to-sine shaper
sample and hold
unused
power/decoupling

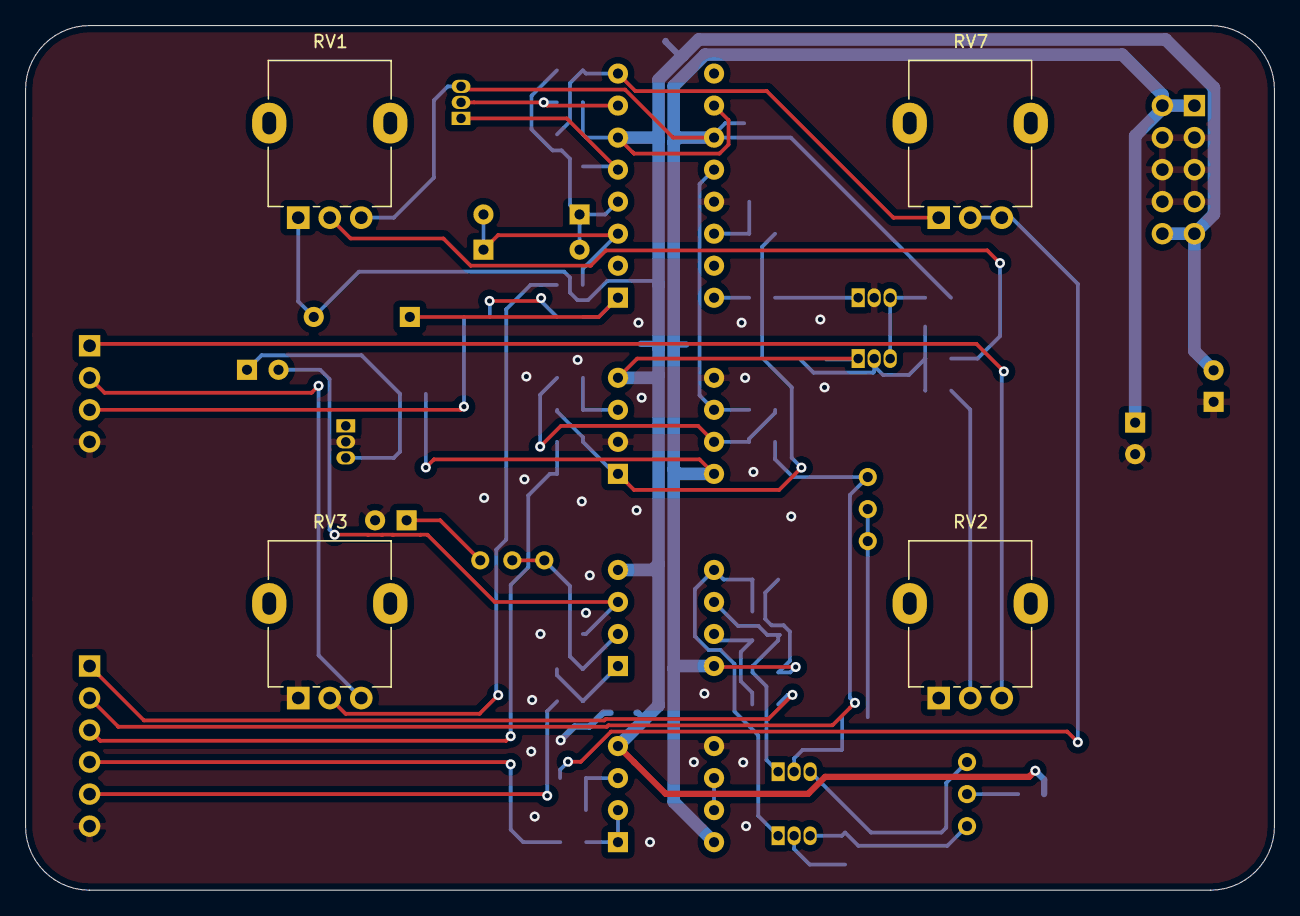
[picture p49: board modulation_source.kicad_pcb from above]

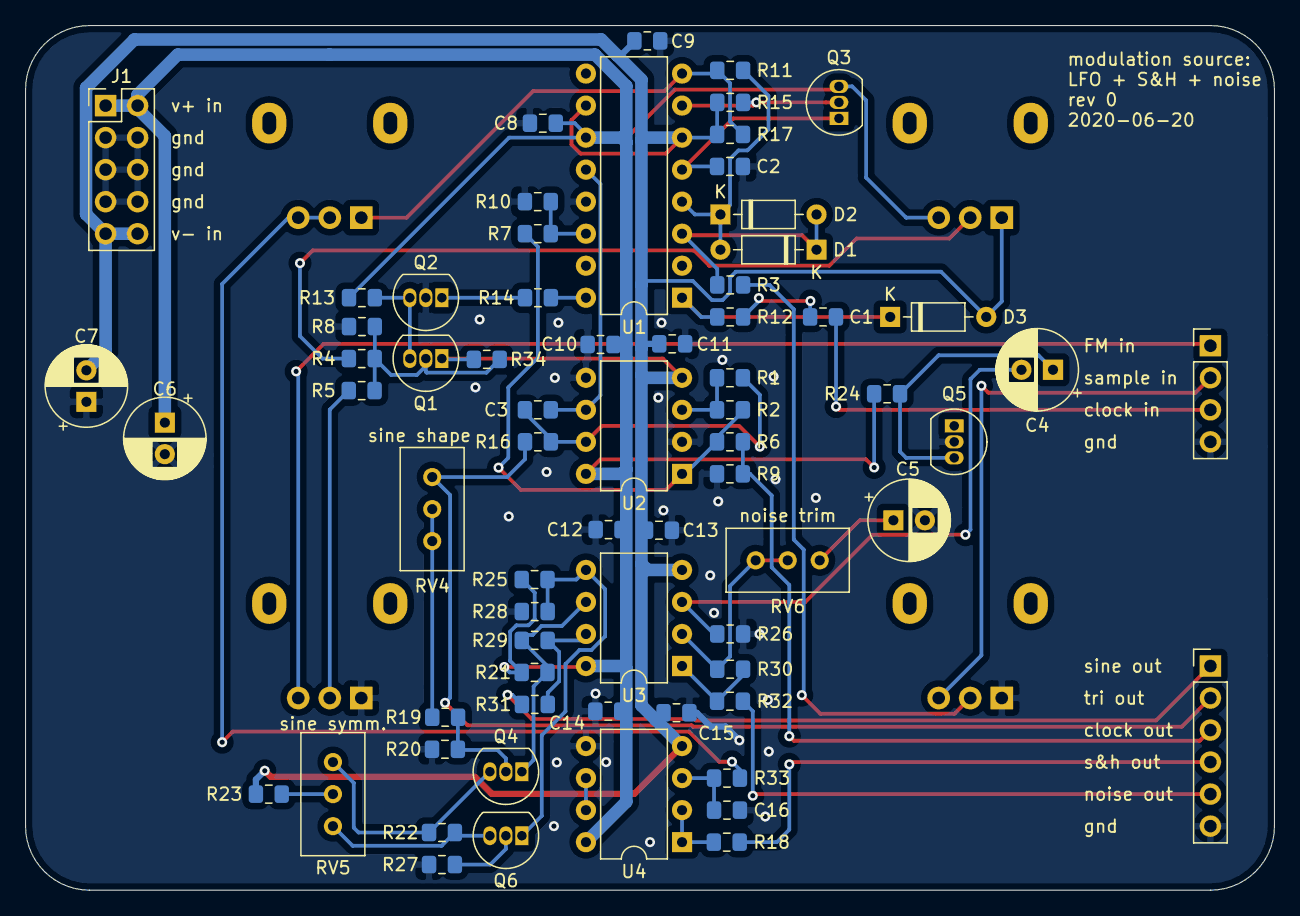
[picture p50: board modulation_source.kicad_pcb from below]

Board: 2 copper layers, 99.1 x 68.6 mm, 73 parts (69 on the bottom side), 48 nets.

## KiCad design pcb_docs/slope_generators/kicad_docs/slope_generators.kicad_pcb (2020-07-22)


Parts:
J1: slope_1_port; PinHeader_1x07_P2.54mm_Vertical
J2: slope_2_port; PinHeader_1x07_P2.54mm_Vertical

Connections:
/slope_1_end_out: J1.6; also elsewhere on the board
/slope_1_out: J1.5; also elsewhere on the board
/slope_2_end_out: J2.6; also elsewhere on the board
/slope_2_out: J2.5; also elsewhere on the board
/slope_generator_1/CV_in: J1.2; also elsewhere on the board
/slope_generator_1/expo_CV_in: J1.1; also elsewhere on the board
/slope_generator_1/gate_in: J1.3; also elsewhere on the board
/slope_generator_1/trig_in: J1.4; also elsewhere on the board
/slope_generator_2/CV_in: J2.2; also elsewhere on the board
/slope_generator_2/expo_CV_in: J2.1; also elsewhere on the board
/slope_generator_2/gate_in: J2.3; also elsewhere on the board
/slope_generator_2/trig_in: J2.4; also elsewhere on the board
GND: J1.7, J2.7; also elsewhere on the board


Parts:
C1, C2: 1nF; C_0805_2012Metric_Pad1.15x1.40mm_HandSolder
C3, C4: 47pF; C_0805_2012Metric_Pad1.15x1.40mm_HandSolder
C5: 22nF; C_0805_2012Metric_Pad1.15x1.40mm_HandSolder
D1, D2, D3, D4, D5, D7: D; D_SOD-123
D6: 5v6; D_SOD-123
D8: LED; LED_D5.0mm
Q1, Q2, Q4: MMBT3906; SOT-23_Handsoldering
Q3, Q5, Q6: MMBT3904; SOT-23_Handsoldering
R1: 270k; R_0805_2012Metric_Pad1.15x1.40mm_HandSolder
R2, R3, R4, R6, R7, R8, R9, R10, R15, R17, R28, R30: 100k; R_0805_2012Metric_Pad1.15x1.40mm_HandSolder
R5, R16: 560k; R_0805_2012Metric_Pad1.15x1.40mm_HandSolder
R11, R12, R13, R14: 33k; R_0805_2012Metric_Pad1.15x1.40mm_HandSolder
R18, R21, R29: 82k; R_0805_2012Metric_Pad1.15x1.40mm_HandSolder
R19, R20: 47k; R_0805_2012Metric_Pad1.15x1.40mm_HandSolder
R22, R24: 820k; R_0805_2012Metric_Pad1.15x1.40mm_HandSolder
R23, R26, R27, R34: 220k; R_0805_2012Metric_Pad1.15x1.40mm_HandSolder
R25: 68k; R_0805_2012Metric_Pad1.15x1.40mm_HandSolder
R31, R32, R41: 2k2; R_0805_2012Metric_Pad1.15x1.40mm_HandSolder
R33: 1k8; R_0805_2012Metric_Pad1.15x1.40mm_HandSolder
R35, R38: 10M; R_0805_2012Metric_Pad1.15x1.40mm_HandSolder
R36: 8k2; R_0805_2012Metric_Pad1.15x1.40mm_HandSolder
R37: 330k; R_0805_2012Metric_Pad1.15x1.40mm_HandSolder
R39, R40: 1M; R_0805_2012Metric_Pad1.15x1.40mm_HandSolder
R42, R45: 1k; R_0805_2012Metric_Pad1.15x1.40mm_HandSolder
R43: 100; R_0805_2012Metric_Pad1.15x1.40mm_HandSolder
R44: 150k; R_0805_2012Metric_Pad1.15x1.40mm_HandSolder
RV1, RV2, RV3: 100k; Potentiometer_Alpha_RD901F-40-00D_Single_Vertical
RV4: 100k; Potentiometer_Bourns_3296W_Vertical
SW1: lin_expo_switch; SPDT_on_on
SW2: auto_cycle_switch; SPDT_on_on
SW3: rise-fall-both-switch; SPDT_on_on
U1, U2: TL072; SOIC-8_3.9x4.9mm_P1.27mm
U3: LM3900; SOIC-14_3.9x8.7mm_P1.27mm

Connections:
+12V: D8.2 (A), Q1.2 (E), R1.1, R25.2, R38.2, RV2.3, RV3.3; also elsewhere on the board
-12V: R5.1, R16.1, R27.1; also elsewhere on the board
/slope_1_end_out: D2.1 (K), D4.1 (K), R42.1, SW2.3 (C); also elsewhere on the board
/slope_1_out: R37.2, R43.1, R44.2, RV4.3, SW1.3 (C); also elsewhere on the board
/slope_generator_1/CV_in: RV1.3; also elsewhere on the board
/slope_generator_1/expo_CV_in: R29.2; also elsewhere on the board
/slope_generator_1/fall_CV: Q4.1 (B), R17.2, R20.1, R21.1, R32.1
/slope_generator_1/gate_in: R28.2, R30.2; also elsewhere on the board
/slope_generator_1/rise_CV: Q3.1 (B), R15.2, R16.2, R18.1, R19.1, R31.1
/slope_generator_1/trig_in: C1.2, R6.1; also elsewhere on the board
GND: D6.2 (A), D7.2 (A), Q2.3 (C), Q3.3 (C), Q6.2 (E), R6.2, R7.2, R8.2, R9.2, R28.1, R31.2, R32.2, R33.2, RV1.1, RV2.1, RV3.1, RV4.1, SW3.2 (B), U1.3 (+), U1.5 (+), U2.3 (+), U3.2 (2IN+); also elsewhere on the board
unnamed: C1.1, R8.1, R11.2
unnamed: C2.1, R9.1, R12.2
unnamed: C2.2, R7.1, SW2.2 (B)
unnamed: C3.1, R22.1, U3.10 (4OUT)
unnamed: C3.2, R22.2, U3.8 (3IN-)
unnamed: C4.1, R35.2
unnamed: C4.2, R30.1, U2.6 (-)
unnamed: C5.1, R34.1, R43.2, U2.1
unnamed: C5.2, Q4.3 (C), Q5.3 (C), U2.2 (-)
unnamed: D1.1 (K), D3.1 (K), U3.13 (3IN+)
unnamed: D1.2 (A), D2.2 (A), R11.1
unnamed: D3.2 (A), D4.2 (A), R12.1
unnamed: D5.1 (K), Q1.3 (C), R27.2
unnamed: D5.2 (A), R34.2, U2.5 (+)
unnamed: D6.1 (K), R41.1, R42.2
unnamed: D7.1 (K), Q6.1 (B), R44.1
unnamed: D8.1 (K), R45.2
unnamed: Q1.1 (B), R23.2, R25.1
unnamed: Q2.1 (B), Q5.1 (B), R29.1, R33.1
unnamed: Q2.2 (E), Q3.2 (E), Q4.2 (E), Q5.2 (E), R36.1
unnamed: Q6.3 (C), R45.1
unnamed: R1.2, SW1.1 (A)
unnamed: R2.1, R3.2, U1.2 (-)
unnamed: R2.2, RV1.2
unnamed: R4.2, R5.2, R10.1, U1.6 (-)
unnamed: R10.2, R17.1, U1.7
unnamed: R13.1, R19.2, SW3.1 (A)
unnamed: R3.1, R13.2, R14.2, U1.1
unnamed: R14.1, R20.2, SW3.3 (C)
unnamed: R4.1, R15.1, SW1.2 (B)
unnamed: R18.2, RV2.2
unnamed: R21.2, RV3.2
unnamed: R23.1, R24.2, U3.9 (3OUT)
unnamed: R24.1, U3.11 (4IN-)
unnamed: R26.1, U3.12 (4IN+)
unnamed: R26.2, RV4.2
unnamed: R35.1, R36.2, U2.7
unnamed: R37.1, R38.1, U3.6 (1IN-)
unnamed: R39.1, R40.1, R41.2, U3.5 (1OUT)
unnamed: R39.2, U3.1 (1IN+)
unnamed: R40.2, U3.3 (2IN-)

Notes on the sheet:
rise
fall
center off
adjust for reliable triggering and +5v peak output


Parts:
C6, C7, C8, C9, C10, C11, C12, C13, C14, C15: 100nF; C_0805_2012Metric_Pad1.15x1.40mm_HandSolder
C16, C17: 10uF; CP_Radial_D6.3mm_P2.50mm
J3: power_in; PinHeader_2x05_P2.54mm_Vertical
U1, U2, U4, U5: TL072; SOIC-8_3.9x4.9mm_P1.27mm
U3, U6: LM3900; SOIC-14_3.9x8.7mm_P1.27mm

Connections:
+12V: C6.1, C7.1, C8.1, C10.1, C12.1, C14.1, C16.1, J3.1, J3.2, U1.8 (V+), U2.8 (V+), U3.14 (Vcc), U4.8 (V+), U5.8 (V+), U6.14 (Vcc); also elsewhere on the board
-12V: C9.2, C11.2, C13.2, C15.2, C17.2, J3.9, J3.10, U1.4 (V-), U2.4 (V-), U4.4 (V-), U5.4 (V-); also elsewhere on the board
GND: C6.2, C7.2, C8.2, C9.1, C10.2, C11.1, C12.2, C13.1, C14.2, C15.1, C16.2, C17.1, J3.3, J3.4, J3.5, J3.6, J3.7, J3.8, U3.7 (GND), U6.7 (GND); also elsewhere on the board


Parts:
C18, C19: 1nF; C_0805_2012Metric_Pad1.15x1.40mm_HandSolder
C20, C21: 47pF; C_0805_2012Metric_Pad1.15x1.40mm_HandSolder
C22: 22nF; C_0805_2012Metric_Pad1.15x1.40mm_HandSolder
D9, D10, D11, D12, D13, D15: D; D_SOD-123
D14: 5v6; D_SOD-123
D16: LED; LED_D5.0mm
Q7, Q8, Q10: MMBT3906; SOT-23_Handsoldering
Q9, Q11, Q12: MMBT3904; SOT-23_Handsoldering
R46: 270k; R_0805_2012Metric_Pad1.15x1.40mm_HandSolder
R47, R48, R49, R51, R52, R53, R54, R55, R60, R62, R73, R75: 100k; R_0805_2012Metric_Pad1.15x1.40mm_HandSolder
R50, R61: 560k; R_0805_2012Metric_Pad1.15x1.40mm_HandSolder
R56, R57, R58, R59: 33k; R_0805_2012Metric_Pad1.15x1.40mm_HandSolder
R63, R66, R74: 82k; R_0805_2012Metric_Pad1.15x1.40mm_HandSolder
R64, R65: 47k; R_0805_2012Metric_Pad1.15x1.40mm_HandSolder
R67, R69: 820k; R_0805_2012Metric_Pad1.15x1.40mm_HandSolder
R68, R71, R72, R79: 220k; R_0805_2012Metric_Pad1.15x1.40mm_HandSolder
R70: 68k; R_0805_2012Metric_Pad1.15x1.40mm_HandSolder
R76, R77, R86: 2k2; R_0805_2012Metric_Pad1.15x1.40mm_HandSolder
R78: 1k8; R_0805_2012Metric_Pad1.15x1.40mm_HandSolder
R80, R83: 10M; R_0805_2012Metric_Pad1.15x1.40mm_HandSolder
R81: 8k2; R_0805_2012Metric_Pad1.15x1.40mm_HandSolder
R82: 330k; R_0805_2012Metric_Pad1.15x1.40mm_HandSolder
R84, R85: 1M; R_0805_2012Metric_Pad1.15x1.40mm_HandSolder
R87, R90: 1k; R_0805_2012Metric_Pad1.15x1.40mm_HandSolder
R88: 100; R_0805_2012Metric_Pad1.15x1.40mm_HandSolder
R89: 150k; R_0805_2012Metric_Pad1.15x1.40mm_HandSolder
RV5, RV6, RV7: 100k; Potentiometer_Alpha_RD901F-40-00D_Single_Vertical
RV8: 100k; Potentiometer_Bourns_3296W_Vertical
SW4: lin_expo_switch; SPDT_on_on
SW5: auto_cycle_switch; SPDT_on_on
SW6: rise-fall-both-switch; SPDT_on_on
U4, U5: TL072; SOIC-8_3.9x4.9mm_P1.27mm
U6: LM3900; SOIC-14_3.9x8.7mm_P1.27mm

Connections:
+12V: D16.2 (A), Q7.2 (E), R46.1, R70.2, R83.2, RV6.3, RV7.3; also elsewhere on the board
-12V: R50.1, R61.1, R72.1; also elsewhere on the board
/slope_2_end_out: D10.1 (K), D12.1 (K), R87.1, SW5.3 (C); also elsewhere on the board
/slope_2_out: R82.2, R88.1, R89.2, RV8.3, SW4.3 (C); also elsewhere on the board
/slope_generator_2/CV_in: RV5.3; also elsewhere on the board
/slope_generator_2/expo_CV_in: R74.2; also elsewhere on the board
/slope_generator_2/fall_CV: Q10.1 (B), R62.2, R65.1, R66.1, R77.1
/slope_generator_2/gate_in: R73.2, R75.2; also elsewhere on the board
/slope_generator_2/rise_CV: Q9.1 (B), R60.2, R61.2, R63.1, R64.1, R76.1
/slope_generator_2/trig_in: C18.2, R51.1; also elsewhere on the board
GND: D14.2 (A), D15.2 (A), Q8.3 (C), Q9.3 (C), Q12.2 (E), R51.2, R52.2, R53.2, R54.2, R73.1, R76.2, R77.2, R78.2, RV5.1, RV6.1, RV7.1, RV8.1, SW6.2 (B), U4.3 (+), U4.5 (+), U5.3 (+), U6.2 (2IN+); also elsewhere on the board
unnamed: C18.1, R53.1, R56.2
unnamed: C19.1, R54.1, R57.2
unnamed: C19.2, R52.1, SW5.2 (B)
unnamed: C20.1, R67.1, U6.10 (4OUT)
unnamed: C20.2, R67.2, U6.8 (3IN-)
unnamed: C21.1, R80.2
unnamed: C21.2, R75.1, U5.6 (-)
unnamed: C22.1, R79.1, R88.2, U5.1
unnamed: C22.2, Q10.3 (C), Q11.3 (C), U5.2 (-)
unnamed: D9.2 (A), D10.2 (A), R56.1
unnamed: D9.1 (K), D11.1 (K), U6.13 (3IN+)
unnamed: D11.2 (A), D12.2 (A), R57.1
unnamed: D13.1 (K), Q7.3 (C), R72.2
unnamed: D13.2 (A), R79.2, U5.5 (+)
unnamed: D14.1 (K), R86.1, R87.2
unnamed: D15.1 (K), Q12.1 (B), R89.1
unnamed: D16.1 (K), R90.2
unnamed: Q7.1 (B), R68.2, R70.1
unnamed: Q8.2 (E), Q9.2 (E), Q10.2 (E), Q11.2 (E), R81.1
unnamed: Q8.1 (B), Q11.1 (B), R74.1, R78.1
unnamed: Q12.3 (C), R90.1
unnamed: R46.2, SW4.1 (A)
unnamed: R47.1, R48.2, U4.2 (-)
unnamed: R47.2, RV5.2
unnamed: R48.1, R58.2, R59.2, U4.1
unnamed: R49.1, R60.1, SW4.2 (B)
unnamed: R49.2, R50.2, R55.1, U4.6 (-)
unnamed: R55.2, R62.1, U4.7
unnamed: R58.1, R64.2, SW6.1 (A)
unnamed: R59.1, R65.2, SW6.3 (C)
unnamed: R63.2, RV6.2
unnamed: R66.2, RV7.2
unnamed: R68.1, R69.2, U6.9 (3OUT)
unnamed: R69.1, U6.11 (4IN-)
unnamed: R71.1, U6.12 (4IN+)
unnamed: R71.2, RV8.2
unnamed: R80.1, R81.2, U5.7
unnamed: R82.1, R83.1, U6.6 (1IN-)
unnamed: R84.1, R85.1, R86.2, U6.5 (1OUT)
unnamed: R84.2, U6.1 (1IN+)
unnamed: R85.2, U6.3 (2IN-)

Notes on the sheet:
rise
fall
center off
adjust for reliable triggering and +5v peak output

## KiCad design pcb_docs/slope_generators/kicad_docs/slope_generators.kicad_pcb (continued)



Board: 2 copper layers, 99.1 x 99.1 mm, 163 parts (149 on the bottom side), 101 nets.

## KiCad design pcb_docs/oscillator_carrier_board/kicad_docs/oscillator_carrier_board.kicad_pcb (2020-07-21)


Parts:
J1: Conn_01x06; PinHeader_1x06_P2.54mm_Vertical
J2: Conn_01x05; PinHeader_1x05_P2.54mm_Vertical
J3: power_header; PinHeader_2x05_P2.54mm_Vertical

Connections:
+12V: J3.9, J3.10; also elsewhere on the board
-12V: J3.1, J3.2; also elsewhere on the board
/VCO_core_components/1v_oct_in: J1.1; also elsewhere on the board
/VCO_core_components/PWM_in: J1.5; also elsewhere on the board
/VCO_core_components/expo_FM_in: J1.2; also elsewhere on the board
/VCO_core_components/lin_FM_in: J1.3; also elsewhere on the board
/VCO_core_components/sync_in: J1.4; also elsewhere on the board
/aux_waveshaper_components/pulse_in: J2.4; also elsewhere on the board
/aux_waveshaper_components/saw_in: J2.3; also elsewhere on the board
/aux_waveshaper_components/sine_in: J2.1; also elsewhere on the board
/aux_waveshaper_components/tri_in: J2.2; also elsewhere on the board
GND: J1.6, J2.5, J3.3, J3.4, J3.5, J3.6, J3.7, J3.8; also elsewhere on the board


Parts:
C1, C2, C3, C4: 100nF; C_0805_2012Metric_Pad1.15x1.40mm_HandSolder
H1, H2: MountingHole_Pad; MountingHole_3.2mm_M3_Pad_Via
J4: Conn_01x04; PinSocket_1x04_P2.54mm_Vertical
J5, J6: Conn_01x02; PinSocket_1x02_P2.54mm_Vertical
J7, J10: Conn_01x05; PinSocket_1x05_P2.54mm_Vertical
J8: power_header; PinSocket_2x05_P2.54mm_Vertical
J9: to_VCO_board; PinSocket_1x05_P2.54mm_Vertical
R1, R2, R3, R4, R5, R6: 1k; R_0805_2012Metric_Pad1.15x1.40mm_HandSolder
R7: 68k; R_0805_2012Metric_Pad1.15x1.40mm_HandSolder
RV1, RV2, RV3, RV4, RV5: 100k; alpha_RV24AF-40
RV6: 50k; Potentiometer_Bourns_3296W_Vertical
SW1: octave_switch; apha_SR2612F-0112
TP1, TP2: TestPoint; TestPoint_Keystone_5000-5004_Miniature
U1: TL072; SOIC-8_3.9x4.9mm_P1.27mm

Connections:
+5V: J7.3, J10.3, R1.2, RV4.3, RV5.3, SW1.7
+12V: C3.1, J8.9, J8.10, U1.8 (V+); also elsewhere on the board
-5V: J7.5, J10.5, RV4.1, RV5.1
-12V: C4.2, J8.1, J8.2, U1.4 (V-); also elsewhere on the board
/VCO_core_components/1v_oct_in: J4.1; also elsewhere on the board
/VCO_core_components/PWM_in: RV3.3; also elsewhere on the board
/VCO_core_components/expo_FM_in: RV1.3; also elsewhere on the board
/VCO_core_components/lin_FM_in: RV2.3; also elsewhere on the board
/VCO_core_components/sync_in: J6.1; also elsewhere on the board
/aux_waveshaper_components/man_pulse_in: J7.1, RV4.2; also elsewhere on the board
/aux_waveshaper_components/pulse_in: J9.4; also elsewhere on the board
/aux_waveshaper_components/saw_in: J9.3; also elsewhere on the board
/aux_waveshaper_components/sine_in: J9.1; also elsewhere on the board
/aux_waveshaper_components/tri_in: J9.2; also elsewhere on the board
GND: C1.2, C2.2, C3.2, C4.1, H1.1, H2.1, J4.3, J4.4, J5.2, J6.2, J7.4, J8.3, J8.4, J8.5, J8.6, J8.7, J8.8, J9.5, J10.4, R6.1, R7.2, RV1.1, RV2.1, RV3.1, SW1.1, TP1.1, U1.5 (+); also elsewhere on the board
unnamed: C1.1, SW1.13, U1.3 (+)
unnamed: C2.1, J10.2, RV5.2
unnamed: J4.2, RV1.2
unnamed: J5.1, RV2.2
unnamed: J7.2, RV3.2
unnamed: J10.1, RV6.2, RV6.3, TP2.1, U1.1
unnamed: R1.1, R2.2, SW1.6
unnamed: R2.1, R3.2, SW1.5
unnamed: R3.1, R4.2, SW1.4
unnamed: R4.1, R5.2, SW1.3
unnamed: R5.1, R6.2, SW1.2
unnamed: R7.1, RV6.1, U1.2 (-)
unnamed: U1.6 (-), U1.7

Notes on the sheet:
expo fm lev
lin fm lev
pwm lev
manual pulse width
fine tune
octave switch trim
use 0.5% tolerance or better for R1 through R6


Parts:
H3, H4: MountingHole_Pad; MountingHole_3.2mm_M3_Pad_Via
J11: Conn_01x05; PinSocket_1x05_P2.54mm_Vertical
J12: Conn_01x03; PinSocket_1x03_P2.54mm_Vertical
J13: power_header; PinSocket_2x05_P2.54mm_Vertical

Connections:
+12V: J13.9, J13.10; also elsewhere on the board
-12V: J13.1, J13.2; also elsewhere on the board
/VCO_core_components/PWM_in: J12.2; also elsewhere on the board
/aux_waveshaper_components/man_pulse_in: J12.1; also elsewhere on the board
/aux_waveshaper_components/pulse_in: J11.4; also elsewhere on the board
/aux_waveshaper_components/saw_in: J11.3; also elsewhere on the board
/aux_waveshaper_components/sine_in: J11.1; also elsewhere on the board
/aux_waveshaper_components/tri_in: J11.2; also elsewhere on the board
GND: H3.1, H4.1, J11.5, J12.3, J13.3, J13.4, J13.5, J13.6, J13.7, J13.8; also elsewhere on the board



Board: 2 copper layers, 99.1 x 99.1 mm, 38 parts (26 on the bottom side), 28 nets.

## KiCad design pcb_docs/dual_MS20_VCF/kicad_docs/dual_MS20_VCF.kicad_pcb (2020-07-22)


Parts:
C9, C10: 10uF; CP_Radial_D6.3mm_P2.50mm
C11, C12, C13, C14, C15, C16, C17, C18, C19, C20, C21, C22, C23, C24: 100nF; C_0805_2012Metric_Pad1.15x1.40mm_HandSolder
J1, J2: Conn_01x05; PinHeader_1x05_P2.54mm_Vertical
J3: power_in; PinHeader_2x05_P2.54mm_Vertical
J4: lpf_output_normal; PinHeader_1x02_P2.54mm_Vertical
R36, R37, R38, R39, R41: 100k; R_Axial_DIN0207_L6.3mm_D2.5mm_P10.16mm_Horizontal
R40, R42: 1k; R_Axial_DIN0207_L6.3mm_D2.5mm_P10.16mm_Horizontal
RV3, RV4, RV5, RV6: 100k; Potentiometer_Alpha_RD901F-40-00D_Single_Vertical
U1, U4: LM13700; DIP-16_W7.62mm
U2, U3, U5, U6: MC1458; DIP-8_W7.62mm
U7: TL072; DIP-8_W7.62mm

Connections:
+12V: C9.1, C11.1, C13.1, C15.1, C17.1, C19.1, C21.1, C23.1, J3.1, J3.2, RV5.3, RV6.3, U1.11 (V+), U2.8 (V+), U3.8 (V+), U4.11 (V+), U5.8 (V+), U6.8 (V+), U7.8 (V+)
-12V: C10.2, C12.2, C14.2, C16.2, C18.2, C20.2, C22.2, C24.2, J3.9, J3.10, RV5.1, RV6.1, U1.6 (V-), U2.4 (V-), U3.4 (V-), U4.6 (V-), U5.4 (V-), U6.4 (V-), U7.4 (V-); also elsewhere on the board
/HPF/hpf_cv_in_1: J1.3; also elsewhere on the board
/HPF/hpf_cv_in_2: RV3.2; also elsewhere on the board
/HPF/hpf_cv_in_3: RV5.2; also elsewhere on the board
/HPF/hpf_in: J1.1; also elsewhere on the board
/LPF/lpf_cv_in_1: J2.3; also elsewhere on the board
/LPF/lpf_cv_in_2: RV4.2; also elsewhere on the board
/LPF/lpf_cv_in_3: RV6.2; also elsewhere on the board
/LPF/lpf_in: J2.1; also elsewhere on the board
/LPF/lpf_out: R40.2; also elsewhere on the board
/high_pass: R36.2; also elsewhere on the board
/low_pass: J2.2, R40.1
/summed_hp_lp: J1.2, R42.1
GND: C9.2, C10.1, C11.2, C12.1, C13.2, C14.1, C15.2, C16.1, C17.2, C18.1, C19.2, C20.1, C21.2, C22.1, C23.2, C24.1, J1.5, J2.5, J3.3, J3.4, J3.5, J3.6, J3.7, J3.8, J4.2, RV3.1, RV4.1, U7.3 (+), U7.5 (+); also elsewhere on the board
unnamed: J1.4, RV3.3
unnamed: J2.4, RV4.3
unnamed: J4.1, R37.2
unnamed: R36.1, R37.1, R38.2, U7.2 (-)
unnamed: R38.1, R39.2, U7.1
unnamed: R39.1, R41.2, U7.6 (-)
unnamed: R41.1, R42.2, U7.7

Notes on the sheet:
Summer for HP/LP parallel operation. Intended for use with normalized jacks to achieve series, parallel, and independent modes depending on which set of jacks are used.


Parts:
C1, C3: 1nF; C_Rect_L7.0mm_W2.5mm_P5.00mm
C2: 4n7; C_Rect_L7.0mm_W2.5mm_P5.00mm
C4: 470nF; C_Rect_L7.0mm_W3.5mm_P5.00mm
D1, D2: green; LED_D5.0mm
Q1, Q2: BC558; TO-92_Inline
R1, R3, R12, R15: 220; R_Axial_DIN0207_L6.3mm_D2.5mm_P10.16mm_Horizontal
R2, R7, R11, R13, R14, R17: 10k; R_Axial_DIN0207_L6.3mm_D2.5mm_P10.16mm_Horizontal
R4, R5: 100k; R_Axial_DIN0207_L6.3mm_D2.5mm_P10.16mm_Horizontal
R6: 240k; R_Axial_DIN0207_L6.3mm_D2.5mm_P10.16mm_Horizontal
R8, R16: 1k8; R_Axial_DIN0207_L6.3mm_D2.5mm_P10.16mm_Horizontal
R9: 470k; R_Axial_DIN0207_L6.3mm_D2.5mm_P10.16mm_Horizontal
R10: 4k7; R_Axial_DIN0207_L6.3mm_D2.5mm_P10.16mm_Horizontal
RV1: 100k; Potentiometer_Alpha_RD901F-40-00D_Single_Vertical
U1: LM13700; DIP-16_W7.62mm
U2, U3: MC1458; DIP-8_W7.62mm

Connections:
-12V: R9.2; also elsewhere on the board
/HPF/hpf_cv_in_1: R4.2; also elsewhere on the board
/HPF/hpf_cv_in_2: R5.2; also elsewhere on the board
/HPF/hpf_cv_in_3: R6.2; also elsewhere on the board
/HPF/hpf_in: C3.2; also elsewhere on the board
/HPF/i_out: Q2.1 (C), R7.1, R17.1
/high_pass: C4.1, RV1.3; also elsewhere on the board
GND: Q2.2 (B), R1.2, R3.2, R8.2, R12.2, R15.2, R16.2, RV1.1, U3.5 (+); also elsewhere on the board
unnamed: C1.1, U1.5, U2.3 (+)
unnamed: C1.2, D1.2 (A), D2.1 (K), R13.2, U3.1
unnamed: C2.1, R10.1, U3.7
unnamed: C2.2, Q1.1 (C), R9.1, U3.6 (-)
unnamed: C3.1, U1.12, U2.5 (+)
unnamed: C4.2, R14.1, U2.6 (-), U2.7
unnamed: D1.1 (K), D2.2 (A), R13.1, R16.1, U3.2 (-)
unnamed: Q1.2 (B), R4.1, R5.1, R6.1, R8.1
unnamed: Q1.3 (E), Q2.3 (E), R10.2
unnamed: R1.1, R2.2, U1.4 (-)
unnamed: R3.1, U1.3 (+)
unnamed: R7.2, U1.1
unnamed: R11.1, R15.1, U1.14 (+)
unnamed: R2.1, R11.2, U2.1, U2.2 (-)
unnamed: R12.1, R14.2, U1.13 (-)
unnamed: R17.2, U1.16
unnamed: RV1.2, U3.3 (+)

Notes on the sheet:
unused buffers

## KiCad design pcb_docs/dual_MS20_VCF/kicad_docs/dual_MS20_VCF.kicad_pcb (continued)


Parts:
C5, C7: 1nF; C_Rect_L7.0mm_W2.5mm_P5.00mm
C6: 4n7; C_Rect_L7.0mm_W2.5mm_P5.00mm
C8: 470nF; C_Rect_L7.0mm_W3.5mm_P5.00mm
D3, D4: green; LED_D5.0mm
Q3, Q4: BC558; TO-92_Inline
R18, R20, R25, R29, R31, R32, R35: 10k; R_Axial_DIN0207_L6.3mm_D2.5mm_P10.16mm_Horizontal
R19, R21, R30, R33: 220; R_Axial_DIN0207_L6.3mm_D2.5mm_P10.16mm_Horizontal
R22, R23: 100k; R_Axial_DIN0207_L6.3mm_D2.5mm_P10.16mm_Horizontal
R24: 240k; R_Axial_DIN0207_L6.3mm_D2.5mm_P10.16mm_Horizontal
R26, R34: 1k8; R_Axial_DIN0207_L6.3mm_D2.5mm_P10.16mm_Horizontal
R27: 470k; R_Axial_DIN0207_L6.3mm_D2.5mm_P10.16mm_Horizontal
R28: 4k7; R_Axial_DIN0207_L6.3mm_D2.5mm_P10.16mm_Horizontal
RV2: 100k; Potentiometer_Alpha_RD901F-40-00D_Single_Vertical
U4: LM13700; DIP-16_W7.62mm
U5, U6: MC1458; DIP-8_W7.62mm

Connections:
-12V: R27.2; also elsewhere on the board
/LPF/i_out: Q4.1 (C), R25.1, R35.1
/LPF/lpf_cv_in_1: R22.2; also elsewhere on the board
/LPF/lpf_cv_in_2: R23.2; also elsewhere on the board
/LPF/lpf_cv_in_3: R24.2; also elsewhere on the board
/LPF/lpf_in: R18.2; also elsewhere on the board
/LPF/lpf_out: C8.1, RV2.3; also elsewhere on the board
GND: C7.2, Q4.2 (B), R19.2, R21.2, R26.2, R30.2, R33.2, R34.2, RV2.1, U6.5 (+); also elsewhere on the board
unnamed: C5.1, U4.5, U5.3 (+)
unnamed: C5.2, D3.2 (A), D4.1 (K), R31.2, U6.1
unnamed: C6.1, R28.1, U6.7
unnamed: C6.2, Q3.1 (C), R27.1, U6.6 (-)
unnamed: C7.1, U4.12, U5.5 (+)
unnamed: C8.2, R32.1, U5.6 (-), U5.7
unnamed: D3.1 (K), D4.2 (A), R31.1, R34.1, U6.2 (-)
unnamed: Q3.2 (B), R22.1, R23.1, R24.1, R26.1
unnamed: Q3.3 (E), Q4.3 (E), R28.2
unnamed: R18.1, R19.1, R20.2, U4.4 (-)
unnamed: R20.1, R29.2, U5.1, U5.2 (-)
unnamed: R21.1, U4.3 (+)
unnamed: R25.2, U4.1
unnamed: R29.1, R33.1, U4.14 (+)
unnamed: R30.1, R32.2, U4.13 (-)
unnamed: R35.2, U4.16
unnamed: RV2.2, U6.3 (+)

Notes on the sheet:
unused buffers



Board: 2 copper layers, 99.1 x 99.1 mm, 91 parts (71 on the bottom side), 58 nets.

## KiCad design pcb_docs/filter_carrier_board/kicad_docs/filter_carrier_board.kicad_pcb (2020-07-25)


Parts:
C1, C2: 10uF; CP_Radial_D6.3mm_P2.50mm
C3, C4, C5, C6, C7, C8, C9, C10, C11: 100nF; C_Axial_L3.8mm_D2.6mm_P7.50mm_Horizontal
J1: CV_inputs; PinHeader_1x04_P2.54mm_Vertical
J2: signal_inputs; PinHeader_1x04_P2.54mm_Vertical
J3: dry_out; PinHeader_1x02_P2.54mm_Vertical
J4, J5, J7: Conn_01x04; PinSocket_1x04_P2.54mm_Vertical
J6: CV_out; PinHeader_1x02_P2.54mm_Vertical
J8: Conn_01x08; PinSocket_1x08_P2.54mm_Vertical
J9: wet_out; PinHeader_1x02_P2.54mm_Vertical
J10: Conn_02x05_Odd_Even; PinHeader_2x05_P2.54mm_Vertical
R1, R2, R3, R4, R5, R6, R7, R8, R9, R10, R11, R12, R15: 100k; R_Axial_DIN0207_L6.3mm_D2.5mm_P10.16mm_Horizontal
R13, R16, R17: 1k; R_Axial_DIN0207_L6.3mm_D2.5mm_P10.16mm_Horizontal
R14: 22k; R_Axial_DIN0207_L6.3mm_D2.5mm_P10.16mm_Horizontal
R18: 12k; R_Axial_DIN0207_L6.3mm_D2.5mm_P10.16mm_Horizontal
R19, R20: 10k; R_Axial_DIN0207_L6.3mm_D2.5mm_P10.16mm_Horizontal
RV1, RV2, RV3, RV4, RV5, RV6, RV7: 100k; Potentiometer_Alpha_RD901F-40-00D_Single_Vertical
RV8: 10k; Potentiometer_Alpha_RD901F-40-00D_Single_Vertical
U1, U2, U4: TL072; DIP-8_W7.62mm
U3: MAX6035xxUR50; SOT-23_Handsoldering

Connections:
+5V: C8.1, R18.1, R19.2, RV4.3, U3.2 (OUT)
+12V: C1.1, C3.1, C5.1, C7.1, C10.1, J8.7, J8.8, J10.1, J10.2, U1.8 (V+), U2.8 (V+), U3.1 (IN), U4.8 (V+)
-5V: C9.2, R10.2, R20.1, RV4.1, U4.7
-12V: C2.2, C4.2, C6.2, C11.2, J8.5, J8.6, J10.9, J10.10, U1.4 (V-), U2.4 (V-), U4.4 (V-)
GND: C1.2, C2.1, C3.2, C4.1, C5.2, C6.1, C7.2, C8.2, C10.2, C11.1, J1.4, J2.4, J3.2, J4.1, J4.2, J5.1, J5.2, J6.2, J7.1, J7.2, J8.1, J8.2, J9.2, J10.3, J10.4, J10.5, J10.6, J10.7, J10.8, RV1.1, RV2.1, RV3.1, RV5.1, RV6.1, RV7.1, RV8.1, U1.3 (+), U1.5 (+), U2.3 (+), U2.5 (+), U3.3 (GND), U4.5 (+)
unnamed: C9.1, R19.1, R20.2, U4.6 (-)
unnamed: J1.1, RV5.3
unnamed: J1.2, RV6.3
unnamed: J1.3, RV7.3
unnamed: J2.1, RV1.3
unnamed: J2.2, RV2.3
unnamed: J2.3, RV3.3
unnamed: J3.1, R13.1
unnamed: J4.3, J4.4, R8.1, R13.2, U1.1
unnamed: J5.3, J5.4, R14.1, U2.7
unnamed: J6.1, R16.1
unnamed: J7.3, J7.4, R17.2
unnamed: J8.3, J8.4, U4.1, U4.2 (-)
unnamed: J9.1, R17.1
unnamed: R1.1, R2.1, R3.1, R8.2, U1.2 (-)
unnamed: R1.2, RV1.2
unnamed: R2.2, RV2.2
unnamed: R3.2, RV3.2
unnamed: R4.1, R5.1, R6.1, R7.1, R9.2, U2.2 (-)
unnamed: R4.2, RV4.2
unnamed: R5.2, RV5.2
unnamed: R6.2, RV6.2
unnamed: R7.2, RV7.2
unnamed: R10.1, R11.1, R14.2, U2.6 (-)
unnamed: R9.1, R11.2, R12.2, U2.1
unnamed: R12.1, R15.2, U1.6 (-)
unnamed: R15.1, R16.2, U1.7
unnamed: R18.2, RV8.3
unnamed: RV8.2, U4.3 (+)

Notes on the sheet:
manual frequency
Tnis carrier board is designed to accomodate various VCF plug-in boards. These plug-in boards share a consistent footprint and voltage standard. VCF plug in boards expect CV in the range 0 to +2.048v. This range is the same for both frequency control voltage as well as resonance control coltage.
approximately 0 to +2.048 volts
VCF plug-in board port
feedback



Board: 2 copper layers, 99.1 x 99.1 mm, 52 parts (44 on the bottom side), 34 nets.

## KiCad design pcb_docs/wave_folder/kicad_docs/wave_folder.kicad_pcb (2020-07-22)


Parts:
J1: signal_port; PinHeader_1x03_P2.54mm_Vertical
J2: CV_port; PinHeader_1x04_P2.54mm_Vertical
J3: ring_mod_port; PinHeader_1x04_P2.54mm_Vertical

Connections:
/folds_CV_in: J2.1; also elsewhere on the board
/ring_mod_out: J3.3; also elsewhere on the board
/ring_mod_x_in: J3.1; also elsewhere on the board
/ring_mod_y_in: J3.2; also elsewhere on the board
/shape_CV_in: J2.2; also elsewhere on the board
/signal_in: J1.1; also elsewhere on the board
/signal_out: J1.2; also elsewhere on the board
/symmetry_CV_in: J2.3; also elsewhere on the board
GND: J1.3, J2.4, J3.4; also elsewhere on the board


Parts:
D1, D2, D3, D4, D5, D6, D7, D8, D9, D10, D11, D12, D13, D14, D15, D16, D17, D18: D; D_A-405_P7.62mm_Horizontal
R1, R2, R3, R4, R6, R7, R8, R9: 15k; R_Axial_DIN0207_L6.3mm_D2.5mm_P10.16mm_Horizontal
R5, R10: 5k6; R_Axial_DIN0207_L6.3mm_D2.5mm_P10.16mm_Horizontal
R11: 56k; R_Axial_DIN0207_L6.3mm_D2.5mm_P10.16mm_Horizontal
U3, U4: TL072; DIP-8_W7.62mm

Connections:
/core/core_i_in: R1.2, R2.2, R3.2, R4.2, R5.2, U3.6 (-); also elsewhere on the board
/core/core_out: D17.1 (K), D18.2 (A), R11.1, U4.7; also elsewhere on the board
/core/core_v_in: D8.2 (A), D16.1 (K); also elsewhere on the board
GND: U3.5 (+), U4.5 (+); also elsewhere on the board
unnamed: D1.1 (K), D9.2 (A), R1.1
unnamed: D1.2 (A), D2.1 (K), D9.1 (K), D10.2 (A), R6.2
unnamed: D2.2 (A), D3.1 (K), D10.1 (K), D11.2 (A), R2.1
unnamed: D3.2 (A), D4.1 (K), D11.1 (K), D12.2 (A), R7.2
unnamed: D4.2 (A), D5.1 (K), D12.1 (K), D13.2 (A), R3.1
unnamed: D5.2 (A), D6.1 (K), D13.1 (K), D14.2 (A), R8.2
unnamed: D6.2 (A), D7.1 (K), D14.1 (K), D15.2 (A), R4.1
unnamed: D7.2 (A), D8.1 (K), D15.1 (K), D16.2 (A), R9.2
unnamed: D17.2 (A), D18.1 (K), R6.1, R7.1, R8.1, R9.1, R10.1, R11.2, U4.6 (-)
unnamed: R5.1, R10.2, U3.7


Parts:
C1: 100pF; C_Disc_D4.3mm_W1.9mm_P5.00mm
C2, C3: 560pF; C_Disc_D4.3mm_W1.9mm_P5.00mm
R12: dnf; R_Axial_DIN0207_L6.3mm_D2.5mm_P10.16mm_Horizontal
R13, R17: 100k; R_Axial_DIN0207_L6.3mm_D2.5mm_P10.16mm_Horizontal
R14: 220k; R_Axial_DIN0207_L6.3mm_D2.5mm_P10.16mm_Horizontal
R15: 4k7; R_Axial_DIN0207_L6.3mm_D2.5mm_P10.16mm_Horizontal
R16, R19: 510; R_Axial_DIN0207_L6.3mm_D2.5mm_P10.16mm_Horizontal
R18: 240k; R_Axial_DIN0207_L6.3mm_D2.5mm_P10.16mm_Horizontal
U1: SSM2164; DIP-16_W7.62mm
U2: TL072; DIP-8_W7.62mm

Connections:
-12V: R12.2, R18.1; also elsewhere on the board
/folds_CV: R13.2; also elsewhere on the board
/folds_VCA/folds_VCA_signal_i_out: U1.4; also elsewhere on the board
/manual_folds: R14.2; also elsewhere on the board
/signal_in: R17.2; also elsewhere on the board
GND: C2.2, C3.2, U2.3 (+); also elsewhere on the board
unnamed: C1.1, R15.2, U1.6, U2.1
unnamed: C1.2, R12.1, R13.1, R14.1, U1.5, U2.2 (-)
unnamed: C2.1, R16.1
unnamed: C3.1, R19.1
unnamed: R15.1, U1.3
unnamed: R16.2, R18.2, U1.7
unnamed: R17.1, R19.2, U1.2


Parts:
R20: 7k5; R_Axial_DIN0207_L6.3mm_D2.5mm_P10.16mm_Horizontal
R21: 82k; R_Axial_DIN0207_L6.3mm_D2.5mm_P10.16mm_Horizontal
R22: 1k; R_Axial_DIN0207_L6.3mm_D2.5mm_P10.16mm_Horizontal
U4: TL072; DIP-8_W7.62mm

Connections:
/core/core_out: U4.3 (+); also elsewhere on the board
/signal_out: R22.2; also elsewhere on the board
GND: R20.1; also elsewhere on the board
unnamed: R20.2, R21.1, U4.2 (-)
unnamed: R21.2, R22.1, U4.1


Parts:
D19, D20: D; D_A-405_P7.62mm_Horizontal
R23: 220k; R_Axial_DIN0207_L6.3mm_D2.5mm_P10.16mm_Horizontal
R24: 100k; R_Axial_DIN0207_L6.3mm_D2.5mm_P10.16mm_Horizontal
R25: 180k; R_Axial_DIN0207_L6.3mm_D2.5mm_P10.16mm_Horizontal
R26: 33k; R_Axial_DIN0207_L6.3mm_D2.5mm_P10.16mm_Horizontal
R27: 2k7; R_Axial_DIN0207_L6.3mm_D2.5mm_P10.16mm_Horizontal
U3: TL072; DIP-8_W7.62mm

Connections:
/core/core_v_in: R25.1, R26.1, U3.1; also elsewhere on the board
/folds_VCA/folds_VCA_signal_i_out: D19.2 (A), D20.1 (K), R23.1, R24.1, R25.2, U3.2 (-); also elsewhere on the board
/manual_symmetry: R23.2; also elsewhere on the board
/symmetry_CV: R24.2; also elsewhere on the board
GND: R27.2, U3.3 (+); also elsewhere on the board
unnamed: D19.1 (K), D20.2 (A), R26.2, R27.1

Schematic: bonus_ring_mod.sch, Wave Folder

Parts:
R28: 5k6; R_Axial_DIN0207_L6.3mm_D2.5mm_P10.16mm_Horizontal
R29: 1k; R_Axial_DIN0207_L6.3mm_D2.5mm_P10.16mm_Horizontal
U5: AD534; DIP-14_W7.62mm

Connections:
+12V: U5.14 (+Vs); also elsewhere on the board
-12V: R28.2, U5.8 (-Vs); also elsewhere on the board
/ring_mod_out: R29.1; also elsewhere on the board
/ring_mod_x_in: U5.1 (X1); also elsewhere on the board
/ring_mod_y_in: U5.6 (Y1); also elsewhere on the board
GND: U5.2 (X2), U5.7 (Y2); also elsewhere on the board
unnamed: R28.1, U5.4 (SF)
unnamed: R29.2, U5.12 (OUT)

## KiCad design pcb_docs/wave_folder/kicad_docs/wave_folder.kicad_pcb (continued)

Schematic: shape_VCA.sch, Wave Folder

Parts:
C4: 100pF; C_Disc_D4.3mm_W1.9mm_P5.00mm
C5, C6: 560pF; C_Disc_D4.3mm_W1.9mm_P5.00mm
R30: 10M; R_Axial_DIN0207_L6.3mm_D2.5mm_P10.16mm_Horizontal
R31: 100k; R_Axial_DIN0207_L6.3mm_D2.5mm_P10.16mm_Horizontal
R32: 220k; R_Axial_DIN0207_L6.3mm_D2.5mm_P10.16mm_Horizontal
R33: 4k7; R_Axial_DIN0207_L6.3mm_D2.5mm_P10.16mm_Horizontal
R34, R37: 510; R_Axial_DIN0207_L6.3mm_D2.5mm_P10.16mm_Horizontal
R35: 27k; R_Axial_DIN0207_L6.3mm_D2.5mm_P10.16mm_Horizontal
R36: 240k; R_Axial_DIN0207_L6.3mm_D2.5mm_P10.16mm_Horizontal
U1: SSM2164; DIP-16_W7.62mm
U2: TL072; DIP-8_W7.62mm

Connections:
-12V: R30.2, R36.1; also elsewhere on the board
/core/core_i_in: U1.12; also elsewhere on the board
/core/core_v_in: R35.2; also elsewhere on the board
/manual_shape: R32.2; also elsewhere on the board
/shape_CV: R31.2; also elsewhere on the board
GND: C5.2, C6.2, U2.5 (+); also elsewhere on the board
unnamed: C4.1, R33.2, U1.14, U2.7
unnamed: C4.2, R30.1, R31.1, R32.1, U1.13, U2.6 (-)
unnamed: C5.1, R34.1
unnamed: C6.1, R37.1
unnamed: R33.1, U1.11
unnamed: R34.2, R36.2, U1.15
unnamed: R35.1, R37.2, U1.10

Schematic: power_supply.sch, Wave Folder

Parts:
C7, C8: 10uF; CP_Radial_D6.3mm_P2.50mm
C9, C10, C11, C12, C13, C14, C15, C16, C17, C18: 100nF; C_0805_2012Metric_Pad1.15x1.40mm_HandSolder
D21: D_Schottky; D_A-405_P7.62mm_Horizontal
J4: power_in_connector; PinHeader_2x05_P2.54mm_Vertical
U1: SSM2164; DIP-16_W7.62mm
U2, U3, U4: TL072; DIP-8_W7.62mm

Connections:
+12V: C7.1, C9.1, C11.1, C13.1, C15.1, C17.1, J4.1, J4.2, U1.16 (V+), U2.8 (V+), U3.8 (V+), U4.8 (V+); also elsewhere on the board
-12V: C8.2, C10.2, C12.2, C14.2, C16.2, C18.2, D21.2 (A), J4.9, J4.10, U1.9 (V-), U2.4 (V-), U3.4 (V-), U4.4 (V-); also elsewhere on the board
GND: C7.2, C8.1, C9.2, C10.1, C11.2, C12.1, C13.2, C14.1, C15.2, C16.1, C17.2, C18.1, D21.1 (K), J4.3, J4.4, J4.5, J4.6, J4.7, J4.8, U1.8 (gnd); also elsewhere on the board

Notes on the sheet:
2164 protection

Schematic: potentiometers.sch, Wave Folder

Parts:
RV1, RV2, RV3, RV4, RV5, RV6: 100k; Potentiometer_Alpha_RD901F-40-00D_Single_Vertical

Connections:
+12V: RV1.3, RV3.3, RV5.3; also elsewhere on the board
/folds_CV: RV2.2; also elsewhere on the board
/folds_CV_in: RV2.3; also elsewhere on the board
/manual_folds: RV1.2; also elsewhere on the board
/manual_shape: RV3.2; also elsewhere on the board
/manual_symmetry: RV5.2; also elsewhere on the board
/shape_CV: RV4.2; also elsewhere on the board
/shape_CV_in: RV4.3; also elsewhere on the board
/symmetry_CV: RV6.2; also elsewhere on the board
/symmetry_CV_in: RV6.3; also elsewhere on the board
GND: RV1.1, RV2.1, RV3.1, RV4.1, RV5.1, RV6.1; also elsewhere on the board



Board: 2 copper layers, 99.1 x 99.1 mm, 91 parts (75 on the bottom side), 50 nets.

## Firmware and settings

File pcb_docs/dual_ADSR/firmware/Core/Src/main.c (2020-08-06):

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

/* Includes ------------------------------------------------------------------*/
#include "main.h"
#include "adc.h"
#include "dac.h"
#include "dma.h"
#include "tim.h"
#include "gpio.h"

/* USER CODE BEGIN Includes */

#include "../ADSR_lib/ADSR.h"
#include "../Discrete_Input_lib/Discrete_Input.h"
#include "math.h"
#include "stdbool.h"

/* USER CODE END Includes */

/* USER CODE BEGIN PTD */

/*
--| NAME: ADSR_Range_enum
--| DESCRIPTION: enumeration for either long or short range for time based params
*/
typedef enum ADSR_Range_Enumeration
{
	ADSR_RANGE_SHORT,
	ADSR_RANGE_LONG
} ADSR_Range_enum;

/* USER CODE END PTD */

/* USER CODE BEGIN PD */

/*
--| NAME: NUM_ADSRs
--| DESCRIPTION: the number of ADSR generators in the system
--| TYPE: uint
*/
#define NUM_ADSRs (2)

/*
--| NAME: SAMPLE_RATE_MSEC
--| DESCRIPTION: the sample rate for the ADSRs, in Hertz
--| TYPE: uint
*/
#define ADSR_SAMPLE_RATE_Hz (10000)

/*
--| NAME: GATE_AND_TRIGGER_DEBOUNCE_COUNT
--| DESCRIPTION: the debounce count used for discrete gate and trigger inputs
--| TYPE: uint
*/
#define GATE_AND_TRIGGER_DEBOUNCE_COUNT (5)

/*
--| NAME: RANGE_SWITCH_DEBOUNCE_COUNT
--| DESCRIPTION: the debounce count used for discrete range switch inputs
--| TYPE: uint
*/
#define RANGE_SWITCH_DEBOUNCE_COUNT (25)

/*
--| NAME: TOTAL_NUM_ADSR_INPUTS
--| DESCRIPTION: the total number of ADSR inputs. A, D, S, and R inputs for 2 ADSRs
--| TYPE: uint
*/
#define TOTAL_NUM_ADSR_INPUTS (NUM_ADSR_INPUT_TYPES * NUM_ADSRs)

/* USER CODE END PD */


/* USER CODE BEGIN PV */

/*
--| NAME: adsr
--| DESCRIPTION: the array of Attack Decay Sustain Release generators
--| TYPE: ADSR_t
*/
ADSR_t adsr[NUM_ADSRs];

/*
--| NAME: gate_input
--| DESCRIPTION: array of gate inputs
--| TYPE: Discrete_Input_t
*/
Discrete_Input_t gate_input[NUM_ADSRs] =
{
	{
		GATE_1_GPIO_Port,
		GATE_1_Pin,
		DISCRETE_INPUT_DEFAULT_INITIAL_STATE,
		DISCRETE_INPUT_POLARITY_ACTIVE_LOW,
		GATE_AND_TRIGGER_DEBOUNCE_COUNT,
		DISCRETE_INPUT_DISABLE_LONG_PRESS_COUNT,
		DEFAULT_DISCRETE_INPUT_PRIVATE_SETTING,
		DEFAULT_DISCRETE_INPUT_PRIVATE_SETTING
	},

	{
		GATE_2_GPIO_Port,
		GATE_2_Pin,
		DISCRETE_INPUT_DEFAULT_INITIAL_STATE,
		DISCRETE_INPUT_POLARITY_ACTIVE_LOW,
		GATE_AND_TRIGGER_DEBOUNCE_COUNT,
		DISCRETE_INPUT_DISABLE_LONG_PRESS_COUNT,
		DEFAULT_DISCRETE_INPUT_PRIVATE_SETTING,
		DEFAULT_DISCRETE_INPUT_PRIVATE_SETTING
	},
};

/*
--| NAME: trigger_input
--| DESCRIPTION: array of trigger inputs
--| TYPE: Discrete_Input_t
*/
Discrete_Input_t trigger_input[NUM_ADSRs] =
{
	{
		TRIGGER_1_GPIO_Port,
		TRIGGER_1_Pin,
		DISCRETE_INPUT_DEFAULT_INITIAL_STATE,
		DISCRETE_INPUT_POLARITY_ACTIVE_LOW,
		GATE_AND_TRIGGER_DEBOUNCE_COUNT,
		DISCRETE_INPUT_DISABLE_LONG_PRESS_COUNT,
		DEFAULT_DISCRETE_INPUT_PRIVATE_SETTING,
		DEFAULT_DISCRETE_INPUT_PRIVATE_SETTING
	},

	{
		TRIGGER_2_GPIO_Port,
		TRIGGER_2_Pin,
		DISCRETE_INPUT_DEFAULT_INITIAL_STATE,
		DISCRETE_INPUT_POLARITY_ACTIVE_LOW,
		GATE_AND_TRIGGER_DEBOUNCE_COUNT,
		DISCRETE_INPUT_DISABLE_LONG_PRESS_COUNT,
		DEFAULT_DISCRETE_INPUT_PRIVATE_SETTING,
		DEFAULT_DISCRETE_INPUT_PRIVATE_SETTING
	},
};

/*
--| NAME: range_switch
--| DESCRIPTION: array of range switch inputs
--| TYPE: Discrete_Input_t
*/
Discrete_Input_t range_switch[NUM_ADSRs] =
{
	{
		RANGE_1_GPIO_Port,
		RANGE_1_Pin,
		DISCRETE_INPUT_DEFAULT_INITIAL_STATE,
		DISCRETE_INPUT_POLARITY_ACTIVE_HIGH,
		RANGE_SWITCH_DEBOUNCE_COUNT,
		DISCRETE_INPUT_DISABLE_LONG_PRESS_COUNT,
		DEFAULT_DISCRETE_INPUT_PRIVATE_SETTING,
		DEFAULT_DISCRETE_INPUT_PRIVATE_SETTING
	},

	{
		RANGE_2_GPIO_Port,
		RANGE_2_Pin,
		DISCRETE_INPUT_DEFAULT_INITIAL_STATE,
		DISCRETE_INPUT_POLARITY_ACTIVE_HIGH,
		RANGE_SWITCH_DEBOUNCE_COUNT,
		DISCRETE_INPUT_DISABLE_LONG_PRESS_COUNT,
		DEFAULT_DISCRETE_INPUT_PRIVATE_SETTING,
		DEFAULT_DISCRETE_INPUT_PRIVATE_SETTING
	}
};

/*
--| NAME: raw_potentiometer_reading
--| DESCRIPTION: the raw potentiometer readings, filled via DMA
--| TYPE: uint32_t
*/
uint32_t raw_potentiometer_reading[TOTAL_NUM_ADSR_INPUTS];

/*
--| NAME: scaled_potentiometer_reading
--| DESCRIPTION: the scaled potentiometer readings
--| TYPE: uint32_t
*/
uint32_t scaled_potentiometer_reading[TOTAL_NUM_ADSR_INPUTS];

/*
--| NAME: adsr_range
--| DESCRIPTION: short or long range for each ADSR
--| TYPE: ADSR_Range_enum
*/
ADSR_Range_enum adsr_range[NUM_ADSRs];

/*
--| NAME: debug_counter
--| DESCRIPTION: a counter used for generating gate signals for testing
--| TYPE: uint32_t
*/
uint32_t debug_counter = 0;

/*
--| NAME: debug_gate
--| DESCRIPTION: boolean gate signal for testing
--| TYPE: bool
*/
bool debug_gate = 0;

/* USER CODE END PV */

void SystemClock_Config(void);
/* USER CODE BEGIN PFP */

/*------------------------------------------------------------------------------
Function Name:
    tick_ADSRs

Function Description:
    Tick the ADSRs.

Parameters:
    None.

Returns:
    None.

Assumptions/Limitations:
	Assumes that this function will be called at the defined sample rate.
------------------------------------------------------------------------------*/
void tick_ADSRs(void);

/*------------------------------------------------------------------------------
Function Name:
    poll_gate_and_trigger_inputs

Function Description:
    Poll the gate and trigger inputs and deliver gate on/off messages to the
    ADSRs.

Parameters:
    None.

Returns:
    None.

Assumptions/Limitations:
	Assumes that all initialization is complete.
------------------------------------------------------------------------------*/
void poll_gate_and_trigger_inputs(void);

/*------------------------------------------------------------------------------
Function Name:
    poll_range_switches

Function Description:
    Poll the range switches and set the range for each ADSR.

Parameters:
    None.

Returns:
    None.

Assumptions/Limitations:
	Assumes that all initialization is complete.
------------------------------------------------------------------------------*/
void poll_range_switches(void);

/*------------------------------------------------------------------------------
Function Name:
    scale_potentiometer_readings

Function Description:
    Scale the raw potentiometer readings so that they map to the desired ADSR
    parameters.

Parameters:
    None.

Returns:
    None.

Assumptions/Limitations:
	Assumes that all initialization is complete.
------------------------------------------------------------------------------*/
void scale_potentiometer_readings(void);

/*------------------------------------------------------------------------------
Function Name:
    update_ADSR_inputs

Function Description:
    Update the Attack, Decay, Sustain, and Release inputs for each of the
    four ADSRs based on the scaled potentiometer readings.

Parameters:
    None.

Returns:
    None.

Assumptions/Limitations:
	Assumes that all initialization is complete.
------------------------------------------------------------------------------*/
void update_ADSR_inputs(void);

/*------------------------------------------------------------------------------
Function Name:
    update_DACs

Function Description:
    Update the built in DACs with the current values of the ADSRs.

Parameters:
    None.

Returns:
    None.

Assumptions/Limitations:
	Assumes that all initialization is complete.
------------------------------------------------------------------------------*/
void update_DACs(void);

/* USER CODE END PFP */

/**
  * @brief  The application entry point.
  * @retval int
  */
int main(void)
{
  /* MCU Configuration--------------------------------------------------------*/

  /* Reset of all peripherals, Initializes the Flash interface and the Systick. */
  HAL_Init();

  /* Configure the system clock */
  SystemClock_Config();

  /* Initialize all configured peripherals */
  MX_GPIO_Init();
  MX_DMA_Init();
  MX_ADC1_Init();
  MX_DAC_Init();
  MX_TIM7_Init();
  MX_TIM2_Init();
  MX_TIM10_Init();
  /* USER CODE BEGIN 2 */

  // fill the adsr look up tables
  ADSR_Initialize_Look_Up_Tables();

  // initialize the adsrs with the default parameters and the defined sample rate
  for (int i = 0; i < NUM_ADSRs; ++i)
  {
	  Initialize_ADSR(&adsr[i], ADSR_SAMPLE_RATE_Hz);
  }

  // start both channels of the built-in DAC
  HAL_DAC_Start(&hdac, DAC_CHANNEL_1);
  HAL_DAC_Start(&hdac, DAC_CHANNEL_2);

  // start the sample-rate interrupt timers
  HAL_TIM_Base_Start_IT(&htim7);
  HAL_TIM_Base_Start_IT(&htim10);

  // start the ADC DMA timer and start the ADC in DMA mode
  HAL_TIM_Base_Start(&htim2);
  HAL_ADC_Start_DMA(&hadc1, raw_potentiometer_reading, TOTAL_NUM_ADSR_INPUTS);

  /* USER CODE END 2 */

  /* Infinite loop */
  /* USER CODE BEGIN WHILE */
  while (1)
  {
	  // everything happens in the interrupt routines and DMA

    /* USER CODE END WHILE */

    /* USER CODE BEGIN 3 */
  }
  /* USER CODE END 3 */
}

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
/* USER CODE BEGIN 4 */

/*
	htim7 is the faster sample rate interrupt source, it fires at the
	system sample rate for the ADSRs. When htim7 fires we calculate the
	current ADSR values and update the DACs.

	htim10 is a slower interrupt for reading the range switches and
	processing the pots.

	htim7 has higher priority than htim10, to keep a consistent periodic
	sample rate for the time critical stuff.
 */
void HAL_TIM_PeriodElapsedCallback(TIM_HandleTypeDef *htim)
{
	if (htim == &htim7)
	{
		poll_gate_and_trigger_inputs();
		tick_ADSRs();
		update_DACs();
	}
	else if (htim == &htim10)
	{
		poll_range_switches();
		scale_potentiometer_readings();
		update_ADSR_inputs();
	}
}

void tick_ADSRs(void)
{
	for (int i = 0; i < NUM_ADSRs; ++i)
	{
		ADSR_Tick(&adsr[i]);
	}
}

void poll_gate_and_trigger_inputs(void)
{
	// poll each trigger and gate input
	for (int i = 0; i < NUM_ADSRs; ++i)
	{
		Poll_Discrete_Input(&gate_input[i]);
		Poll_Discrete_Input(&trigger_input[i]);

		// start an attack phase on rising gates or rising triggers
		if (gate_input[i].state == DISCRETE_INPUT_STATE_RISING_EDGE)
		{
			ADSR_Gate_On_Event(&adsr[i]);
		}

		if (trigger_input[i].state == DISCRETE_INPUT_STATE_RISING_EDGE)
		{
			ADSR_Gate_On_Event(&adsr[i]);
		}

		// start a release phase on falling gates
		if (gate_input[i].state == DISCRETE_INPUT_STATE_FALLING_EDGE)
		{
			ADSR_Gate_Off_Event(&adsr[i]);
		}
	}
}

void poll_range_switches(void)
{
	for (int i = 0; i < NUM_ADSRs; ++i)
	{
		Poll_Discrete_Input(&range_switch[i]);

		if (range_switch[i].state == DISCRETE_INPUT_STATE_HIGH)
		{
			adsr_range[i] = ADSR_RANGE_LONG;
		}
		else
		{
			adsr_range[i] = ADSR_RANGE_SHORT;
		}
	}
}

void scale_potentiometer_readings(void)
{
	/*
	we need to apply an exponential mapping to the raw 12 bit ADC reading for each
	of the time based parameters (attack time, decay time, and release time) so that
	the potentiometers have a wide range while feeling natural. Two ranges are covered,
	short and long, based on the position of the range switches.

	Since the ADC is in 12 bit mode, the formula to get the exponent to reach some
	desired max value is given by: exponent = ln(max-value) / ln(4095)
	For example, to create a range from 1 millisecond to 5 seconds:
		ln(5000) / ln(4095) = 1.024, so we use 1.024 as our exponent

	This gives us a range of 5000 to 1, a pretty comfortable range for a standard 1-turn
	potentiometer.

	For the long range, we will use the same exponent, but also multiply by a constant value
	to shift the range up so that it covers longer times.

	The sustain values are simply linearly scaled from 12 bits to the range [0, 1000] representing
	0% to 100% sustain.

	To reduce noise, an lsb or two may be shifted away.

	This routine takes a long time to complete and could certainly be optimized.
	*/

	const double desired_max_value = 5000.0;
	const uint32_t num_ADC_bits = 12;
	const uint32_t num_ADC_bits_to_ignore = 2;
	const uint32_t num_effective_ADC_bits = num_ADC_bits - num_ADC_bits_to_ignore;
	const double ADC_full_scale = (double)(1 << num_effective_ADC_bits);
	const double exponent = log(desired_max_value) / log(ADC_full_scale);
	const uint32_t short_scaler = 1;
	const uint32_t long_scaler = 5;

	// the decay and release times feel better if they are longer than the attack, because the attack curve is truncated
	// and decay/release curves are not
	const uint32_t decay_and_release_scaler = 10;

	uint32_t range_scaler;

	if (adsr_range[0] == ADSR_RANGE_SHORT)
	{
		range_scaler = short_scaler;
	}
	else // ADSR 1 is in long range mode
	{
		range_scaler = long_scaler;
	}

	scaled_potentiometer_reading[0] = pow((raw_potentiometer_reading[0] >> num_ADC_bits_to_ignore) + 1, exponent) * range_scaler;
	scaled_potentiometer_reading[1] = pow((raw_potentiometer_reading[1] >> num_ADC_bits_to_ignore) + 1, exponent) * range_scaler * decay_and_release_scaler;
	scaled_potentiometer_reading[2] = ((raw_potentiometer_reading[2] >> num_ADC_bits_to_ignore) * 1000) / (1 << num_effective_ADC_bits);
	scaled_potentiometer_reading[3] = pow((raw_potentiometer_reading[3] >> num_ADC_bits_to_ignore) + 1, exponent) * range_scaler * decay_and_release_scaler;

	if (adsr_range[1] == ADSR_RANGE_SHORT)
	{
		range_scaler = short_scaler;
	}
	else // ADSR 2 is in long range mode
	{
		range_scaler = long_scaler;
	}

	scaled_potentiometer_reading[4] = pow((raw_potentiometer_reading[4] >> num_ADC_bits_to_ignore) + 1, exponent) * range_scaler;
	scaled_potentiometer_reading[5] = pow((raw_potentiometer_reading[5] >> num_ADC_bits_to_ignore) + 1, exponent) * range_scaler * decay_and_release_scaler;
	scaled_potentiometer_reading[6] = ((raw_potentiometer_reading[6] >> num_ADC_bits_to_ignore) * 1000) / (1 << num_effective_ADC_bits);
	scaled_potentiometer_reading[7] = pow((raw_potentiometer_reading[7] >> num_ADC_bits_to_ignore) + 1, exponent) * range_scaler * decay_and_release_scaler;
}

void update_ADSR_inputs(void)
{
	for (int i = 0; i < (NUM_ADSR_INPUT_TYPES * NUM_ADSRs); ++i)
	{
		if (i < NUM_ADSR_INPUT_TYPES)
		{
			adsr[0].input[i] = scaled_potentiometer_reading[i];
		}
		else
		{
			adsr[1].input[i - NUM_ADSR_INPUT_TYPES] = scaled_potentiometer_reading[i];
		}
	}
}

void update_DACs(void)
{
	// scale the 32 bit ADSRs down to 12 bits and write them to the DACs
	HAL_DAC_SetValue(&hdac, DAC_CHANNEL_1, DAC_ALIGN_12B_R, adsr[0].current_value >> 20);
	HAL_DAC_SetValue(&hdac, DAC_CHANNEL_2, DAC_ALIGN_12B_R, adsr[1].current_value >> 20);
}

/* USER CODE END 4 */
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


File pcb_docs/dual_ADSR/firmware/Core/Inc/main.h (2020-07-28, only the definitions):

#define DEBUG_PIN_1_Pin GPIO_PIN_0
#define DEBUG_PIN_1_GPIO_Port GPIOC
#define DEBUG_PIN_2_Pin GPIO_PIN_1
#define DEBUG_PIN_2_GPIO_Port GPIOC
#define RANGE_1_Pin GPIO_PIN_3
#define RANGE_1_GPIO_Port GPIOC
#define ATTACK_1_Pin GPIO_PIN_0
#define ATTACK_1_GPIO_Port GPIOA
#define SUSTAIN_1_Pin GPIO_PIN_1
#define SUSTAIN_1_GPIO_Port GPIOA
#define DECAY_1_Pin GPIO_PIN_2
#define DECAY_1_GPIO_Port GPIOA
#define ATTACK_2_Pin GPIO_PIN_3
#define ATTACK_2_GPIO_Port GPIOA
#define RAW_ADSR_1_Pin GPIO_PIN_4
#define RAW_ADSR_1_GPIO_Port GPIOA
#define RAW_ADSR_2_Pin GPIO_PIN_5
#define RAW_ADSR_2_GPIO_Port GPIOA
#define RELEASE_1_Pin GPIO_PIN_6
#define RELEASE_1_GPIO_Port GPIOA
#define DECAY_2_Pin GPIO_PIN_7
#define DECAY_2_GPIO_Port GPIOA
#define SUSTAIN_2_Pin GPIO_PIN_0
#define SUSTAIN_2_GPIO_Port GPIOB
#define RELEASE_2_Pin GPIO_PIN_1
#define RELEASE_2_GPIO_Port GPIOB
#define TRIGGER_1_Pin GPIO_PIN_14
#define TRIGGER_1_GPIO_Port GPIOB
#define TRIGGER_2_Pin GPIO_PIN_15
#define TRIGGER_2_GPIO_Port GPIOB
#define RANGE_2_Pin GPIO_PIN_11
#define RANGE_2_GPIO_Port GPIOC
#define GATE_1_Pin GPIO_PIN_6
#define GATE_1_GPIO_Port GPIOB
#define GATE_2_Pin GPIO_PIN_7
#define GATE_2_GPIO_Port GPIOB

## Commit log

2020-06-19 slope gen progress, misc cleanup
    [power_supply.sch, slope_generator_1.sch, slope_generator_2.sch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]
2020-06-19 fix resistor on wrong side of pcb
    [wave_folder.kicad_pcb]
2020-06-19 add CEM3340 lpf plug-in board
    [BOM.ods, CEM3320_LPF_plug_in_board.kicad_pcb, CEM3320_LPF_plug_in_board.sch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]
2020-06-19 add note about mode resistor
    [power_and_vref.sch]
2020-06-19 add no-connects to MS20 VCF schematic
    [HPF.sch, LPF.sch]
2020-06-19 add +/- 5 volt ref to VCF carrier board
    [filter_carrier_board.kicad_pcb, filter_carrier_board.sch]
2020-06-21 make gerbers of most boards, add unfinished modulation source
    [HPF.sch, LPF.sch, VCO_core_components.sch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]
2020-06-21 add unfinished dual ADSR
    [connectors.sch, dual_ADSR.kicad_pcb, dual_ADSR.sch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]
2020-06-21 rearrange dual adsr dir
    [dual_ADSR.kicad_pcb, dual_ADSR.sch, gate_and_trigger_inputs.sch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]
2020-06-21 generate mod source gerbers
    [modulation_source-B_Cu.gbr, modulation_source-B_Mask.gbr, modulation_source-B_Paste.gbr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]
2020-06-21 generate adsr gerbers
    [dual_ADSR-B_Cu.gbr, dual_ADSR-B_Mask.gbr, dual_ADSR-B_Paste.gbr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]
2020-06-22 change modulation-source fm circuit, make new gerbers
    [modulation_source-B_Cu.gbr, modulation_source-B_Mask.gbr, modulation_source-B_Paste.gbr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]
2020-06-22 generate more gerbers
2020-06-23 add component values to ADSR LPFs
    [opamp_LPFs.sch]
2020-06-25 try out interactive BOM plugin
    [dual_ADSR.kicad_pcb]
2020-06-26 add values to pcb, regenerate BOM
    [dual_ADSR.kicad_pcb]
2020-06-26 generate BOMs for most boards
    [dual_MS20_VCF.kicad_pcb, dual_VCA.kicad_pcb, filter_carrier_board.kicad_pcb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]
2020-06-26 add gitignore for unnecessary kicad files
2020-06-26 fill in VCO r values, generate BOM
    [CEM3340_VCO.kicad_pcb, CEM3340_VCO.sch, Waveshapers.sch]
2020-06-26 add some missing resistor values
    [modulation_source.sch]
2020-07-01 fix pcb error, change some values
    [five_pulser_board-B_Cu.gbr, five_pulser_board-B_Mask.gbr, five_pulser_board-B_Paste.gbr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]
2020-07-01 mess around with 2164 lpf
    [CV_scaler.sch, feedback_VCA.sch, four_pole_lpf.kicad_pcb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]
2020-07-01 update pcb and BOM with correct values
    [sub_osc_board.kicad_pcb]
2020-07-05 scale pwm circuit and add power flags
    [five_pulser_board.kicad_pcb, five_pulser_board.sch]
2020-07-05 change FETs and cap values
    [sub_osc_1.sch, sub_osc_2.sch, sub_osc_board.kicad_pcb]
2020-07-06 update values to scale frequency and noise level
    [modulation_source.kicad_pcb, modulation_source.sch]
2020-07-06 change value to do-not-fit
    [sub_osc_board.sch]
2020-07-06 apply componet change to pcb
    [sub_osc_board.kicad_pcb]
2020-07-06 big directory change, update readme
    [BOM.ods, CEM3320_LPF_plug_in_board.kicad_pcb, CEM3320_LPF_plug_in_board.sch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]
2020-07-16 remove 2164 LPF board, may add it back in when it is complete
    [CV_scaler.sch, feedback_VCA.sch, four_pole_lpf.kicad_pcb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]
2020-07-17 change CEM3320 VCF BOM to new interactive stlye
    [BOM.ods, parts_list.ods]
2020-07-17 add CEM3320 VCF gerbers
    [CEM3320_LPF_plug_in_board-B_Cu.gbl, CEM3320_LPF_plug_in_board-B_Mask.gbs, CEM3320_LPF_plug_in_board-B_Paste.gbp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]
2020-07-17 change phasor BOM to new interactive style
    [BOM.ods, parts_list.ods]
2020-07-17 add optical phasor gerbers
    [optical_phasor_plug_in_board-B_Cu.gbr, optical_phasor_plug_in_board-B_Mask.gbr, optical_phasor_plug_in_board-B_Paste.gbr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]
2020-07-17 add rendered pics of wavefolder pcb
2020-07-17 add rendered pics of several pcbs
2020-07-20 small changes to wave folder CV bias and output level
    [folds_VCA.sch, output_amplifier.sch, wave_folder.kicad_pcb]
2020-07-21 change scaling resistors for manual cutoff controls
    [HPF.sch, LPF.sch, dual_MS20_VCF.kicad_pcb]
2020-07-21 fill in values for octave switch, add VCO carrier BOM
    [VCO_core_components.sch, oscillator_carrier_board.kicad_pcb]
2020-07-21 embiggen 5-pulser manual PW resistor
    [five_pulser_board.kicad_pcb, five_pulser_board.sch]
2020-07-22 generate VCA schematic
2020-07-22 add ms20 title block, generate ms20 schemo
    [HPF.sch, LPF.sch, dual_MS20_VCF.kicad_pcb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]
2020-07-22 add mod source title and schematic
    [modulation_source.kicad_pcb, modulation_source.sch]
2020-07-22 add 5-pulser title and schematic
    [five_pulser_board.kicad_pcb, five_pulser_board.sch]
2020-07-22 add title
    [dual_MS20_VCF.kicad_pcb, dual_MS20_VCF.sch]
2020-07-22 add several titles and schematics
    [bonus_ring_mod.sch, core.sch, folds_VCA.sch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]
2020-07-23 change sub-osc PWM range and mixer gain
    [sub_osc_1.sch, sub_osc_board.kicad_pcb, sub_osc_board.sch]
2020-07-23 update stm32 breakout readme
2020-07-23 remove outdated BOM infro from readme
2020-07-23 put all pcb docs in circuit_boards directory
    [CEM3320_LPF_plug_in_board-B_Cu.gbl, CEM3320_LPF_plug_in_board-B_Mask.gbs, CEM3320_LPF_plug_in_board-B_Paste.gbp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]
2020-07-24 change cap so noise biases quicker
    [modulation_source.kicad_pcb, modulation_source.sch]
2020-07-25 add schematic, fix BOM typo
2020-07-25 add title block, generate schematic
    [dual_ADSR.kicad_pcb, dual_ADSR.sch, gate_and_trigger_inputs.sch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]
2020-07-25 add title block and schematic
    [filter_carrier_board.kicad_pcb, filter_carrier_board.sch]
2020-07-25 add pcb_kludges document to user manuals
2020-07-25 rename pcb_docs directory
    [CEM3320_LPF_plug_in_board-B_Cu.gbl, CEM3320_LPF_plug_in_board-B_Mask.gbs, CEM3320_LPF_plug_in_board-B_Paste.gbp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]
2020-07-28 fix some ADSR code problems
    [f405_dual_ADSR.ioc, main.c, main.h]
2020-08-13 update CEM3320 VCF
    [CEM3320_LPF_plug_in_board-B_Cu.gbl, CEM3320_LPF_plug_in_board-B_Cu.gbr, CEM3320_LPF_plug_in_board-B_Mask.gbr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]

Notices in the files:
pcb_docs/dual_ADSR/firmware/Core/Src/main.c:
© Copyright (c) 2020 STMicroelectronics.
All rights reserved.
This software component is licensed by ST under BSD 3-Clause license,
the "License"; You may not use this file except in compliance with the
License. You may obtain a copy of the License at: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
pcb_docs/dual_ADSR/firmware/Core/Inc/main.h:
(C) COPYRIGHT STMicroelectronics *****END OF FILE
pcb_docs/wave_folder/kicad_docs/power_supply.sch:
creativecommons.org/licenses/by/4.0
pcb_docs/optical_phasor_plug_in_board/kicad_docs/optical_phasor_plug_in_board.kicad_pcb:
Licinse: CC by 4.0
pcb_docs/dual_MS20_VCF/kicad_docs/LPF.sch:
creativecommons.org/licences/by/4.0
